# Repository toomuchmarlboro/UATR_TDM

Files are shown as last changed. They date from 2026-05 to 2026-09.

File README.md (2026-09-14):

# UATR_TDM

**16-channel 24-bit underwater acoustic acquisition — 4× ADAU1978 → Cyclone IV E → LAN8720A → fiber → 7 km subsea → host PC**

Four of these boards form the deployed array: **64 channels**, beamformed on a
single host.

---

## Status — final

The design is complete and the firmware is frozen. `rtl/top_system.vhd` as
committed is the shipping configuration, and the eight flashable images in
`output_files/` were built from it by `build_all.sh`.

| | |
|---|---|
| **Shipping build** | `C_DECIMATE = true` — **24 kHz** output, 4× on-FPGA decimation |
| **Array addressing** | `192.168.3.101–104`, host `192.168.3.10`, ports 5005–5008 |
| **Phantom power** | `C_ENABLE_48V = true`, host-gated, watchdog available but off |
| **Fit** | 3,429 / 6,272 LE (55%), 2,610 registers, 8,290 memory bits, 0 multipliers |
| **Timing** | **TNS 0.000 on every corner**; worst setup +3.528 ns (`rmii_clk`), worst hold +0.439 ns |
| **Build consistency** | `python/check_sync.py` — **58 checks passed, 0 failed** |
| **Toolchain** | Quartus Prime 25.1std Lite, EP4CE6E22C8 |

**What is proven on hardware:** all 16 channels stream clean at 96 kHz/24-bit;
the Ethernet stack in both directions (~11,950 pkt/s, zero FPGA-side sequence
gaps, FCS and IP checksum confirmed in Wireshark); ADAU1978 I²C bring-up with
every register read back byte-exact; gain and 48 V control over UDP.

**What is proven numerically:** the 24 kHz decimator — bit-exact against a
scipy reference (`sim/decim_ref_vectors.txt`), 0.00015 dB passband ripple to
11 kHz, −102.5 dB worst alias band, and structurally clean through the fitter.
Per `docs/DECIMATOR_FINDINGS.md` §5 the decimating image had not yet been
captured on the bench at the time that record was written. **On the first
capture, read the packet rate first: ~3,000/s is success, ~12,000/s means
`valid_out` is being ignored downstream.**

---

## Quick start

```powershell
# 1. Host adapter — BOTH subnets, both required while any older board is in use
netsh interface ipv4 set address name="Ethernet" static 192.168.3.10 255.255.255.0
netsh interface ipv4 add address name="Ethernet" 192.168.1.10 255.255.255.0

# 2. Let the audio in
New-NetFirewallRule -DisplayName "TDM_UATR audio" -Direction Inbound `
    -Protocol UDP -LocalPort 5005-5008 -Action Allow -Profile Private
```

```
# 3. Flash each board with its own image — the IP is baked into the bitstream
output_files/24K_NODE1_192-168-3-101.jic   ->  board 1
output_files/24K_NODE2_192-168-3-102.jic   ->  board 2
output_files/24K_NODE3_192-168-3-103.jic   ->  board 3
output_files/24K_NODE4_192-168-3-104.jic   ->  board 4

# 4. Verify
python python/discover.py     # which boards, which subnet, which rate, loss
python python/imu_test.py     # the buoy telemetry side
python python/mixer_gui.py    # live meters, faders, 48 V
```

Full procedure, including the failure modes and what each message means:
**[docs/HOST_SETUP.md](docs/HOST_SETUP.md)**.

---

## Full system pipeline

```
SUBSEA ARRAY                   TOPSIDE FPGA BOARD              TOPSIDE NETWORK
────────────────               ─────────────────────           ───────────────
                               Altera Cyclone IV E
4× ADAU1978 ADC                (minimum system, IO pins only)
  Chip 0  ch  1– 4             ┌─────────────────────────┐
  Chip 1  ch  5– 8    TDM8─A──►│ tdm8_rx A → ch_data_A   │
  Chip 2  ch  9–12    TDM8─B──►│ tdm8_rx B → ch_data_B   │
  Chip 3  ch 13–16             │ tdm16_merge             │
                               │ decimator  (96k → 24k)  │
  All chips:                   │ packet_formatter        │
  BCLK  ◄────────────────────  │ udp_tx_core             │
  LRCLK ◄────────────────────  │ crc32 / arp_responder   │
  MCLK  ◄────────────────────  │ rmii_tx ────────────────┼──► LAN8720A module
                               └─────────────────────────┘    (RMII, 100 Mbps)
                                                                    │ RJ45
                                                            Media Converter
                                                            (BiDi WDM, 1310/1550 nm)
                                                                    │
                                                         ───────────┴───────────
                                                              7 km Hybrid
                                                           Armored Subsea Cable
                                                         ───────────┬───────────
                                                                    │
                                                            Media Converter
                                                            (matched BiDi pair)
                                                                    │ RJ45
                                                                    ▼
                                                                 Host PC
                                                          (Python UDP receiver)
```

---

## System parameters

| Parameter | Value |
|---|---|
| ADC | Analog Devices ADAU1978, 40-lead LFCSP |
| Chips | 4 |
| Total channels | 16 per board (4 per chip), 64 across the array |
| Resolution | 24-bit |
| **ADC sample rate** | **96 kHz — always, both image sets** |
| **Output sample rate** | **24 kHz** (`24K_*`, shipping) or 96 kHz (`96K_*`, fallback) |
| TDM architecture | 2× TDM8 — chip pairs share one SDATAOUT wire |
| Slot width | **32 BCLK per slot**, 24-bit data left-justified, 8 pad bits |
| BCLK | **24.576 MHz** (96k × 8 slots × 32 BCLK) |
| MCLK to ADAU1978 | **24.576 MHz** (256 × 96 kHz, MCS=011) — *same net as BCLK* |
| LRCLK | 96 kHz, 1-BCLK-wide pulse (LR_MODE=1) |
| FPGA | Altera Cyclone IV E, EP4CE6E22C8, minimum system board, IO pins only |
| Board oscillator | 50 MHz |
| Ethernet PHY | LAN8720A breakout module (RMII, 100 Mbps) |
| Payload rate | 9.216 Mbps at 24 kHz, 36.864 Mbps at 96 kHz (16 ch × 24 b × fs) |
| On the wire | 11.4 Mbps at 24 kHz, 45.7 Mbps at 96 kHz — one board |
| Fiber link | Single-mode, BiDi WDM, 20 km rated |
| Subsea cable | Hybrid (power + 8× SM fiber), 7 km |
| Subsea power | 24 V topside → 2.5 mm² copper → 9 V buck subsea |
| Language | VHDL only |

---

## Shipping firmware configuration

Compile-time constants in `rtl/top_system.vhd`, as committed. Every one is
documented in place with its reasoning — this table is the index, not the
explanation.

| Constant | Value | Effect |
|---|---|---|
| `C_NODE` | `1` | Board identity. Drives MAC, IP and UDP port together. `build_all.sh` sweeps it 1–4 |
| `C_DECIMATE` | **`true`** | 96 → 24 kHz decimator in the signal path. Wire format unchanged; only the rate |
| `C_ENABLE_48V` | **`true`** | Permits 48 V phantom. Still gated on the staged power-up timer *and* the host's runtime flag |
| `C_PHANTOM_WATCHDOG` | `false` | Off on purpose — enabling it makes a host keepalive mandatory. See below |
| `C_PHANTOM_TIMEOUT_S` | `120` | Watchdog period, if ever enabled |
| `C_I2C_SWAP` | `true` | Compensates a **schematic error** — net `SCL` lands on ADAU pin 17, which is SDA. Do not "fix" without fixing the copper |
| `C_LRCLK_RETIME` | `false` | LRCLK phase-shift path built but out of the signal path — the fault it chased was hardware |
| `C_LRCLK_PHASE_PS` | `25431` | Mirror of the PLL's `clk3_phase_shift`. **Does not set the phase** — the MegaWizard does |
| `C_BUFFER_EN_ACTIVE_HIGH` | `true` | LMK1C1104 `1G` polarity, confirmed against the datasheet |
| `C_LRCLK_TEST_50PCT` | `false` | Diagnostic: drives LRCLK as a slow square so a DMM can see it |
| `C_BCLK_TEST_SLOW` | `false` | Diagnostic: drives BCLK at ~0.27 Hz so clock-tree levels read as pure DC |
| `C_TDM2_FROM_TDM1` | `false` | Diagnostic, answered 2026-08-10 — PIN_119 and `u_rx_B` are good |

`rtl/adau_sequencer.vhd`

| Constant | Value | Effect |
|---|---|---|
| `C_SOFT_RESET_FIRST` | `true` | S_RST before configuring, so the FSM initialises with clocks already stable |
| `C_VERIFY_IDX` | `0` | Which ADC the register verify reads back (0=U19, 1=U20, 2=U37, 3=U38). One part per boot |

`rtl/tdm8_rx.vhd` / `rtl/tdm16_rx.vhd`

| Constant | Value | Effect |
|---|---|---|
| `C_BIT_ADJ` | `-1` | Capture-window offset in BCLK. **Found by measurement** (`udp_monitor.py --align`), not derived. Keep both files equal |
| `C_RAW_CAPTURE` | `false` | Ships raw TDM bits instead of audio, for `rawview.py` |

### The phantom-power watchdog

`C_PHANTOM_WATCHDOG` is a fail-safe, not a convention. The host is supposed to
turn 48 V off when it shuts down, which covers an orderly restart and nothing
else — if the app crashes, the cable is pulled, or the PC loses power, the
enable flag stays set inside the FPGA and 48 V stays live on the XLRs.

It is **off by default** because turning it on makes a host keepalive
mandatory: any host that sets phantom and then goes quiet sees 48 V drop
mid-capture, which during a real deployment is worse than the hazard it
prevents. Enable it only once the host actually sends keepalives, and flash all
four boards together. Details: [docs/PHANTOM_POWER.md](docs/PHANTOM_POWER.md).

---

## Building

```bash
./build_all.sh      # 8 images: 4 nodes x {24K decimating, 96K plain}
```

The script rewrites `C_NODE` and `C_DECIMATE` in `top_system.vhd`, compiles,
converts to `.jic`, and reports LE count and TNS per build. It takes a lock:
two concurrent runs corrupt each other, because both edit the same source file
and both write `output_files/TDM_UATR.sof` — which would produce an image
labelled for one board carrying another board's IP, the exact failure the
filename convention exists to prevent.

Images are named `{rate}_NODE{n}_{ip}.jic` so a board can never be flashed with
the wrong identity by accident.

> **A `.sof` is volatile.** Power-cycling boots the `.jic` in flash instead —
> usually an older build. Power-sequencing changes cannot be tested with a
> `.sof` at all.

---

## Clock and framing

The single most important constraint on this board, and the thing that cost the
most time to find.

### MCLK and BCLK are the same net

Each LMK1C1104 output feeds one ADC's **MCLKIN (pin 7)** *and* its **BCLK
(pin 16)** through two separate 49.9 Ω resistors:

```
U2-Y2 --+-- R13 --> MCLK_1 --> U19 pin 7
        +-- R14 --> BCLK_1 --> U19 pin 16
```

So MCLK and BCLK are physically one signal. That fixes the whole configuration,
because the MCS ratio must equal the BCLK ratio:

```
BCLK = 8 slots x SLOT_WIDTH x fS        (Table 10, TDM8)
MCLK = MCS_ratio x fS                   (Table 9)
MCLK = BCLK   =>   MCS_ratio = 8 x SLOT_WIDTH
```

### Which combinations are legal

Table 10 gives TDM8 three slot widths; Table 9 gives the MCS ratios available
at each standard rate. Only where they meet is a valid configuration:

| fS | 16-bit slots (128×) | 24-bit slots (192×) | 32-bit slots (256×) |
|---|---|---|---|
| 32 kHz | 4.096 MHz | — | 8.192 MHz |
| 44.1 kHz | 5.6448 MHz | — | 11.2896 MHz |
| 48 kHz | 6.144 MHz | — | 12.288 MHz |
| **96 kHz** | 12.288 MHz | 18.432 MHz | **24.576 MHz ← used** |
| 192 kHz | 24.576 MHz | 36.864 MHz | — |

### 24-BCLK slots do not work on this part

`SLOT_WIDTH=01` (24 BCLK) is listed as legal in Table 21, and at 96 kHz it gives
exactly 18.432 MHz — which is what the board was originally designed around.
**The ADAU1978 refuses it.** Correctly configured, PLL locked, every register
reading back byte-exact, and SDATAOUT never driven.

This is not documented anywhere in the datasheet. It was found by putting one
part into **master mode** (`SAI_MS=1`, with its BCLK and LRCLK resistors lifted
so it wasn't fighting the FPGA): given free rein, the part generated **32-BCLK
slots** and drove data immediately. Switching the FPGA to match fixed it.

Contributing reasons it cannot work:

- 24-bit data in a 24-BCLK slot leaves **no room** for the I²S one-BCLK delay,
  so `SDATA_FMT` must be left-justified (`01`) rather than I²S (`00`).
- Even with left-justified framing it still refuses. The slot width itself is
  the problem.

192 × fS was retested on hardware on 2026-08-11 and rejected again. 256 × fS
stands.

### The final numbers

```
PLL c2       = 50 MHz x 1536/3125 = 24.576000 MHz   exact
frame        = 8 slots x 32 BCLK  = 256 BCLK
fS           = 24.576 MHz / 256   = 96000.0 Hz
MCS=011      = 256 x fS           = 24.576 MHz      matches MCLK
data         = 24 bit, left-justified, 8 pad bits per slot
LRCLK        = 1 BCLK wide pulse, 40.7 ns, once per 10.42 us
```

`tdm8_rx.vhd` shifts 256 bits per frame and takes the **top 24 of every 32**,
discarding the pad bits.

### PLL configuration

Single ALTPLL instance (`ip/pll_audio`), all outputs exact from 50 MHz
(3125 = 5⁵ divides cleanly, so there is no rounding anywhere):

| Output | Ratio | Frequency | Gives |
|---|---|---|---|
| c0 | 768/3125 | 12.288 MHz | 48 kHz — **do not use**, kills U37/U38 |
| c1 | 1152/3125 | 18.432 MHz | 72 kHz — working fallback |
| **c2** | **1536/3125** | **24.576 MHz** | **96 kHz — shipping** |
| c3 | — | phase-shifted LRCLK | unused (`C_LRCLK_RETIME = false`) |

Changing the rate also means changing MCS (`0x01`) and FS (`0x05`) to match.

The Ethernet side is independent: `rmii_ref_clk` comes from the PHY at 50 MHz
and the two domains meet only through `async_fifo`, which the SDC declares
asynchronous. Lowering the audio rate reduces FIFO load, never increases it.

---

## Decimation and throughput

Two builds exist from the same source, differing only in `C_DECIMATE`.

**The packet never changes size — only how often one is sent.** Every packet
carries exactly 8 audio frames at either rate:

```
                          24 kHz (24K_*)   96 kHz (96K_*)
packets per second            3,000           12,000
bytes on the wire               476              476
```

Per board:

```
payload  16 ch x 24 bit x fs         9.216 Mbit/s    36.864 Mbit/s
+ 10 B packet header                 9.840           39.360
+ eth/IP/UDP + preamble/FCS/IFG     11.424          45.696     <- on the wire
of 100BASE-TX                         11.4%           45.7%
disk  16 x fs x 3 B                  1.15 MB/s        4.6 MB/s
                                      4.1 GB/hour    16.6 GB/hour
```

Four boards:

```
aggregate                           45.696 Mbit/s  182.784 Mbit/s
                                  fits 100BASE-TX  needs GIGABIT
```

The wire figure exceeds the audio because 66 bytes of framing ride on every
packet — 410 B payload inside 476 B on the link, 86% efficiency:

```
410 B payload + 8 UDP + 20 IPv4 + 14 Ethernet = 452 B frame body
      + 4 B FCS                               = 456 B transmitted
      + 8 B preamble/SFD + 12 B inter-frame gap = 476 B of link time
```

Because that overhead is **per packet**, sending 4× fewer packets saves it 4×
over too, so the wire rate scales by exactly 4.00.

### The filter

Two cascaded halfband FIR stages, 96k → 48k → 24k. Halfband because every even
tap except the centre is exactly zero (halves the multiplies), and linear phase
because the coefficients are symmetric (halves them again).

| | Stage 1 | Stage 2 |
|---|---|---|
| Length | 27 taps | 171 taps |
| Non-zero taps | 15 | 87 |
| Rate | 96k → 48k | 48k → 24k |

20-bit coefficients, 24-bit data, 45-bit accumulator. Measured on the quantised
cascade by `python/design_decimator.py`:

```
passband ripple 0-11 kHz   0.00015 dB
worst alias band          -102.5   dB   (below the ADC's 103 dB range)
group delay                 1.91   ms
```

**Why not a CIC**, which was the original brief: the band of interest is
10 Hz – 11 kHz, which is 92% of the 12 kHz Nyquist after a ÷4 — a brick-wall
requirement. A CIC N=3 droops **−9.2 dB** at 11 kHz and puts a 13 kHz folding
tone only 4.1 dB below the signal. Raising the order makes it *worse*, because
the first null is pinned at 24 kHz. Full reasoning:
[docs/DECIMATOR_FINDINGS.md](docs/DECIMATOR_FINDINGS.md).

**Which image to use:** `24K_*` unless you need content above 11 kHz. Inside
that band it costs nothing measurable and it removes the gigabit requirement,
cuts host CPU 4× and quarters the disk rate. `96K_*` for the full 0–42 kHz the
ADC passes, or as the fallback with the longer hardware history.

> The payload is **byte-identical** at both rates and nothing in the packet
> announces which it is, so a mismatch is **silent**: WAVs play at the wrong
> pitch and every duration is out by 4×. `discover.py` measures the rate from
> the packet rate rather than assuming it; `check_sync.py` asserts the host
> constant against the RTL.

---

## Network and packet format

### Addressing (static — no DHCP)

Everything derives from `C_NODE` in `top_system.vhd`:

```vhdl
FPGA_MAC  : x"DEADBEEF00" & C_NODE      -- DE:AD:BE:EF:00:0n
FPGA_IP   : 192.168.3.(100 + C_NODE)    -- .101 .102 .103 .104
PC_IP     : 192.168.3.10                -- C_PC_IP
UDP_PORT  : 5004 + C_NODE               -- 5005 5006 5007 5008
```

`C_PC_IP` is load-bearing twice over: it is the audio destination *and* the
filter deciding whose ARP the board will learn from. Changing only the board
addresses gives four boards transmitting into nothing.

**One port per board, deliberately.** Every host tool calls `recv()`, which
discards the sender, so four boards on one port would merge four independent
sequence-number streams into one socket. And on Windows two sockets may both
bind the same UDP port with `SO_REUSEADDR` while only **one** receives.

`C_PC_MAC` is a reset default, not a fixed value — it is overwritten by
whatever ARPs the board from `C_PC_IP`. So the deployment PC works from the
first packet with no ARP round trip, and moving the array to a different host
needs no reflash, just one packet in the board's direction.

> ⚠ **The host must hold BOTH `192.168.3.10` and `192.168.1.10`** while boards
> of either generation are in use. `C_PC_IP` is one value per image, so the host
> is the side that carries both. A board on the wrong subnet does not error —
> it transmits perfectly and the host kernel discards every frame before any
> socket sees it. See [docs/HOST_SETUP.md](docs/HOST_SETUP.md) and
> [docs/CHANGING_IP.md](docs/CHANGING_IP.md).

### UDP payload — 410 bytes

Produced by `packet_formatter.vhd`. `udp_monitor.py` is the single host-side
definition of this geometry; the other tools import it.

```
Bytes  0– 3   Magic  AD A1 97 78
Bytes  4– 7   Sequence number (uint32, big-endian)
Byte      8   dbg_byte0 — SDATA_A edge count per window
Byte      9   dbg_byte1 — SDATA_B edge count per window

then 8 frames of 50 bytes each:
  Byte  0     diagnostic status byte  (frame 0 -> dbg_status,
                                       frame 1 -> dbg_status2, ... frame 7 -> dbg_status8)
  Byte  1     frame index, 0-7
  Bytes 2–49  16 channels x 24-bit signed big-endian, channel 1 first

Total payload   10 + (8 x 50)                    = 410 bytes
IPv4 total len  20 IP + 8 UDP + 410              = 438
Ethernet frame  14 + 438 + 4 FCS                 = 456 bytes transmitted
```

> **Bytes 8–9 are not a frame count.** They once carried a constant `0x0008`
> that nothing read, then ADC register readbacks that were static after boot
> and covered one part only. They now carry the raw SDATA edge counters, which
> are live and cover both TDM lines. Likewise each frame's byte 0 was the
> frame-index MSB, always zero because the index never exceeds 7; it now
> carries the I²C and power status bits.

**Byte 60** — frame 1's byte 0, `dbg_status2` — is the phantom-power readback,
at a fixed offset in every packet:

| bit | mask | meaning |
|-----|---|---|
| 7 | `0x80` | marker — byte is populated. Clear = older bitstream, ignore the rest |
| 6 | `0x40` | `en_48v` as actually driven on the pin |
| 5 | `0x20` | the host asked for it (`udp_flags` bit 0) |
| 4 | `0x10` | staged power-up passed 1000 ms |
| 3 | `0x08` | this build permits it (`C_ENABLE_48V`) |
| 2:0 | | I²C self-test, unrelated |

`EN_48V` is an FPGA **output**. There is no sense line back from the 48 V
supply — a dead DC-DC, a blown fuse or an open enable trace still reads as ON.
Do not treat it as a rail measurement.

### Control protocol (host → FPGA)

`udp_rx_core.vhd` accepts a plain UDP datagram addressed to the board's IP.
**There is no port filtering** — any port works.

| Payload byte | Meaning |
|---|---|
| `[0]` | bits [3:2] ADC select 0–3, bits [1:0] channel select 0–3 |
| `[1]` | gain byte → register `0x0A`–`0x0D` of the selected part |
| `[2]` | *optional* control flags. **bit 0 = 48 V phantom enable** |

Gain encoding (Table 25): `0x00` = +60 dB, −0.375 dB per step, `0xA0` = 0 dB,
`0xFE` = −35.625 dB, `0xFF` = mute.

> **There is no flags-only packet.** The FPGA parses one command format, so
> every gain write also says something about phantom power. Whatever your app
> attaches to routine gain commands *is* what phantom power becomes — attach
> the board's own readback, not a default. `mixer_gui.py` does this in
> `flags()`, so a fader move is phantom-neutral.

```
python python/ctrl.py --test --channel 3     prove the receive path
python python/ctrl.py --set 3 -6             one channel to -6 dB
python python/ctrl.py --all 0                every channel to 0 dB
python python/ctrl.py --phantom status       decode byte 60
python python/mixer_gui.py                   live meters + faders + phantom
```

✅ **Verified on hardware 2026-08-09.** `ctrl.py --test --channel 1`: baseline
RMS 373 → mute 0.0 → restore 466. The FPGA parsed a UDP datagram from the PC
and wrote the gain register over I²C. Ethernet is proven in both directions.

---

## ADAU1978 configuration

### Register settings

Written by `adau_sequencer.vhd`. Every field is checked against the datasheet
by `check_sync.py` on each build.

| Reg | Value | Description |
|-----|---|---|
| 0x01 | `0x03` | PLL_MUTE=0, CLK_S=0 (MCLKIN), **MCS=011 = 256 × fS** (Table 9, fS=96 row) |
| 0x04 | `0x3F` | LR_POL=0, BCLKEDGE=0 (data on falling BCLK), LDO+VREF+all 4 ADCs enabled |
| 0x05 | `0x5B` | SDATA_FMT=01 (**left justified**), SAI=011 (TDM8), FS=011 (64–96 kHz) |
| 0x06 | `0x08` | SLOT_WIDTH=00 (**32 BCLK/slot**), DATA_WIDTH=0 (24 b), LR_MODE=1 (pulse), SAI_MS=0 (slave) |
| 0x07 | `0x10` | Chips 0, 2: ch1→slot1, ch2→slot2 |
| 0x07 | `0x54` | Chips 1, 3: ch1→slot5, ch2→slot6 |
| 0x08 | `0x32` | Chips 0, 2: ch3→slot3, ch4→slot4 |
| 0x08 | `0x76` | Chips 1, 3: ch3→slot7, ch4→slot8 |
| 0x09 | `0xF8` | All 4 ch drive enabled, DRV_HIZ=1 (unused slots high-Z) |
| 0x00 | `0x01` | PWUP=1 — **write last, only after PLL_LOCK bit = 1** |

### I²C addresses

| Chip | ADDR1 | ADDR0 | Address |
|---|---|---|---|
| 0 (U19) | 0 | 0 | 0x11 |
| 1 (U20) | 0 | 1 | 0x31 |
| 2 (U37) | 1 | 0 | 0x51 |
| 3 (U38) | 1 | 1 | 0x71 |

### Power-up sequence

```
1. Apply 3.3V AVDD. Hold PD/RST LOW.
2. Assert PD/RST HIGH -> internal LDO charges DVDD.
3. Wait ~5 ms (DVDD > 1.2V, POR releases, safe margin).
4. Apply stable 24.576 MHz MCLK (FPGA must be running).
5. Wait 15 ms for PLL to lock.
6. Poll register 0x01 bit 7 (PLL_LOCK) until = 1.
7. Write registers: 0x04, 0x05, 0x06, 0x07, 0x08, 0x09.
8. Settle 30 ms, then write register 0x00 = 0x01 (PWUP). LAST.
```

Boot is two-pass: configure everything, settle, then PWUP. The datasheet
requires PWUP be asserted ≥10 ms after DVDD > 1.2 V with stable clocks.

### Per-chip hardware requirements

- **PLL_FILT (pin 3):** 1 kΩ + 5.6 nF + 390 pF — mandatory
- **VREF (pin 2):** 100 nF + 10 µF to GND
- **DVDD (pin 10):** 100 nF + 10 µF MLCC X7R to GND
- **AVDD1/2/3:** 100 nF + 10 µF bulk per pin
- **Exposed pad (EP):** must be soldered to the PCB ground plane
- **IOVDD:** match to FPGA IO bank voltage (3.3 V)
- **47 kΩ pull-down** on each SDATAOUT line to GND

---

## Hardware details

### ADAU1978 chip pairing and slot assignment

```
Stream A wire:  Chip 0  ch  1– 4  → TDM slots 1–4
                Chip 1  ch  5– 8  → TDM slots 5–8

Stream B wire:  Chip 2  ch  9–12  → TDM slots 1–4
                Chip 3  ch 13–16  → TDM slots 5–8
```

```
FPGA output         Signal                Destination
───────────         ──────                ───────────
mclk_out            24.576 MHz            all 4× MCLKIN
bclk_out            24.576 MHz            all 4× BCLK
lrclk_out           96 kHz pulse          all 4× LRCLK

FPGA input          Source
──────────          ──────
sdata_in_A          Chip 0 SDATAOUT1 + Chip 1 SDATAOUT1  (47 kΩ pull-down)
sdata_in_B          Chip 2 SDATAOUT1 + Chip 3 SDATAOUT1  (47 kΩ pull-down)
```

### TDM frame structure

```
LRCLK:   |‾|__________________________________|‾|__
          1 BCLK wide pulse — marks start of slot 1

BCLK:    256 cycles per frame  (8 slots × 32 BCLK, 24-bit data + 8 pad bits)

sdata_in_A:
[Chip0 ch1:24b][Chip0 ch2:24b][Chip0 ch3:24b][Chip0 ch4:24b]  slots 1–4
[Chip1 ch1:24b][Chip1 ch2:24b][Chip1 ch3:24b][Chip1 ch4:24b]  slots 5–8

sdata_in_B: identical structure for Chips 2 and 3
```

- ADAU1978 outputs data on the **falling BCLK edge** (max 18 ns delay)
- FPGA samples on the **rising BCLK edge**
- LRCLK is *sampled* on the BCLK **rising** edge regardless of BCLKEDGE, so
  `tdm8_master` must **launch** it on the falling edge — asserted by `check_sync.py`
- Left-justified: first audio bit valid on the BCLK cycle after the LRCLK pulse

### Receiver output layout (per instance)

```
ch_data[191:168]  ch 1    ch_data[95:72]   ch 5
ch_data[167:144]  ch 2    ch_data[71:48]   ch 6
ch_data[143:120]  ch 3    ch_data[47:24]   ch 7
ch_data[119:96]   ch 4    ch_data[23:0]    ch 8
```

### LAN8720A module wiring

| Module Pin | Signal | Direction | Notes |
|---|---|---|---|
| VCC / GND | 3.3 V | — | Module power |
| RST# | `rmii_rst_n` | FPGA → PHY | Assert LOW at startup, release HIGH |
| MDC | `rmii_mdc` | FPGA → PHY | ~2.5 MHz management clock |
| MDIO | `rmii_mdio` | Bidirectional | 10 kΩ pull-up to 3.3 V |
| REF_CLK | `rmii_ref_clk` | PHY → FPGA | 50 MHz — see note |
| TXD0/TXD1 | `rmii_txd[1:0]` | FPGA → PHY | |
| TX_EN | `rmii_tx_en` | FPGA → PHY | |
| RXD0/RXD1 | `rmii_rxd[1:0]` | PHY → FPGA | Required — the control path uses them |
| CRS_DV | `rmii_crs_dv` | PHY → FPGA | |

> **REF_CLK note:** these modules carry an onboard 50 MHz crystal, and that is
> the clock the RMII domain runs on here. Check your specific module before
> wiring.

### Subsea cable and fiber link

| Parameter | Value |
|---|---|
| Cable type | Hybrid power + fiber, HDPE marine grade + aramid yarn |
| Conductors | 2× 2.5 mm² XLPE copper |
| Fiber count | 8× singlemode in stainless steel loose tube |
| Fiber used for data | 1 (BiDi WDM — single fiber, full duplex) |
| Cable OD | 18 mm ±0.5 mm |
| MBL | 1500 kg, working load 500 kg |
| Link budget at 7 km | ~3.45 dB loss, ~15 dB margin |

> **BiDi pair requirement:** the two converters must be a matched pair — one TX
> at 1310 nm, the other TX at 1550 nm. Verify before deployment.

### Subsea power delivery

```
2.5 mm² copper, 7 km round trip resistance = ~96.3 Ω
At 100 mA load: voltage drop = 9.63 V

Supply 24 V topside -> ~14.4 V arrives at the subsea end
Subsea: 9 V buck regulator (e.g. LM2596) powers the media converter
```

---

## Architecture decisions

**2× TDM8 rather than TDM16 or 4× TDM4.** TDM8 needs only two data wires and
gives symmetric 8-channel receivers. 4× TDM4 works and has the lowest BCLK but
wastes four input pins. TDM16 on one wire was built and tested
(`output_files/96K_TDM16.jic`) and **reverted**: timing analysis showed the
capture path was never the fault, so merging all four parts onto one net would
only have traded 24-bit samples for 16-bit. The procedure is kept in
[docs/TDM16_BRINGUP.md](docs/TDM16_BRINGUP.md) in case it is revisited.

**LAN8720A rather than W5100/W5500.** W5100 is SPI-based at max ~0.44 MB/s —
10× below what is needed. W5500 at ~10 MB/s is adequate but adds SPI overhead
and latency. LAN8720A speaks RMII directly to fabric with no intermediate
bottleneck.

**100 Mbps rather than gigabit.** With the decimator, one board offers
11.4 Mbit/s and the whole four-board array 45.7 Mbit/s — comfortably inside
100BASE-TX. Gigabit would require RGMII: more pins, harder timing, no benefit.

**UDP rather than TCP.** Audio is loss-tolerant and latency-sensitive. TCP
retransmits cause variable delay; a dropped UDP packet is one frame of missing
audio that the host detects from the sequence number.

**Fiber rather than copper at 7 km.** 100BASE-TX reaches 100 m. The subsea
cable already carries singlemode fiber and the converters are rated to 20 km.

**BiDi WDM rather than dual fiber.** TX and RX share one fiber at different
wavelengths, consuming one core of eight and leaving seven spare.

**GZIP compression in the FPGA was evaluated and rejected** — see
[HOST_DSP_PIPELINE.md](HOST_DSP_PIPELINE.md).

---

## Multi-board deployment and host DSP

The deployed array is **4 boards = 64 channels**, beamformed on a single host.
With the decimating build that is 45.7 Mbit/s aggregate and 12,000 pkt/s, which
fits 100BASE-TX; the 96 kHz build's 182.9 Mbit/s does not.

Host-side handling of the aggregate is specified in
**[HOST_DSP_PIPELINE.md](HOST_DSP_PIPELINE.md)**, including the
FLAC storage path and the **inter-board sample-alignment problem, which remains
open** — the four boards free-run from their own oscillators and nothing
currently disciplines them to a common timebase. `discover.py` flags mixed
sample rates for the same reason: each board is fine on its own and they are
not aligned to each other.

---

## Repository layout

```
rtl/        Synthesizable VHDL — everything in TDM_UATR.qsf's VHDL_FILE list
ip/         ALTPLL / FIFO IP cores, one directory per .qip (self-contained)
sim/        Testbenches, modelsim.ini, wave.do, decimator reference vectors
python/     Host-side tools (Python 3)
hardware/   Schematic PDF and KiCad netlist export
docs/       Findings and procedures, referenced from this README
db/, incremental_db/, output_files/   Quartus build output — gitignored
```

`TDM_UATR.qpf` / `.qsf` / `.sdc` stay at the repository root so the project
opens in Quartus by double-clicking the `.qpf`. Every source reference is a path
relative to the project root — no fixed drive letters.

### RTL

| File | Description |
|---|---|
| `top_system.vhd` | Top level. Clock/reset, staged power-up, I²C open-drain buffers, TX arbiter, all build-option constants |
| `tdm8_master.vhd` | Generates LRCLK (1 BCLK pulse @ 96 kHz) from 24.576 MHz |
| `tdm8_rx.vhd` | TDM8 receiver — 264-bit shift register (256-BCLK frame + `C_BIT_ADJ` slack), latch on LRCLK. Instantiated twice |
| `tdm16_merge.vhd` | Merges the two TDM8 streams into 16 channels |
| `tdm16_rx.vhd` | Single-net 16-slot receiver, built for the TDM16 experiment — not in the active path |
| `decimator.vhd` | Two-stage halfband FIR, 96 → 24 kHz, 16 channels time-multiplexed |
| `decim_coef_pkg.vhd` | Generated coefficients and tap indices — regenerate with `design_decimator.py` |
| `i2c_master.vhd` | I²C master. Bus recovery, probe mode, repeated-START reads |
| `adau_sequencer.vhd` | 128-address scan, soft reset, register boot, two-pass PWUP, live PLL poll, runtime gain writes |
| `crc32.vhd` | Ethernet FCS (0x04C11DB7) |
| `rmii_tx.vhd` / `rmii_rx.vhd` | RMII MAC — preamble, data, FCS, IFG |
| `udp_tx_core.vhd` | Ethernet + IP + UDP headers, 452-byte frame body |
| `udp_rx_core.vhd` | UDP receive path — gain and flags control |
| `arp_responder.vhd` | ARP replies, and learns the host MAC |
| `packet_formatter.vhd` | 10-byte header + 8 × 50-byte frames = 410-byte payload |
| `net_pkg.vhd` | Shared network constants |
| `ip/pll_audio` | ALTPLL: 50 MHz → 24.576 MHz |
| `ip/async_fifo` | Clock-domain crossing, 24.576 MHz → 50 MHz |

### Host tools (`python/`)

**Audio**

| File | Description |
|---|---|
| `discover.py` | **Start here.** Passive — finds every board, reports its real subnet, measured rate, and loss. Transmits nothing |
| `udp_monitor.py` | One-shot capture: link rate, loss, per-channel statistics, `--wav`, `--align`. The single definition of the packet geometry |
| `mixer_gui.py` | **Live tkinter mixer** — 16 meters, gain faders, mute, 48 V, telemetry tab, follows each board's real address |
| `mixer_gui_standalone.py` | The whole GUI in one file. **Generated — do not edit** |
| `make_gui_standalone.py` | Generates the above with `ast`. `--check` fails if it is stale |
| `mixer.py` | The same meters in the terminal |
| `ctrl.py` | Control protocol, phantom decode, and `--test` |
| `timeline.py` | Reports channel dropout windows over a capture |
| `rawview.py` | Decodes `tdm8_rx`'s raw-capture debug mode, bit for bit |

**Verification**

| File | Description |
|---|---|
| `check_sync.py` | Cross-checks the host constants against the RTL **and** the datasheet tables. 58 assertions — run on every build |
| `design_decimator.py` | Designs the filter, generates `decim_coef_pkg.vhd` and `sim/decim_ref_vectors.txt`, and reports ripple and alias rejection |
| `sim_chain.py` | Cycle-accurate model of the TDM chain, used to settle `C_BIT_ADJ` without a licensed simulator |
| `i2c_scan.py` | Decodes the boot-time I²C diagnostics: bus health, 128-address sweep, per-part table, register verify |

**Buoy telemetry**

| File | Description |
|---|---|
| `gdat2.py` | `$GDAT2` serial telemetry — see [docs/GDAT2_TELEMETRY.md](docs/GDAT2_TELEMETRY.md) |
| `witmotion.py` | WitMotion IMU/AHRS client |
| `ping1d.py` | Ping1D altimeter client |
| `altimeter_probe.py` | Altimeter bring-up probe |
| `imu_test.py` | Proves the AHRS is *live*, not merely present — catches an unchanging-constant or all-zero field map |
| `imu_standalone.py` | The same check as one self-contained stdlib file |
| `test_RMI.py` | Buoy integration test |

### Testbenches (`sim/`, not in the synthesis hierarchy)

| File | Description |
|---|---|
| `tb_tdm8_rx.vhd` | Known pattern, frame assertions |
| `tb_tdm16.vhd` | 16-channel merge |
| `tb_chain.vhd` | Full chain |
| `decim_ref_vectors.txt` | Bit-exact decimator reference output |

```
vlib work
vcom -modelsimini sim/modelsim.ini -work work -2002 rtl/tdm8_master.vhd rtl/tdm8_rx.vhd rtl/tdm16_merge.vhd sim/tb_tdm16.vhd
vsim -modelsimini sim/modelsim.ini -do sim/wave.do work.tb_tdm16
```

`-modelsimini sim/modelsim.ini` points at the tracked library mapping —
ModelSim otherwise resolves `modelsim.ini` from the current directory and
silently falls back to the install default.

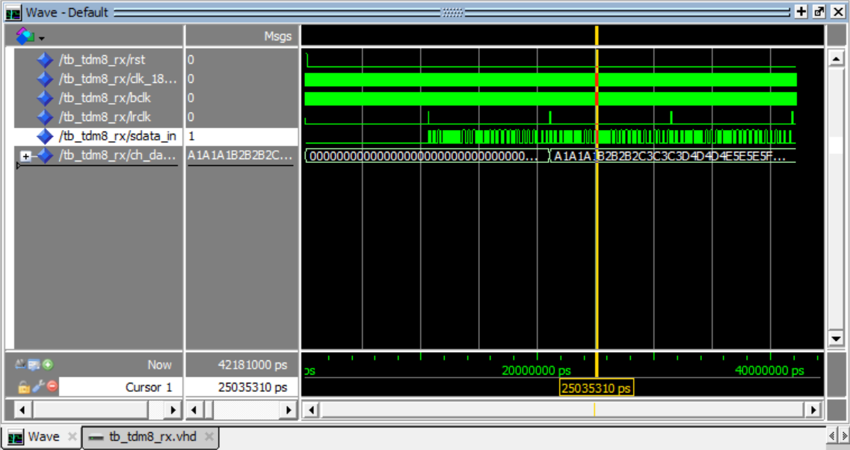
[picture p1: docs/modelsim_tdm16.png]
ModelSim TDM16 waveform


### Documentation (`docs/`)

**Procedures**

| File | Description |
|---|---|
| `HOST_SETUP.md` | **The complete host procedure** — adapter, firewall, which `.jic` to flash, verifying audio and telemetry |
| `DECIMATION.md` | The 96→24 kHz decimator, and the ADC gain budget that goes with it |
| `CHANGING_IP.md` | Changing the array's addressing — the four things that must agree |
| `NETWORK_SETUP.md` | Why the network is arranged this way: capacity, collisions, Python limits |

**Reference**

| File | Description |
|---|---|
| `ETHERNET_TRANSMISSION.md` | The UDP/IP/Ethernet transmit path end to end |
| `MULTI_BOARD.md` | Four-board deployment |
| `PHANTOM_POWER.md` | 48 V control, readback and the optional watchdog |
| `TELEMETRY_INTEGRATION.md` | The three buoy sensors and how to lift them into an app |
| `GDAT2_TELEMETRY.md` | `$GDAT2` field map, and the AHRS quantisation trap |

**Findings**

| File | Description |
|---|---|
| `DECIMATOR_FINDINGS.md` | Design decisions, and every bug found building the decimator |
| `TDM16_BRINGUP.md` | TDM16 procedure and why it was reverted |
| `LRCLK_HOLD_VIOLATION.md` | The ~4 ns LRCLK hold-spec violation |
| `LRCLK_PHASE_SHIFT.md` | The phase-shift investigation — intact but out of the signal path |
| `TDM2_NETLIST_FINDINGS.md` | Netlist trace of the LMK1C1104 buffer fan-out |

---

## Hardware bring-up log

Findings from bringing up the Souncard_Robomarine 1.0 PCB. Recorded because
none of it is derivable from the RTL. **All are resolved**; they are kept
because the next board revision needs them.

### Schematic errors

| Error | Impact | Resolution |
|---|---|---|
| **SDA/SCL crossed** — net `SCL` wires to ADAU pin 17 (really SDA), net `SDA` to pin 18 (really SCL). The KiCad symbol is correct; the wiring is not | I²C could never work as drawn | Compensated in firmware by `C_I2C_SWAP = true`. **Fix the copper in the next revision** |
| **OPA1671 on +15 V** — U44–U47 (VREF→VCOM buffers) have V+ on +15 V against a **6 V absolute maximum** | Destroyed all four. Their damaged inputs clamped VREF to 0–0.8 V on every ADC and loaded the ±15 V rail | **Removed, not replaced.** OPA1632 `VOCM` self-biases to mid-rail, which is correct on ±15 V, and the ADC inputs are AC-coupled — the buffers were never needed. **Delete them in the next revision** |
| **PLL loop filter returns to GND**, not AVDD2 as Table 8 requires | None observed | Disproven as a fault — U19/U37 lock with the GND return. Component values are correct |
| **Both LMK1C1104 clock buffers (U1, U2) damaged** | Their inputs loaded the FPGA's 3.3 V outputs to 2.0 V and their outputs produced 0.9 V and millivolts. The ADAU1978 needs VIH = 0.7 × IOVDD = 2.31 V, so the ADCs never saw a valid clock and left SDATAOUT high-Z | Replaced. Can also be bypassed by bridging pin 1 to pins 3/5/7/8 on each footprint — the FPGA drives these loads directly; the 49.9 Ω series resistors stay |
| **Misplaced DVDD decoupling cap, and a dead U37** | The intermittent ADC3/ADC4 channel dropouts | Fixed in hardware. All 16 channels now run clean |

### Firmware bugs

- **`i2c_master.vhd`** — `ena` was sampled only on quarter-bit boundaries while
  the sequencer pulsed it for one cycle, so the pulse was missed ~99% of the
  time. **No I²C transaction had ever run.**
- **`crc32.vhd`** — 7 of the 32 XOR equations (bits 10, 11, 12, 16, 17, 22, 23)
  carried spurious terms, so every frame left with a garbage FCS and the host
  NIC discarded all of it silently. **Root cause of the original "Ethernet
  dead" fault.** Verified after the fix: `"123456789"` → `0x649C2FD3`, RX
  residue `0xC704DD7B`.
- **False PLL-lock reporting** — `i2c_master` pre-loads `data_rd` with `0xFF`
  to invalidate aborted reads. The live poll took bit 7 of that blindly, so a
  *failed* read reported `PLL_LOCK = 1`. It reported four locked PLLs on a
  board whose MCLK never arrived.
- **TDM framing** — the merge fired 128×/frame, and LRCLK was launched on the
  ADC's own sampling edge.
- **Scan abort** — the address sweep stopped at 9 answers, collapsing "hard
  stuck-low SDA" (128 answers) and "a few glitched bits" (9) onto one number.
  It now always sweeps all 128.
- **Decimator pipeline misalignment** — survived one round of "bit-exact"
  verification because the model encoded the *intent* rather than the written
  VHDL. Caught only by a cycle-accurate model following VHDL signal semantics.

### Measurement traps

- **LRCLK is a 54 ns pulse at 96 kHz** — 0.5% duty, so a *working* LRCLK reads
  **~17 mV** on a multimeter. Use `C_LRCLK_TEST_50PCT`, or a scope.
- **24 MHz on a handheld DMM** reads as a meaningless fraction of a volt.
  MCLK/BCLK cannot be checked with a meter at all. Use `C_BCLK_TEST_SLOW`.
- **Scope frequency counters quantise.** An 18.432 MHz clock (54.25 ns) on a
  100 MSa/s timebase alternates between "20 MHz" and "16.6 MHz". Both readings
  are the same correct clock.
- **Resistance to GND across bulk capacitance is meaningless** — the meter
  charges the cap and the reading climbs. A rail also reads "shorted" on a
  continuity beeper because of the substrate diodes in every IC on it; reverse
  the probes and the asymmetry gives it away.

### Standing lessons

1. **Model what you wrote, not what you meant.**
2. **A passing check may be checking nothing** — two `check_sync.py` guards had
   been green for weeks while matching no text at all.
3. **Cheap in one resource is expensive in another** — padding a RAM depth cost
   zero LEs and broke the fit on memory blocks.
4. **Generated files must be executed, not just generated.**
5. **Never `git checkout` a file mid-session to reset unrelated state.**

---

## Minimal host receiver

```python
import socket, struct

MAGIC = b'\xAD\xA1\x97\x78'
sock  = socket.socket(socket.AF_INET, socket.SOCK_DGRAM)
sock.bind(("0.0.0.0", 5005))                 # 5004 + C_NODE
sock.setsockopt(socket.SOL_SOCKET, socket.SO_RCVBUF, 4 * 1024 * 1024)

prev_seq = None
while True:
    data, _ = sock.recvfrom(65535)
    if len(data) != 410 or data[0:4] != MAGIC:
        continue
    seq = struct.unpack(">I", data[4:8])[0]
    if prev_seq is not None and seq != prev_seq + 1:
        print("WARNING: %d packet(s) dropped" % (seq - prev_seq - 1))
    prev_seq = seq

    phantom_on = bool(data[60] & 0x40) if data[60] & 0x80 else None

    offset = 10
    for f in range(8):                        # 8 frames per packet, both rates
        samples = [int.from_bytes(data[offset+2+i*3 : offset+5+i*3],
                                  'big', signed=True) for i in range(16)]
        offset += 50
        # samples[0..15] = ch1..ch16
```

---

## Constraints

- VHDL only — no Verilog or SystemVerilog
- Cyclone IV E only — no Cyclone V or later features
- `rtl/top_system.vhd` is the only top level
- `rtl/tdm8_rx.vhd` is complete and instantiated twice — do not rewrite
- All FPGA IO pins are 3.3 V — the LAN8720A IOVCC must also be 3.3 V
- UDP checksum is 0x0000 (valid per RFC 768)
- The sample rate is **not** announced in the packet. Any tool that assumes it
  must be told, and `check_sync.py` must be run after flashing a different image

---

## License

MIT — see [LICENSE](LICENSE). Copyright (c) 2026 Faiz Akbar Parinduri, S.T.

This covers the VHDL in `rtl/`, the host tools in `python/`, the testbenches in
`sim/`, and the documentation. It does **not** cover third-party material
redistributed here for convenience:

- `ip/pll_audio` and `ip/async_fifo` are Altera/Intel megafunction output,
  governed by the Quartus Prime license under which they were generated
- `docs/adau1978.pdf` is the Analog Devices datasheet, © Analog Devices
- `hardware/` contains the Souncard_Robomarine 1.0 schematic and netlist

---

*Analog Devices ADAU1978 Rev B. Microchip LAN8720A. Altera Cyclone IV E
EP4CE6E22C8. Built with Quartus Prime 25.1std Lite.*

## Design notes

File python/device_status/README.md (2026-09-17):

# Device Status — vendored from HACAR_dash

HACAR_dash's Device Status window, copied whole into this repo so the valve
control can be added to it. PySide6, which is a third GUI toolkit here
alongside `mixer_gui.py` (tkinter) and `Host_RMI.py` (PyQt5).

```powershell
python run.py                    # all tabs, live services
python run.py --no-services      # the bare window, opens no sockets
python run.py --db bench.sqlite  # a settings database of your own
```

## What is here

| | |
|---|---|
| `supersilence/` | **Vendored. Do not edit.** 78 files, ~14,700 lines |
| `vendor.py` | Copies that tree out of HACAR_dash, and checks it is current |
| `run.py` | Composes the services and opens the window, mirroring `app/main.py` |

## The tabs

- **Buoys** — the AFE pages. One sub-tab per unit (T1–T4), each carrying
  sixteen channel meters, gain faders, channel enable and polarity, and the
  48 V phantom control.
- **Telemetry** — decoded `$GDAT2` fields per unit, link statistics, compass
  and horizon.
- **Pipeline** — needs a `target_provider`, which is the console's
  direction-finding stack. Not vendored, so this tab never appears here.

A tab is built only when the service behind it exists. That is the window's own
design, and deliberate — its comment reads *"a tab of ten dashes says a field
map is broken when the truth is that telemetry is switched off"*. `--no-services`
therefore shows "No acquisition or telemetry service is running.", which is the
window working, not a fault.

## Keeping the copy honest

`supersilence/` is generated, for the same reason `mixer_gui_standalone.py` is:
a hand-maintained copy of another project's source drifts silently — the window
still opens, still paints, and still shows numbers, just not the ones the other
repo now produces.

```powershell
python vendor.py            # refresh from HACAR_dash
python vendor.py --check    # exit 1 if stale, and name the files
python vendor.py --list     # what is in the closure, and how big
```

The source defaults to `../../../HACAR_dash/src` — a sibling checkout — and is
overridden with `--src` or `$SUPERSILENCE_SRC`. `--check` passes quietly when the
source is absent, so this repo stays buildable on a machine that has never had
HACAR_dash on it.

### What gets copied

The transitive import closure of four seeds, computed with `ast` rather than
swept up by a wildcard: the `device_status` feature, the acquisition factory,
the telemetry service, the settings repository, the SQLite schema and the
phantom-power command path. Nothing else from that repo comes along.

Package paths are preserved, so every `from supersilence.… import …` inside the
copied files is left exactly as written. That is why `run.py` puts its own
directory on `sys.path` and why the tree is not flattened the way the mixer GUI
is flattened.

## Addresses

These are **HACAR_dash's** defaults, not this array's. Its acquisition sources
and the `192.168.3.101–104` boards in `ctrl.py` are configured independently,
and nothing here rewrites one to match the other — a window that silently
retargeted the addresses in its own database would be the least debuggable
thing in either repo. Set them in the settings database, or point `--db` at one
that already holds them.

Telemetry also ships disabled: `default_telemetry_configuration()` has
`enabled=False`, so a fresh database connects to nothing until you turn it on.

## Next

The valve control goes on the Buoys page beside the 48 V control — the one
other place this window reaches past a service and into hardware. The command
itself already exists in this repo as `gdat2.rmcmd`, with `RMCMD_OPEN = 5` and
`RMCMD_CLOSE = 1`.

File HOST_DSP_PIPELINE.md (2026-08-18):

# Host DSP Pipeline — Decimate /4 + FLAC

**Status (2026-08-16): design agreed, not yet implemented.**

Reduces the 4-AFE aggregate stream from 70.8 GB/hr to ~9 GB/hr and cuts beamforming
cost 4×, entirely on the host. **No RTL, no PLL, no ADAU1978 register changes.**

---

## The Problem

Four AFEs, each 16 ch × 96 kHz × 24-bit, feeding one Python beamformer.

| | Per AFE | ×4 aggregate |
|---|---|---|
| Wire rate | 45.7 Mbps | 182.9 Mbps = **22.9 MB/s** |
| UDP payload | 4.9 MB/s | 19.7 MB/s |
| Audio samples | 4.6 MB/s | **18.4 MB/s** |
| Packet rate | 12,000 pkt/s | **48,000 pkt/s** |
| Storage | 17.7 GB/hr | **70.8 GB/hr** (566 GB / 8 hr) |

Note the units: **46 Mbps per AFE, not MB/s**. At 22.9 MB/s aggregate, a 1 GbE server
port sits at 18% and any SSD is bored. Neither network nor disk *bandwidth* is the
bottleneck. The two real constraints are **host CPU** and **storage capacity**.

---

## Architecture Decisions Log

### Why not the FPGA-Gzip-compressor core

Evaluated [WangXuan95/FPGA-Gzip-compressor](https://github.com/WangXuan95/FPGA-Gzip-compressor)
and rejected on three independent grounds.

**1. It does not fit EP4CE6E22C8.** Published cost is 8,218 LUT6 + 25×BRAM36K on
Artix-7. Our device has 6,272 LE and 276,480 memory bits, with `TDM_UATR.fit.summary`
already showing 3,890 LE (62%) used — about 2,380 LE free. Ignoring Xilinx block
quantization and counting only irreducible storage:

| Item | Bits | % of device M9K pool |
|---|---|---|
| LZ77 window (16,383 B) | 131,064 | 47% |
| Hash table (4,096 entries) | ~57,000 | 21% |
| Deflate block buffer | 131,064 | 47% |
| **Total** | | **~115%** |

Over 100% of all device RAM before the existing 8,688 bits. Logic is worse: 8,218 LUT6
maps to roughly 12k–18k Cyclone IV 4-LUTs against 2,380 free. Off by 3–7×, not a tuning
margin. (Throughput was never the issue — 128 MB/s vs the 4.6 MB/s needed.)

**2. It would break the TX path.** `udp_tx_core.vhd:59` — `IP_CHECKSUM` is a
compile-time constant *precisely because* the length is fixed at 438. Variable-length
output makes IP total-length, UDP length and the checksum runtime logic, and invalidates
`PAYLOAD_BYTES := 410` and the `byte_cnt = TOTAL_BYTES` terminator.

**3. It is the wrong operation for the problem.** See below.

### Why decimation and not compression alone

Compressed data cannot be beamformed. It must be inflated back to 96 kHz × 64 ch first,
at which point the beamformer sees the identical array it sees today — same FFTs, same
delay-and-sum, same cost, plus the decode.

| | Compression (FLAC) | Decimation /4 |
|---|---|---|
| What is removed | statistical redundancy | the 12–48 kHz band |
| Reversible | yes, exactly | **no, never** |
| Output directly usable | no — must decode | yes — plain PCM |
| Reduces storage | yes | yes |
| **Reduces beamform CPU** | **no — adds decode cost** | **yes, exactly 4×** |
| Ratio | data-dependent | exactly 4×, guaranteed |

Beamforming cost scales as `N_samples × N_channels × N_beams`. Compression changes none
of those three. Decimation cuts the first by 4.

**They are orthogonal and compose.** Decimate first, then compress the result — low-pass
filtering raises sample-to-sample correlation, so FLAC's linear predictor typically does
*better* on decimated data than on the original.

| Approach | Storage | Beamform CPU |
|---|---|---|
| Now | 70.8 GB/hr | 1× |
| FLAC only | ~35 GB/hr | 1× + decode |
| Decimate /4 only | 17.7 GB/hr | 0.25× |
| **Decimate /4, then FLAC** | **~9 GB/hr** | **0.25×** |

### Why /4 and not some other factor

Advisor guidance was 22 kHz *frekuensi sampling* (sampling frequency, i.e. ~11 kHz of
usable band) for speech-band work. 96/22 is not an integer and fractional resampling is
far more expensive than integer, so:

| Decimate | Fs | Usable band | Reduction |
|---|---|---|---|
| /2 | 48 kHz | 24 kHz | 2× |
| /3 | 32 kHz | 16 kHz | 3× |
| **/4** | **24 kHz** | **12 kHz** | **4×** |
| /6 | 16 kHz | 8 kHz | 6× |

/4 gives 12 kHz of band — slightly more headroom than the 11 kHz asked for — on a clean
integer divisor.

Spatial-aliasing cross-check: for a 12 kHz band, `d ≤ c/(2·f_max) = 1500/24000 = 6.25 cm`
element spacing. **If hydrophone spacing ≤ 6.25 cm, /4 costs nothing usable.** If spacing
is wider, the array was already the limiting factor and the stream can be decimated
harder. *This has not been confirmed — see Open Items.*

### Why on the host and not in the FPGA

A time-multiplexed FIR decimator would fit (a few hundred LE, and there are 256 BCLKs per
audio frame at 24.576 MHz = 16 cycles per channel per sample). It would also cut network
and packet rate, which the host version does not.

It is still the wrong place to start. The clock tree on this board is demonstrably fussy:
commit `a4ba519` records 192×fS (18.432 MHz) *rejected on hardware*, and `tdm8_rx.vhd:27`
records the part reading `PLL_LOCK=0` at 18.4332 MHz while all four locked at 24.576 MHz.
Host-side decimation delivers 4× on both stated problems while `clk_18m` stays bolted to
PLL tap c2 and `adau_sequencer` never sees a changed MCS value.

Revisit the FPGA decimator only if packet rate or link load becomes the binding
constraint. It is not today.

### Naming hazard

`clk_18m` in `top_system.vhd` **carries 24.576 MHz**, not 18.432 MHz. It is wired to PLL
output c2 (`top_system.vhd:923-925`); the 18.432 MHz tap c1 is `open`. The name is legacy
from before 192×fS was rejected. Renaming it to `clk_bclk` or `clk_24m576` is a mechanical
change and would stop this recurring.

---

## Pipeline

```
  4× AFE (UDP :5005)                HOST
  ──────────────────                ────
  16 ch @ 96 kHz 24-bit
  12,000 pkt/s each      ┌──────────────────────────────────┐
        │                │ 1. INGEST (one process per AFE)  │
        ├───────────────►│    vectorized parse, seq-gap     │
        │                │    detect + zero-fill            │
        │                └───────────────┬──────────────────┘
        │                                │ (n,16) int32 @ 96 kHz
        │                ┌───────────────▼──────────────────┐
        │                │ 2. INTER-AFE ALIGNMENT           │
        │                │    MUST be at 96 kHz — see below │
        │                └───────────────┬──────────────────┘
        │                                │ aligned, 64 ch @ 96 kHz
        │                ┌───────────────▼──────────────────┐
        │                │ 3. ANTI-ALIAS FIR + /4 SUBSAMPLE │
        │                │    stateful, block-continuous    │
        │                │    one Decimator per AFE         │
        │                └───────────────┬──────────────────┘
        │                                │ (n/4,16) int32 @ 24 kHz
        │                     ┌──────────┴──────────┐
        │                     ▼                     ▼
        │          ┌────────────────────┐  ┌──────────────────┐
        │          │ 4a. BEAMFORMER     │  │ 4b. FLAC WRITER  │
        └─────────►│     64 ch working  │  │  8 files × 8 ch  │
                   │     set, 0.25× CPU │  │  ~9 GB/hr total  │
                   └────────────────────┘  └──────────────────┘
```

---

## Stage 1 — Ingest

**This is the current bottleneck and must be fixed first, independently of decimation.**

`udp_monitor.py:97-105` decodes with a nested Python loop calling `int.from_bytes` once
per sample: 48,000 pkt/s × 128 samples = **6.1M calls/s**, plus 48,000 `recv()` syscalls/s.
That cannot keep up at any data rate.

The correct vectorized pattern **already exists in this repo** at `mixer.py:78-83`:

```python
def decode(payload):
    """Payload bytes -> (frames, 16) int32."""
    body = payload[um.HDR_LEN:]
    n = len(body) // um.FRAME_LEN
    if n == 0:
        return None
    raw = np.frombuffer(body[:n * um.FRAME_LEN], dtype=np.uint8)
    raw = raw.reshape(n, um.FRAME_LEN)[:, 2:]          # drop debug + frame index
    raw = raw.reshape(n, um.CHANNELS, um.SAMPLE_BYTES).astype(np.int32)
    v = (raw[:, :, 0] << 16) | (raw[:, :, 1] << 8) | raw[:, :, 2]
    return np.where(v & 0x800000, v - 0x1000000, v)
```

Port this into the record/beamform path. Expect 50–100× on the parse.

**Syscall side:** `recvmmsg` is not in Python's stdlib `socket`, so the practical levers
are (a) one receiver process per AFE, and (b) larger packets in the FPGA. Raising
`packet_formatter` from 8 to 29 frames/packet (1460 B payload, still inside MTU) cuts
48,000 → 13,240 pkt/s. That is a small, well-understood RTL change and is worth more here
than its ~8% wire saving. Optional; not required for this pipeline.

**Sequence gaps are mandatory to handle.** Header bytes 4–7 carry `seq_num`
(`packet_formatter.vhd:90-93`). A dropped packet must be **zero-filled, not skipped** — a
skipped packet shifts every subsequent sample by 8 frames, which silently destroys both
the decimation phase and inter-channel beamforming alignment. Log gap count and location.

---

## Stage 2 — Inter-AFE alignment (must precede decimation)

The four AFEs run independent `pll_audio` instances from independent crystals, so their
sample grids drift relative to each other. Beamforming across AFEs requires them aligned
to a common grid.

**This stage must run at 96 kHz, before decimation.** The alignment granularity available
from integer sample shifts collapses when you decimate:

| Rate | 1 sample | Apparent element position error @ 1500 m/s |
|---|---|---|
| 96 kHz | 10.4 µs | **1.6 cm** |
| 24 kHz | 41.7 µs | **6.25 cm** — the entire assumed element spacing |

At 24 kHz a single-sample shift is as large as the array spacing the /4 decision was
justified against, so after decimation the AFEs **cannot be aligned by integer shifts at
all** — recovering what one sample buys at 96 kHz would require fractional-delay
interpolation. Align first, then decimate.

Consequence for stage 3: each AFE gets **its own `Decimator` instance**, fed from an
already-aligned stream. The class below is sized per channel count, not per AFE.

The alignment mechanism itself is unresolved — see Open Item 4. It is the one item on
this page that can invalidate the beamformer regardless of how well the DSP works.

---

## Stage 3 — Anti-alias filter and /4 subsample

### The filter is not optional

Naïve `x[::4]` folds everything between 12 kHz and 48 kHz back into the retained band as
false signal that is indistinguishable from real targets. The stream **must** be low-passed
below the new 12 kHz Nyquist first.

### Specification

| Parameter | Value | Rationale |
|---|---|---|
| Input Fs | 96,000 Hz | unchanged from ADC |
| Output Fs | 24,000 Hz | |
| Passband | 0 – 10,000 Hz | |
| Stopband | 12,000 Hz | new Nyquist |
| Stopband atten. | ≥ 100 dB | below the ~102 dB ADAU1978 DR floor |
| Phase | linear (FIR) | preserves inter-channel timing — **required for beamforming** |

**Use FIR, not IIR.** An IIR low-pass has non-linear phase, which applies a
frequency-dependent delay. Across a beamforming array that is indistinguishable from a
position error and will smear the beam pattern.

### Streaming structure

Block-based `resample_poly` / `decimate` calls do **not** maintain filter state, so each
block boundary injects a discontinuity. For a continuous recording that is unacceptable.
Carry state explicitly:

```python
from scipy.signal import firwin, lfilter
import numpy as np

DECIM   = 4
FS_IN   = 96000
FS_OUT  = FS_IN // DECIM          # 24000
NTAPS   = 321                     # odd -> integer group delay

# Kaiser-windowed FIR, ~100 dB stopband, 10 kHz -> 12 kHz transition.
# beta = 0.1102*(A - 8.7) = 10.06 for A = 100 dB; cutoff is the -6 dB point,
# i.e. the centre of the transition band. NTAPS from (A-8)/(2.285*dw) = 308 -> 321.
FIR = firwin(NTAPS, cutoff=11000, fs=FS_IN, window=('kaiser', 10.06))

class Decimator:
    """Stateful /4 with anti-alias FIR. Block-continuous, no edge artifacts."""
    def __init__(self, n_ch, taps=FIR, decim=DECIM):
        self.b = taps
        self.decim = decim
        self.zi = np.zeros((len(taps) - 1, n_ch))
        self.phase = 0                       # subsample phase across blocks

    def __call__(self, x):                   # x: (n, n_ch) float64
        y, self.zi = lfilter(self.b, 1.0, x, axis=0, zi=self.zi)
        out = y[self.phase::self.decim]
        # keep phase continuous into the next block
        self.phase = (self.phase - len(x)) % self.decim
        return out
```

`self.phase` is what makes this correct across blocks — without it, a block whose length
is not a multiple of 4 shifts the decimation grid and the channels drift apart.

### Cost, and the optimization if it does not keep up

Single-stage `lfilter` computes every input sample then discards 3 of 4:
`321 taps × 64 ch × 96,000 = 1.97 GMAC/s`. That is likely too slow for single-threaded
scipy. **Benchmark before assuming it works.**

If it does not, use a **two-stage halfband cascade** (/2 at 96 kHz, then /2 at 48 kHz).
Halfband filters have every other tap zero, and the second stage runs at half rate:

| Stage | Rate | Taps | Effective MAC/s (64 ch) |
|---|---|---|---|
| 1 (/2) | 96 kHz | 63 (32 non-zero) | ~98 M |
| 2 (/2) | 48 kHz | 63 (32 non-zero) | ~49 M |
| **Total** | | | **~150 M** — 13× cheaper |

Combined with polyphase evaluation (compute only retained outputs, via `upfirdn` with
manual state), this comfortably fits one core per AFE.

### Back to integer — do not skip the clip

`lfilter` returns float64; FLAC needs integers. A 321-tap FIR has passband ripple and can
overshoot a full-scale input past ±(2²³−1). An unchecked `.astype(np.int32)` truncates
toward zero and, worse, wraps silently on overflow — a full-scale positive peak becomes a
large negative sample. Clip explicitly:

```python
out = np.clip(np.rint(y_float), -(1 << 23), (1 << 23) - 1).astype(np.int32)
```

`np.rint` (round-half-even) rather than a bare cast, so the decimated stream is not biased
toward zero by up to 1 LSB on every sample.

---

## Stage 4b — FLAC writer

### Channel count constraint

**FLAC's format caps at 8 channels.** libFLAC, libsndfile and `soundfile` all enforce it.
64 channels cannot go in one file.

Natural split — **8 files of 8 channels**, two per AFE, matching the existing `tdm8_rx`
A/B halves and the ADAU1978 chip pairing in the README:

| File | AFE | Channels | Source |
|---|---|---|---|
| `afe0_A.flac` | 0 | 1–8 | `ch_data_A` (chips 0,1) |
| `afe0_B.flac` | 0 | 9–16 | `ch_data_B` (chips 2,3) |
| … | | | |
| `afe3_B.flac` | 3 | 9–16 | `ch_data_B` (chips 2,3) |

This keeps a file boundary on a boundary that already exists in the hardware.

### Settings

| Parameter | Value |
|---|---|
| Sample rate | 24,000 Hz |
| Bit depth | 24-bit (`PCM_24`) |
| Channels | 8 per file |
| Compression level | 5 (default) — level 8 costs much more CPU for ~1% |

```python
import soundfile as sf

w = sf.SoundFile(path, mode='w', samplerate=FS_OUT,
                 channels=8, subtype='PCM_24', format='FLAC')
w.write(block_int32)     # (n, 8) — SEE SCALING NOTE BELOW
```

### ⚠ Verify the int24 → int32 scaling before the soak test

**Unresolved: `soundfile` is not installed on this machine, so this was not tested.**

libsndfile's `sf_writef_int` may treat an int32 input array as **full-scale int32**, in
which case a 24-bit sample must be shifted `<< 8` before writing. If that is the case and
the shift is omitted, the recording lands **~48 dB below** where you think it is — quiet
but otherwise plausible-looking, which is exactly the kind of bug that survives a casual
listen and corrupts every level measurement downstream.

Settle it with a two-line discriminator before writing any real data:

```python
import numpy as np, soundfile as sf
v = 1 << 22
sf.write('t.flac', np.full((100, 8), v, dtype='int32'), 24000,
         subtype='PCM_24', format='FLAC')
print(hex(int(sf.read('t.flac', dtype='int32')[0][0, 0])))
# 0x400000  -> int24 convention, write as-is
# 0x40000000 -> full-scale int32 convention, shift << 8 on write
```

Validation item 4 (round-trip) will catch this, but it surfaces as a bit-exactness
failure rather than a level error, which is a confusing way to find it. Check it first.

Run the writer **off the ingest path** — separate process or thread with a bounded queue.
A blocked disk write must never stall the socket reader. Bound the queue and count drops
rather than growing memory without limit.

### Expected sizes

| Stage | Rate | Per hour |
|---|---|---|
| Raw 96 kHz 24-bit, 64 ch | 18.4 MB/s | 66.3 GB |
| After /4 | 4.6 MB/s | 16.6 GB |
| After /4 + FLAC (~50%) | ~2.3 MB/s | **~9 GB** |

FLAC ratio is signal-dependent and **has not been measured** — see Open Items.

---

## Validation

Before trusting the pipeline:

1. **Decimation correctness** — feed a synthetic 1 kHz tone at 96 kHz, confirm it appears
   at 1 kHz in the 24 kHz output at the same amplitude.
2. **Alias rejection** — feed an 18 kHz tone (inside the discarded band). It must be
   attenuated ≥ 100 dB, **not** appear as a 6 kHz artifact. This is the test that catches
   a missing or misconfigured anti-alias filter.
3. **Block continuity** — decimate a long ramp in blocks of deliberately non-multiple-of-4
   length (e.g. 1000, 999, 1001). Output must be identical to the same input decimated in
   one call. Catches `phase` and `zi` handling errors.
4. **FLAC round-trip** — write and read back, assert bit-exact against the input array.
   FLAC is lossless; anything else means a subtype or scaling bug.
5. **Inter-channel phase** — same tone into two channels with a known delay; confirm the
   delay survives decimation unchanged. This is what protects the beam pattern.
6. **No overflow wrap** — full-scale square wave in. FIR passband ripple overshoots
   ±(2²³−1); confirm the output clips rather than wrapping to large negative values.
7. **FLAC scaling** — the `1 << 22` discriminator above, run before anything else in
   this list.
8. **Sustained-rate soak** — 1 hour with all four AFEs live. Zero sequence gaps attributable
   to the host, bounded queue depth, storage rate matching the table above.

---

## Open Items

**1. Irreversibility of recording decimated-only.** Once the 12–48 kHz band is discarded
before recording, it is gone permanently. This is the requested design and the numbers
above assume it. Flagging it because it is a one-way door: if anything of interest to UATR
lives above 12 kHz (propeller cavitation and some DEMON analyses can), it cannot be
recovered later. **Suggested mitigation:** during the validation phase, record a full-rate
FLAC archive in parallel (~35 GB/hr) and confirm from real data that the 12–48 kHz band is
empty before committing to decimated-only recording.

**2. Hydrophone element spacing is unconfirmed.** The /4 choice assumes ≤ 6.25 cm. Confirm
against the actual array geometry.

**3. FLAC ratio is unmeasured.** `_raw.bin` is a decompressed PDF stream of the ADAU1978
datasheet, and both `Wireshark/*.pcapng` are dead-silent on every channel (constant
`0xFFFFFF` on ch 0–7, `0x000000` on ch 8–15; they predate the 4-ADC bringup). The ~50%
figure is a general expectation for hydrophone data, not a measurement of this system.
**A 10-second live capture with all four AFEs running would settle both this and Open
Item 2.**

**4. Inter-AFE sample alignment — the highest-risk item on this page.** Each AFE runs its
own `pll_audio` from its own crystal: four independent, drifting time bases. One sample of
skew at 96 kHz is 10.4 µs ≈ **1.6 cm of apparent element position error** at 1500 m/s, and
it accumulates over a run.

This is not merely orthogonal to the decimator — it **constrains the pipeline order**, which
is why it now has its own stage (Stage 2). Alignment must happen at 96 kHz, because at
24 kHz one sample is 6.25 cm, equal to the entire element spacing the /4 factor was
justified against.

Two things must be determined:

- **Is there shared MCLK/LRCLK distribution between AFEs, or any sync mechanism?**
  `top_system.vhd:304` notes MCLK and BCLK share a net *within* one board (pin 113 → U2
  fanout). Whether anything ties the four boards together is unknown from this repo.
- **If not, what is the measured drift rate?** Two AFEs recording the same acoustic event
  will show a slowly growing offset; that rate sets how often re-alignment is needed and
  whether a free-running arrangement is viable at all.

No amount of data-rate work matters if the four streams cannot be aligned. Resolve this
before or alongside the decimator.

**5. Stale constant.** `udp_monitor.py:38` — `EXPECTED_PPS = SAMPLE_RATE / FRAMES_PKT`
carries the comment `# 6000 at 48 kHz`. `SAMPLE_RATE` is 96000, so the value is 12000.
The arithmetic is right; the comment is stale.

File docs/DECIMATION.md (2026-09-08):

# 96 kHz → 24 kHz decimation, and the gain budget that goes with it

Written 2026-09-07. Covers two independent changes that came out of the same
conversation:

1. **Set the ADC PGA.** A runtime change, no rebuild, worth ~24 dB of SNR that
   is currently being thrown away. Do this first — it is free.
2. **Move the 4× decimation onto the FPGA.** Cuts the uplink 4×, which takes the
   four-board array from *needs gigabit* to *fits in 100BASE-TX*.

They are unrelated in the hardware and can be done in either order. The gain
setting is reversible in seconds; the decimator is a build.

---

## Part 1 — The gain budget

### The chain as built

```
hydrophone  -173 dBV re 1 uPa
    |
THAT1512 preamp, +12 dB          on the PCB
    |
OPA1632 differential driver
    |
ADAU1978, PGA 0 to +60 dB        register 0x0A-0x0D, gain = 60 - 0.375 x N
    |                            103 dB dynamic range typ (109 max)
24-bit sample
```

### The numbers

Ambient ocean noise at sea state 2, integrated over 10 Hz – 11 kHz, is about
100 dB re 1 µPa. Through a −173 dBV element that is:

```
signal at element          -73.1 dBV  =  221 uV
+12 dB THAT1512            -61.1 dBV
ADC full scale (2 V rms)     6.0 dBV
                           ---------
level at converter         -67.1 dBFS
```

Now compare the two noise sources that matter:

```
THAT1512 input noise  ~1.3 nV/rtHz x sqrt(11 kHz) = 136 nV = -137 dBV
  x12 dB, referred to ADC full scale                       = -131 dBFS
ADAU1978 noise floor (103 dB dynamic range)                = -103 dBFS
                                                             --------
the converter is noisier than the analog chain by            ~28 dB
```

**The THAT1512 is doing its job — it is quiet enough that the converter cannot
see how quiet it is.** With the PGA at its default the system is limited by the
ADC, not by the preamp or the sea, and roughly 28 dB of achievable SNR is going
unused.

### What to set

The PGA sits *after* the preamp and *before* the converter's noise, so raising
it lifts the signal above the ADC floor without amplifying that floor.

| PGA | byte | level at ADC | headroom above ambient | penalty |
|---|---|---|---|---|
| 0 dB (default) | `0xA0` | −67 dBFS | 67 dB | wasting ~28 dB |
| **+24 dB** | **`0x60`** | **−43 dBFS** | **43 dB** | **~1 dB — start here** |
| +30 dB | `0x50` | −37 dBFS | 37 dB | ~0.5 dB |

```
python python/ctrl.py --node 1 --all 0x60
```

Runtime, over the existing UDP control path, no rebuild. Encoding is
`gain = 60 − 0.375 × N` (`rtl/adau_sequencer.vhd:159`).

**+24 dB is the recommended starting point** — it captures nearly all the
available SNR while keeping 43 dB of headroom for vessel transients, which run
well above ambient.

Then check `clip seen:` in `udp_monitor.py`. `ASDC_CLIP` (0x19) is polled
continuously (`adau_sequencer.vhd:230`) and surfaced in `dbg_status6`, so it
reports immediately if a setting is too hot. Back off one step if it trips on
transients rather than continuously.

### Two things to verify

- **Source impedance.** The THAT1512 is a bipolar-input mic preamp designed for
  ~150 Ω sources: low voltage noise, but meaningful *current* noise, which
  becomes voltage across a high source impedance. If the hydrophone is a bare
  piezo element (capacitive, high-Z at low frequencies) rather than one with an
  integral buffer, current noise may dominate below a few hundred Hz and the
  figures above are optimistic at the bottom of the band. Worth knowing the
  element's output impedance before trusting the 10 Hz end.
- **The 10 Hz end itself.** Nothing in the decimation path affects it. It is set
  by the input AC-coupling (C304 etc.) and the ADAU1978's HPF setting. Confirm
  10 Hz actually survives to the ADC output before designing around it.

### No analog anti-alias filter

The THAT1512 is wideband (MHz) and passes everything to the converter. All
anti-alias protection above 48 kHz is therefore the ADAU1978's own decimator:
**79 dB stop-band attenuation, stopband from 0.5625 × fS = 54 kHz**
(`docs/adau1978.pdf` p.4). That is adequate for what is known to be up there,
but it means there is no analog filter in the chain — worth confirming whether
any RC network exists ahead of the OPA1632.

### The altimeter question, settled

Each buoy carries a Blue Robotics Ping1D altimeter pinging at **115 kHz, every
50 ms** (`docs/TELEMETRY_INTEGRATION.md:146`). It is not connected to the FPGA,
but that is not why it is harmless — it is an acoustic source in the same water
as the hydrophones, and coupling would be acoustic, not electrical.

Nor is "we don't listen that high" protective: sampling at 96 kHz folds 115 kHz
to |115 − 96| = 19 kHz, and the ÷4 would fold 19 kHz to **5 kHz**, mid-band.
Being far above the band of interest is exactly the condition that produces
aliasing.

**It is nonetheless a non-issue**, because 115 kHz sits well inside the
ADAU1978's stopband and is crushed by that 79 dB *inside the converter*, before
the FPGA sees anything. Combined with a downward-beaming transducer and
hydrophones that roll off above their design band, there is nothing to fix.

Recorded because the mechanism matters: a future sensor operating *below*
42 kHz would sit in the ADC's passband and get no such protection.

Cheap confirmation, if wanted: coupling would appear as transients at exactly
20 Hz (the 50 ms ping interval) in `udp_monitor.py`'s glitch detection.

---

## Part 2 — The decimator

### Why not a CIC

A CIC (cascaded integrator-comb) is the obvious multiplier-free choice and it
**does not work for this band**. At N=3, R=4, fS=96 kHz:

| frequency | role | response |
|---|---|---|
| 11 kHz | top of the band of interest | **−9.2 dB** droop |
| 13 kHz | folds onto 11 kHz | **−13.3 dB** |

A 13 kHz tone would land on top of the 11 kHz signal only **4.1 dB below it**.
Raising the order makes it worse, not better — N=5 gives −15.3 dB of droop at
11 kHz. The CIC's first null is pinned at 24 kHz and no choice of N moves the
transition down to 11 kHz.

CIC is the right answer for a narrow band (it would be fine for 100–1500 Hz).
**11 kHz out of a 12 kHz Nyquist is 92% of the band — a brick-wall requirement,
and a CIC is the bluntest filter there is.**

And plain sample-dropping is worse still: discarding 3 of every 4 samples with
no filter folds everything from 13 kHz to 42 kHz into the band at **full
amplitude, 0 dB rejection**. The ADAU1978 passes content to 42 kHz
(0.4375 × fS), so that energy genuinely is present.

### What is built instead

Two cascaded **halfband FIR** stages, 96k → 48k → 24k. Halfband because every
even tap except the centre is exactly zero (halving the multiplies), and linear
phase because the coefficients are symmetric (halving them again).

| stage | rate | length | non-zero | folded taps (multiplies/output) |
|---|---|---|---|---|
| 1 | 96 → 48 kHz | 27 | 15 | 8 @ 48 kHz |
| 2 | 48 → 24 kHz | 171 | 87 | 44 @ 24 kHz |

Lengths were chosen by exhaustive search over (n, beta) for the cheapest pair
still meeting the ripple and alias limits. Do not hand-tune them: shortening
either stage breaks the alias limit, and lengthening costs cycles the schedule
has budgeted.

Coefficients are 20-bit signed, generated by `python/design_decimator.py` into
`rtl/decim_coef_pkg.vhd`.

### Measured response

Verified on the quantised cascade, not the float design:

```
passband ripple 0-11 kHz      0.00015 dB      (limit 0.01)
droop at 11 kHz              -0.0001  dB
worst alias band             -102.5   dB      (limit -100)
at 12 kHz (output Nyquist)     -6.0   dB
at 13 kHz                    -120.3   dB
group delay                     1.91  ms
```

**−102 dB of alias rejection sits below the ADAU1978's own 103 dB dynamic
range**, so aliased content lands under the converter's noise floor and cannot
degrade anything, whatever is actually up there. This is why no spectrum
measurement was needed to size the filter — designing to the noise floor is
assumption-free, and the headroom made the optimisation not worth a bench
session.

Passband droop of 0.0001 dB means **no compensation FIR is needed**. That was
flagged as an open question; it is answered.

### Built and fitted — measured, not estimated

Quartus 25.1std, `EP4CE6E22C8`, all four node images:

```
Total logic elements   5,308-5,343 / 6,272  (85%)   24K images
                       3,429-3,455 / 6,272  (55%)   96K images
Dedicated registers          3,603 / 6,272  (57%)
Embedded multipliers            14 / 30     (47%)
Total memory bits          164,194 / 276,480 (59%)
Design-wide TNS       0.0 on setup, hold, recovery, removal, min pulse width
```

Worst-case setup slack is +3.643 ns on `rmii_clk`, the pre-existing Ethernet
path, unchanged by this work. The decimator costs ~1,880 LEs, which is the
measured difference between the two image sets.

> ⚠ **SignalTap had to be removed from the QSF to make this fit.**
> `ENABLE_SIGNALTAP` was `ON` with `signaltap_rmii.stp`, and its capture buffer
> was consuming M9K blocks the decimator needs. It is a debug instrument, not
> part of the design, and it should not have been in deployment images anyway —
> but be aware the four 96 kHz NODE images were built *with* it. Re-enabling it
> will break the fit while `C_DECIMATE` is true.

#### Three things the fit taught that the paper design did not

1. **`mod` on a non-power-of-two synthesises a hardware divider.** `D2` was
   briefly 192, and `mod D2` produced two `lpm_divide` instances — **282 LEs**
   of real divider. The wrap is now a conditional subtract. Never write `mod`
   on these address paths.
2. **Memory BLOCKS bind before memory BITS.** At 24-bit width an M9K holds only
   256 words, so the design can exhaust all 30 blocks while showing 60% bit
   utilisation. Padding `D2` from 171 to 256 costs nothing in LEs and costs 11
   extra M9K — it broke the fit.
3. **Quartus duplicates a RAM that needs two reads plus a write**, whether or
   not you ask it to. Two reads + one write does not map to one M9K's two
   ports, so `ram2` became `ram2_rtl_0` and `ram2_rtl_1` automatically. The
   duplication is unavoidable; what matters is keeping its depth exact.

### Resources, against a device that is already 64% full

The shipping build (`output_files/TDM_UATR.fit.summary`) uses:

```
logic elements   4,025 / 6,272  (64%)
registers        3,047
multipliers          0 / 30     (0%)     <- completely unused
memory bits      8,674 / 276,480 (3%)
```

The decimator is therefore built as **one time-multiplexed core, not 16 parallel
instances.** `tdm16_valid` fires once per audio frame in the 24.576 MHz
`clk_18m` domain — **256 clock cycles between samples** — so there is ample time
to sequence all 16 channels through shared arithmetic.

```
two independent engines, one multiplier and one deadline each:
  engine 1  fires every 2 frames ( 512 cyc)  uses 144  ->  28%
  engine 2  fires every 4 frames (1024 cyc)  uses 720  ->  70%

multipliers   2 of 30   (14 of 30 nine-bit elements)
delay RAM     ram1 duplicated (2R+1W), ram2 single true-dual-port
coeff ROM     52 x 20 bit
accumulator   sum(|coef|) x max|data|, exact   =  45 bits

Both engines are PIPELINED, one tap per cycle. An ADDR/MAC two-state loop costs
two cycles per tap and puts engine 2 at 1,440 cycles - over its deadline, where
e2_go pulses are missed and output frames vanish silently. See
docs/DECIMATOR_FINDINGS.md section 3.2.
```

**Sixteen parallel instances would not fit.** At 30-bit accumulators a parallel
CIC alone needs ~274 flip-flops per channel — 4,384 registers against 6,272
total, of which 3,047 are already used. Cyclone IV E has one flip-flop per LE
and no LUT-based distributed RAM, so every array lands in M9K regardless. The
time-multiplexed form spends the multipliers and M9K blocks that are sitting
idle instead of the LEs that are nearly gone.

### Where it goes

`tdm16_merge` emits a **flat 384-bit parallel register** with a one-cycle strobe
(`rtl/tdm16_merge.vhd:65`), and `packet_formatter` consumes exactly that. So the
decimator is a **drop-in with identical ports on both sides**, spliced between
`u_merge` and `u_fmt` at `rtl/top_system.vhd:1396-1410`.

No slot decoder or encoder is needed — the merged bus is already a parallel
snapshot of all 16 channels, not a serial TDM stream.

Channel alignment is preserved for free: `tdm16_merge.vhd:28-40` documents that
A and B are captured on the same clock edge from the same LRCLK chain, so all 16
channels are mutually aligned by construction. One shared decimator schedule
keeps them that way — which is what GCC-PHAT cross-correlation needs.

> ⚠ **Naming collision.** "TDM16" means two different things in this repo.
> `tdm16_merge` is active and shipping. `tdm16_rx` is a *board-level* config
> putting all four ADCs on one SDATA net at 16-bit — **not active**, and it
> requires fitting the R21/R122 jumper (`docs/TDM16_BRINGUP.md`). The decimator
> concerns the former only. Do not fit the jumper.

### What it buys

```
                      per board      four boards
now (96 kHz)          45.7 Mbit/s    182.8 Mbit/s   <- needs gigabit
after 4x decimation   11.4 Mbit/s     45.7 Mbit/s   <- fits 100BASE-TX
+ max-MTU packing     10.1 Mbit/s     40.5 Mbit/s
```

This removes the gigabit requirement documented in `docs/MULTI_BOARD.md`
("That does not fit in 100BASE-TX. The switch uplink and the PC NIC must be
gigabit"), which matters given the 7 km fiber and media converters.

Packet rate drops from ~12,000/s to ~3,000/s, which matters more than the
bandwidth — host-side packet rate is the usual real bottleneck.

---

## Part 3 — Verification without ModelSim

`docs/MULTI_BOARD.md` records that **there is no simulator licence on this
machine**, which is why `top_system.vhd` carries static concurrent assertions
that Quartus evaluates at elaboration and fails the build on.

`python/design_decimator.py` is built around that constraint. The same script
that designs the coefficients also emits a **bit-exact fixed-point reference
model** of the output, into `sim/decim_ref_vectors.txt`. Because coefficients
and reference come from one file, they cannot drift apart.

```
python python/design_decimator.py           design, verify, write outputs
python python/design_decimator.py --check   verify only, exit 1 on regression
python python/design_decimator.py --plot    also write the response PNG
```

`--check` is the regression gate: it re-measures ripple and alias rejection
against the stated limits and fails if a coefficient edit breaks them. It is a
natural addition to whatever runs `check_sync.py`.

Test cases in the vector file: impulse (exercises the full impulse response),
full-scale DC (overflow), tones at 1 kHz / 11 kHz (passband edge) / 13 kHz and
19 kHz (stopband and the fold-down case), and full-scale noise.

### The integration bug to watch for

`valid_out` pulses at 24 kHz, not 96 kHz. Everything downstream must **wait for
the strobe** rather than assume a sample is present every frame. This is the
single most common CIC/FIR decimator integration bug, and here it would present
as a packet rate 4× too high with repeated samples — a symptom this project has
seen before, from the `tdm16_merge` level-versus-edge bug fixed in `927aac7`.

---

## Part 4 — Transport: UDP is already the right choice

Asked and answered, recorded so it is not re-litigated:

| option | verdict |
|---|---|
| **UDP (current)** | **Correct. Keep it.** |
| TCP | Not feasible on this FPGA (connection state, retransmit buffers, congestion control) and *wrong* for continuous acquisition — head-of-line blocking turns one lost packet into a multi-ms stall of the whole stream |
| Raw Ethernet L2 | Saves 28 bytes (~6%), costs raw sockets, admin rights, npcap on Windows, and all existing tooling. Not worth it |
| AES67 / Dante / AVB-TSN | Buys interoperability and PTP clock sync that a closed point-to-point link where you own both ends does not need. PTP hardware timestamping alone would dwarf the decimator |
| RTP over UDP | 12 bytes for standard-tooling compatibility. The `AD A1 97 78` magic + 32-bit sequence number already do the essential job. Only worth it for off-the-shelf receivers like GStreamer |

### The remaining win is packet size, not protocol

```
now (8 frames/pkt):    410 B payload in 476 B on wire  ->  86% efficient, 3000 pkt/s
max MTU (28 frames):  1410 B payload in 1476 B on wire ->  95% efficient,  857 pkt/s
```

Another ~11% off the wire and a 3.5× drop in packet rate, for 1.17 ms of
buffering instead of 0.33 ms.

> ⚠ The README warns about exactly this: *"Changing the payload size requires the
> IPv4 total length, UDP length, FIFO terminator, packet parser, and
> checksum-related checks to be updated together."* Do it as its own commit, not
> bundled with the decimator.

---

## Part 5 — Data quality under packet loss

### The invariant that matters most

**A lost packet must be replaced, not skipped.** If the host concatenates only
what arrives, every subsequent sample shifts earlier. At 24 kHz one lost 8-frame
packet shifts everything by 333 µs — **50 cm of acoustic path** at 1500 m/s,
permanently and cumulatively. For bearing work that is fatal.

The README already specifies gap-filling rather than shifting, and
`loss_report()` (`python/udp_monitor.py:112`) detects gaps from the sequence
number. Keep that invariant rigid in any new host code.

### Mark gaps, do not merely fill them

Zero-fill (with a short fade to avoid a broadband click) preserves timing;
hold-last-value does not — a held DC step is a wideband transient that smears a
correlation. Better still, carry a per-window "contains fabricated samples" flag
so GCC-PHAT can **exclude** those windows rather than correlate on invented
data. A bearing computed from zero-fill is worse than no bearing.

### Where loss actually comes from here

On a dedicated point-to-point path (FPGA → media converter → 7 km fiber →
converter → NIC) with no competing traffic, wire loss is essentially zero —
7 km of SM fiber at BER 1e-12 is roughly one FCS-dropped frame per day. The
README reports **zero FPGA-side sequence gaps**.

So in practice "packet loss" here means **host socket buffer overflow**, and
`udp_monitor.py:445` already says so in its own diagnostics.

**Which makes decimation the single best loss-resilience change available** — it
cuts bandwidth, packet rate and host CPU load 4× at once. `SO_RCVBUF` is already
at 64 MB (`udp_monitor.py:46`), so the host side is otherwise well built.

### If measured loss turns out non-zero

XOR FEC is the FPGA-friendly answer: one parity packet per N data packets
(parity = XOR of all N payloads) makes any single loss in a group exactly
recoverable, for a 410-byte accumulator and an XOR. Cost is 1/N bandwidth
(N=8 → 12.5%), affordable at 45.7 Mbit/s aggregate.

**Do not build it speculatively — measure first.**

Retransmission via the existing `udp_rx_core` back-channel is technically
possible but would need ~60% of M9K for the replay buffer, competing directly
with the decimator's delay lines. Not worth it.

---

## Order of work

1. **Set the PGA to `0x60`** — runtime, no rebuild, ~24 dB of SNR. Check
   `clip seen:` after.
2. **Confirm the source-impedance and 10 Hz questions** in Part 1.
3. **Build the decimator** — coefficients already generated; splice between
   `u_merge` and `u_fmt`.
4. **Resize packets toward max MTU** — separate commit.
5. **XOR FEC only if measured loss is non-zero.**

## The four images

Built with `C_DECIMATE = true`. `C_NODE` is the only per-board edit.

| node | IP | UDP port | image |
|---|---|---|---|
| 1 | 192.168.3.101 | 5005 | `output_files/24K_NODE1_192-168-3-101.jic` |
| 2 | 192.168.3.102 | 5006 | `output_files/24K_NODE2_192-168-3-102.jic` |
| 3 | 192.168.3.103 | 5007 | `output_files/24K_NODE3_192-168-3-103.jic` |
| 4 | 192.168.3.104 | 5008 | `output_files/24K_NODE4_192-168-3-104.jic` |

The matching non-decimating set is `96K_NODE*_192-168-3-10*.jic`, same
addresses, 96 kHz. Host setup for either: `docs/HOST_SETUP.md`.

The older `*_192-168-1-*` images are the pre-migration set and send to
`192.168.1.10`; see `docs/CHANGING_IP.md` before mixing them in.

**Flash and verify one board at a time**, per `docs/MULTI_BOARD.md` — check the
number in the filename against the board actually connected, then `ping`,
`arp -a` to confirm the MAC, then capture. Four near-identical images is exactly
the situation where the wrong one lands on the wrong board, and the symptom
looks like a network fault rather than a flashing mistake.

### What to expect on the first capture

| check | 96 kHz (before) | 24 kHz (after) |
|---|---|---|
| packet rate | ~12,000/s | **~3,000/s** |
| per-board wire rate | 45.7 Mbit/s | **11.4 Mbit/s** |
| packet layout | 410 B, unchanged | 410 B, unchanged |
| byte-60 phantom readback | works | works |

**A packet rate of ~12,000/s with the decimating image means `valid_out` is
being ignored somewhere downstream** — that is the integration bug described
above, not a filter problem.

Host scripts need their sample-rate constant changed from 96000 to 24000 for
WAV writing and any seconds-from-packet-count arithmetic. The wire format is
otherwise identical, so nothing else moves.

### Not yet done

- **Nothing has been on hardware.** The design is verified in simulation-free
  form only: numerically against scipy, and structurally by Quartus. The
  reference vectors exist precisely so the first capture can be diffed rather
  than eyeballed.
- `python/check_sync.py` does not yet know about the decimator. It cross-checks
  host constants against the RTL and would be the natural place to assert that
  the host sample rate matches `C_DECIMATE`.

## Files

- `python/design_decimator.py` — designs, verifies, and emits everything below
- `rtl/decimator.vhd` — the two-engine time-multiplexed implementation
- `rtl/decim_coef_pkg.vhd` — generated coefficient package, do not hand-edit
- `sim/decim_ref_vectors.txt` — generated bit-exact reference vectors
- `docs/decimator_response.png` — generated response plot

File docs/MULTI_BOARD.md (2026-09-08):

# Running four boards

> **PARTLY SUPERSEDED, 2026-09-08.** The addresses below are the pre-migration
> `192.168.1.x` set. The array is now on `192.168.3.x` and there are two image
> variants (96 kHz and 24 kHz decimating). For current addressing and host
> configuration read **`docs/HOST_SETUP.md`**; for the decimator read
> `docs/DECIMATION.md`.
>
> Everything else here still applies: why one UDP port per board, the ARP and
> checksum reasoning, the bandwidth arithmetic, and the cross-board timing
> section at the end.

Four soundcards, 16 channels each, all streaming to one host.

Everything per-board derives from **one integer**, `C_NODE` in `rtl/top_system.vhd`.
Building the image for board 3 means changing that and nothing else.

| node | MAC | IP | UDP port | image |
|---|---|---|---|---|
| 1 | `DE:AD:BE:EF:00:01` | 192.168.1.101 | 5005 | `output_files/96K_NODE1_192-168-1-101.jic` |
| 2 | `DE:AD:BE:EF:00:02` | 192.168.1.102 | 5006 | `output_files/96K_NODE2_192-168-1-102.jic` |
| 3 | `DE:AD:BE:EF:00:03` | 192.168.1.103 | 5007 | `output_files/96K_NODE3_192-168-1-103.jic` |
| 4 | `DE:AD:BE:EF:00:04` | 192.168.1.104 | 5008 | `output_files/96K_NODE4_192-168-1-104.jic` |

Node 1 reproduces the values that were hardcoded before this change, exactly.

All four images carry LRCLK phase **225°** (`clk3_phase_shift = 25431`) and
`C_BIT_ADJ = -1`. One phase across the whole array — see "Phase" below.

---

## 1. Set up the host

The PC's **wired** adapter must be static `192.168.1.10 / 255.255.255.0`, no
gateway. That address is `C_PC_IP`, and it is load bearing twice over: it is
where the audio is sent, and it is the filter deciding whose ARP the boards are
willing to learn from. Get it wrong and nothing arrives.

Deployment PC, Realtek PCIe GbE, `A0-AD-9F-22-4B-6E` — this is compiled in as
`C_PC_MAC`. See "Moving to a different host" if that changes.

## 2. Flash

```
quartus_pgm -m jtag -o "pi;output_files/96K_NODE2_192-168-1-102.jic"
```

One board at a time, and **check the number in the filename against the board
you have connected**. Four near-identical images is exactly the situation where
the wrong one lands on the wrong board, and the symptom (two boards fighting
over one IP) looks like a network fault rather than a flashing mistake.

## 3. Verify each board before moving on

```
ping 192.168.1.102
arp -a | findstr 192.168.1.102        # expect de-ad-be-ef-00-02
python python/udp_monitor.py -p 5006 -s 5
```

`ping` proves ARP and the IP; the MAC in the ARP table proves you flashed the
image you meant to. Do all three per board, before connecting the next one.

### On the very first board, do this instead — ORDER MATTERS

The ARP learning in `pc_mac_r` is new logic that has never run on hardware, and
it decides where every audio frame goes. On the deployment PC it is invisible in
one direction: `C_PC_MAC` is *already* the correct MAC, so "learning never
fires" and "learning fires correctly" both look like success. The only failure
that shows is learning latching a **wrong** value — and that only happens after
the first ARP. So capture before you ping, once:

```
python python/udp_monitor.py -p 5005 -s 5     # 1. BEFORE any ping
ping 192.168.1.101                            # 2. provokes the ARP
python python/udp_monitor.py -p 5005 -s 5     # 3. after
```

- **alive in 1, dead in 3** → `learn_valid` latched garbage. Revert `pc_mac_r`
  to the constant in `top_system.vhd` and rebuild; everything else stands.
- **alive in both** → learning is correct or inert. `arp -a` plus one frame's
  destination MAC in Wireshark separates those, and either is fine to ship.
- **dead in 1** → not a learning problem. Normal bring-up fault, chase it first.

Once this passes on one board the logic is proven and the short procedure above
is enough for the other three.

## 4. Capture

One instance per board, each on its own port:

```
python python/udp_monitor.py -p 5005 -s 10
python python/udp_monitor.py -p 5006 -s 10
python python/udp_monitor.py -p 5007 -s 10
python python/udp_monitor.py -p 5008 -s 10
```

If you add `--wav`, **give each one its own prefix** — `--wav node1`, `--wav
node2` and so on, giving `node1_ch01.wav` … `node4_ch16.wav`. The filenames are
`"%s_ch%02d.wav" % (prefix, channel)` and carry no port or address, so four
monitors sharing a prefix silently overwrite each other's recordings.

Control likewise takes `--node`:

```
python python/ctrl.py --node 3 --all 0
python python/ctrl.py --node 3 --test --channel 5
```

---

## Why separate ports

`udp_monitor.capture()` uses `recv()`, not `recvfrom()`. Four boards sharing
port 5005 would interleave four independent sequence-number streams into one
socket, and `loss_report` would show enormous packet loss that isn't real. One
port per board means one socket per board and the existing tools work unchanged.

The UDP checksum is `0x0000` (legal for IPv4), so moving the port costs nothing —
no checksum depends on it.

## Network requirements

Each board sends 12000 packets/s (96 kHz ÷ 8 frames per packet). On the wire
that is 476 bytes each, including preamble, FCS and interframe gap:

```
476 x 8 x 12000  =  45.7 Mbit/s per board
             x4  = 182.8 Mbit/s aggregate
```

**That does not fit in 100BASE-TX.** The switch uplink and the PC NIC must be
gigabit. The four board links stay at 100 Mbit, which is fine — each carries
only its own stream.

That last sentence is only true because of the ARP fix below.

## The destination MAC, and why it mattered

`C_PC_MAC` used to be `FF:FF:FF:FF:FF:FF`, commented *"Broadcast until ARP
resolves"* — but nothing ever resolved it. `arp_responder` captured the sender
MAC for its own reply path and never passed it anywhere else, so every audio
frame shipped with a broadcast destination, permanently.

On one board that is untidy and harmless. On four it is fatal: broadcast is
flooded to every switch port unconditionally and is **never** suppressed by MAC
learning. Each board's 100 Mbit port would have received its own 45.7 Mbit/s
plus the other three boards' 137 Mbit/s, and the I²C control path would have
starved inside a failure mode that reads as anything but a MAC problem.

Now: `C_PC_MAC` is the **reset default**, and `pc_mac_r` in `top_system` tracks
whoever ARPs from `C_PC_IP`. The learning strobe reuses every check
`arp_responder` already made — EtherType, hardware and protocol type, opcode,
target IP is ours, clean CRC — plus sender IP equals `C_PC_IP`, so a stray host
on the segment cannot redirect the audio stream at itself.

### Moving to a different host

No reflash. Set the new machine's wired adapter to 192.168.1.10 and send each
board one packet — a `ping` is enough. The ARP that provokes teaches the board
the new MAC. Until that happens the board uses the compiled-in deployment PC
address, so the deployment PC needs no round trip at all.

## The IP header checksum

This used to be the literal `x"B577"` in `udp_tx_core.vhd`, correct for
192.168.1.101 → 192.168.1.10 and for nothing else. It is now computed from the
addresses by `work.net_pkg.ipv4_checksum`.

This was the single most dangerous thing about a four-board rollout. A stale
checksum does not produce an error anywhere: the board transmits flawlessly, the
frames show up in Wireshark, and the **host kernel discards every one of them at
the IP layer before any socket sees them.** A board that looks alive on the wire
and delivers nothing.

Since `fpga_ip` and `pc_ip` are constants at the top level, synthesis folds the
whole computation back to two literal bytes. It costs nothing.

### How it is verified

There is no simulator licence on this machine, so `top_system.vhd` carries five
static concurrent assertions calling the same function on known values. Quartus
evaluates these during Analysis & Elaboration and **fails the build** if any is
wrong — confirmed by deliberately corrupting one and watching
`Error (10652): VHDL Assertion Statement ... assertion is false`.

Expected values were derived independently by one's-complement sum in Python;
node 1 additionally reproduces the hand-computed `B577` that was already proven
on hardware. The fifth assertion is an all-ones case whose inner sum overflows
16 bits more than once, exercising the carry fold that the four node addresses
do not reach.

## Phase

All four images are 225°. Do not tune phase per board.

The phase result is "slightly better than 105°" on a single board and the A–B–A
reproducibility test is still outstanding. Bringing up four-node networking and
per-board phase tuning simultaneously makes both unreadable. 225° also has more
setup margin than the 240° that was in the PLL before this build (+4.489 ns
against +2.787 ns), so it is the safer default as well as the measured one.

See `LRCLK_PHASE_SHIFT.md`.

---

## Cross-board timing — read before doing anything coherent

**Each board free-runs off its own 50 MHz crystal.** The four LRCLKs are
independent time bases. At a typical ±50 ppm the relative drift reaches
100 ppm — **9.6 samples per second at 96 kHz**, and one sample is 15.6 mm of
acoustic path at 1500 m/s. The sequence numbers cannot fix this because each
board counts only its own frames.

What that does and doesn't rule out:

| processing | free-running OK? |
|---|---|
| 16-channel standalone | yes — one PLL, one LRCLK |
| four bearings → cross-fix | **yes** — each bearing is computed inside one board |
| TDOA / multilateration between boards | **no** |
| one coherent 64-element aperture | **no** |

For bearing intersection, cross-board phase never enters the calculation. The
four bearings only need to refer to the same moment, and "the same moment" for a
cross-fix means tens of milliseconds — host packet arrival timestamps are
already better than that. Nothing to do.

For the bottom two rows, the cheap option is **not** to distribute a frequency
reference. A board deployed standalone has no reference cable, so moving the PLL
input to an external clock leaves it with a dead audio domain; fixing that needs
a runtime clock mux and two build variants, which is eight images.

Instead distribute one **slow** signal (1 Hz), latch `seq_num` on its edge, and
report the latched value in the packet header. The host then knows exactly how
many samples each board took between edges, so drift becomes a measured number
to resample against rather than an unknown. A board with no SYNC wire reports
nothing and runs standalone. There is room already — the frame-count field in
`packet_formatter.vhd` is noted as "a constant 0x0008 that nothing reads", and
bytes past 9 fall through to `x"00"`. A slow single-ended pulse also survives
long separated cable runs in a way 24.576 MHz will not.

Not implemented. Decide the processing first.

---

## Hardware note

`U43` pin P34 → FPGA pin 25 is unconnected on the soundcard and is the obvious
landing spot for a SYNC input. It is **not confirmed as a dedicated clock
input** — `GND+` in the Quartus pin report only means Quartus tied an unused pin
to ground. For a slow SYNC pulse that does not matter; any free GPIO works. If a
PLL input there ever matters, assign one and run the Fitter — Quartus errors if
it is illegal.

Related: the QSF has `set_location_assignment PIN_31 -to phy_rst_n`, but the
netlist shows FPGA pin 31 unconnected on the soundcard. That output drives
nothing. Harmless, but it means **QSF assignments in this project do not imply
board connectivity** — check the netlist before wiring anything new.

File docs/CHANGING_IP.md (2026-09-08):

# Changing the array's IP addresses

The addressing is a **two-sided** edit: one constant in the RTL, one in the host
tools. Both sides are guarded, so getting it half-right fails loudly rather than
silently — which matters, because a wrong IP produces a board that transmits
flawlessly and delivers nothing.

Current state (moved 2026-09-07):

```
boards   192.168.3.101 - .104     C_FPGA_IP, derived from C_NODE
host     192.168.3.10             C_PC_IP
ports    5005 - 5008              one per board, deliberately
```

---

## The four things that must agree

```
1.  rtl/top_system.vhd     C_FPGA_IP  x"C0A803" & (100 + C_NODE)
2.  rtl/top_system.vhd     C_PC_IP    x"C0A8030A"
3.  rtl/top_system.vhd     the four ipv4_checksum assertions
4.  python/ctrl.py         SUBNET = "192.168.3"

    and the PC's adapter actually set to C_PC_IP.
```

Items 1–3 are in one file; item 4 is one line. `check_sync.py` compares 1, 2 and
4, and Quartus fails the build on 3. Nothing checks the adapter — that is on you.

---

## Procedure

### 1. Edit the RTL

`rtl/top_system.vhd`, two constants:

```vhdl
constant C_FPGA_IP : std_logic_vector(31 downto 0) :=
    x"C0A803" & std_logic_vector(to_unsigned(100 + C_NODE, 8));
--     ^^^^^^ third octet: C0A803 = 192.168.3

constant C_PC_IP : std_logic_vector(31 downto 0) := x"C0A8030A"; -- 192.168.3.10
```

**`C_PC_IP` must move with the boards.** A board cannot deliver to a host on a
different subnet, and `C_PC_IP` is also the filter deciding whose ARP the board
will learn from (`pc_mac_r`). Changing only the board addresses gives four
boards transmitting perfectly into nothing.

### 2. Recompute the checksum assertions

The IPv4 header checksum itself is computed at elaboration by
`work.net_pkg.ipv4_checksum`, so it follows automatically. But the **static
assertions that verify it** carry expected values, and they are pinned to the
old subnet:

```python
python - <<'EOF'
def ck(src, dst, ln=438):
    s = 0x4500 + ln + 0x0000 + 0x4000 + 0x4011
    s += (src >> 16) + (src & 0xFFFF) + (dst >> 16) + (dst & 0xFFFF)
    s = (s & 0xFFFF) + (s >> 16)
    s = (s & 0xFFFF) + (s >> 16)
    return (~s) & 0xFFFF

pc = 0xC0A8030A                      # <-- new C_PC_IP
for n in (1, 2, 3, 4):
    src = 0xC0A80300 | (100 + n)     # <-- new board subnet
    print("node %d  %08X  ->  %04X" % (n, src, ck(src, pc)))
EOF
```

Paste the four results into the assertion block near the bottom of
`top_system.vhd`. **If you skip this the build fails** — which is the intended
behaviour, not an obstacle.

Sanity check: moving the third octet by 2 (`.1` → `.3`) changes each checksum by
exactly `0x0400`. The old set was `B577/B576/B575/B574`; the new set is
`B177/B176/B175/B174`.

### 3. Edit the host side

`python/ctrl.py`, one line:

```python
SUBNET        = "192.168.3"
KNOWN_SUBNETS = ["192.168.3", "192.168.1"]
```

`SUBNET` is the default for outbound control. `KNOWN_SUBNETS` is what
`discover.py` sweeps — keep the old subnet listed while any board might still
carry an old image, and remove it once the migration is finished.

Everything else derives from these: `node_ip()`, `HOST_IP`, `FPGA_IP`, the GUI
tabs, and `make_gui_standalone.py`'s generated copy.

### 4. Verify before building

```
python python/check_sync.py
```

Must report **0 failed**. It checks:

- `board IP vs ctrl.py` — `C_NODE` and `SUBNET` produce the same address
- `host IP vs ctrl.py` — `C_PC_IP` equals `ctrl.HOST_IP`
- `host on board subnet` — the host and boards are on the same subnet
- `board subnet is known` — `KNOWN_SUBNETS` lists it, so discovery can find it

### 5. Rebuild all images

Both variants for all four boards, eight images. `C_NODE` and `C_DECIMATE` are
the only per-image edits:

```bash
export PATH="/c/altera_lite/25.1std/quartus/bin64:$PATH"
for MODE in true false; do
  TAG=$([ "$MODE" = "true" ] && echo 24K || echo 96K)
  for N in 1 2 3 4; do
    python - <<PY
import re
p = 'rtl/top_system.vhd'
s = open(p, encoding='utf-8').read()
s = re.sub(r'constant C_NODE : integer range 1 to 4 := \d+;',
           'constant C_NODE : integer range 1 to 4 := $N;', s)
s = re.sub(r'constant C_DECIMATE : boolean := (true|false);',
           'constant C_DECIMATE : boolean := $MODE;', s)
open(p, 'w', encoding='utf-8').write(s)
PY
    quartus_sh --flow compile TDM_UATR
    quartus_cpf -c -d EPCS16 -s EP4CE6E22C8 output_files/TDM_UATR.sof \
        "output_files/${TAG}_NODE${N}_192-168-3-10${N}.jic"
  done
done
```

Budget ~90 s per image, ~12 minutes for all eight.

### 6. Set the PC

```powershell
netsh interface ipv4 set address name="Ethernet" static 192.168.3.10 255.255.255.0
```

No gateway, no DNS. See `docs/NETWORK_SETUP.md` for the firewall rule and the
Wi-Fi route conflict.

### 7. Flash and confirm

**One board at a time**, checking the number in the filename against the board
actually connected. Four near-identical images per variant is exactly where the
wrong one lands on the wrong board, and the symptom looks like a network fault
rather than a flashing mistake.

```
quartus_pgm -m jtag -o "pi;output_files/24K_NODE2_192-168-3-102.jic"
ping 192.168.3.102
arp -a | findstr 192.168.3.102        # expect de-ad-be-ef-00-02
```

The MAC in the ARP table proves you flashed the image you meant to.

Then, once all four are done:

```
python python/discover.py
```

which reports each board's real address and measured rate, and names a mixed
subnet or a duplicate sender explicitly.

---

## Migration without downtime

`KNOWN_SUBNETS` exists so the array can be moved a board at a time. During the
move some boards answer on `192.168.3.x` and some on `192.168.1.x`, and
`discover.py` finds both and reports **MIXED SUBNETS**.

To capture from both at once the host needs an address on each subnet. Windows
allows a second address on one adapter:

```powershell
netsh interface ipv4 add address name="Ethernet" 192.168.1.10 255.255.255.0
```

⚠ **But the boards on the old subnet were built with the old `C_PC_IP`**, so
they will only send to `192.168.1.10` and only learn ARP from it. Both addresses
must be present, and both must be the ones compiled into the respective images.
This works, but it is a transitional state — finish the migration.

---

## Why the checksum matters so much

From `docs/MULTI_BOARD.md`, and worth repeating because it is the failure mode
that wastes the most time:

> A stale checksum does not produce an error anywhere: the board transmits
> flawlessly, the frames show up in Wireshark, and the **host kernel discards
> every one of them at the IP layer before any socket sees them.**

A board that looks alive on the wire and delivers nothing. That is why the
checksum is computed rather than hand-entered, why there are static assertions
that fail the build, and why step 2 is not optional.

Confirmed working: deliberately corrupting one expected value produces
`Error (10652): VHDL Assertion Statement ... assertion is false` and stops the
build.

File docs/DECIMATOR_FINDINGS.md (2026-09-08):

# Decimator and network migration — findings, decisions, and bugs

Written 2026-09-08, covering the work that added on-FPGA 4× decimation and moved
the array from `192.168.1.x` to `192.168.3.x`.

This is the record of **what was wrong and why**, not a how-to. For procedures
see `docs/DECIMATION.md`, `docs/NETWORK_SETUP.md` and `docs/CHANGING_IP.md`.

---

## 1. The design brief, and how it changed

The original request was a **CIC decimator**, N=3, R=4, 16 parallel instances,
inserted after the TDM16 merge. Three of that spec's premises turned out to be
wrong, and each changed the design.

### 1.1 A CIC cannot do this band

The band of interest is **10 Hz – 11 kHz**, which is 92% of the 12 kHz Nyquist
after a ÷4. That is a brick-wall requirement, and a CIC is the bluntest filter
there is:

| frequency | role | CIC N=3 response |
|---|---|---|
| 11 kHz | top of the band | **−9.2 dB** droop |
| 13 kHz | folds onto 11 kHz | **−13.3 dB** |

A 13 kHz tone would land on top of the 11 kHz signal only 4.1 dB below it.
Raising the order makes it *worse* — N=5 gives −15.3 dB of droop at 11 kHz —
because the CIC's first null is pinned at 24 kHz and no choice of N moves the
transition down.

A CIC would have been correct for the 100–1500 Hz band the spec's context
section described. It is wrong for 11 kHz.

**Decision: two cascaded halfband FIR stages**, 96k → 48k → 24k. Halfband
because every even tap except the centre is exactly zero (halves the
multiplies), and linear phase because the coefficients are symmetric (halves
them again).

### 1.2 Sixteen parallel instances do not fit

The spec assumed "EP4CE6 has LE budget to spare". The shipping build was
already at **4,025 of 6,272 LEs with 3,047 registers**. Sixteen parallel CIC
instances at 30-bit accumulators need ~274 flip-flops each — 4,384 registers,
against 6,272 total on a device where Cyclone IV E has **one flip-flop per LE**
and no LUT-based distributed RAM.

**Decision: one time-multiplexed datapath.** `tdm16_valid` fires once per audio
frame, which is **256 clock cycles** at 24.576 MHz — ample time to sequence 16
channels through shared arithmetic. This spends the multipliers (0 of 30 used)
and M9K (3% used) that were idle, instead of the LEs that were nearly gone.

### 1.3 No slot decoder or encoder is needed

The spec called for a slot-decoder and slot-encoder around the filter array.
Neither exists, because `tdm16_merge` (`rtl/tdm16_merge.vhd:65`) emits a **flat
384-bit parallel register** with a one-cycle strobe, and `packet_formatter`
consumes exactly that. The decimator is a drop-in with identical ports on both
sides.

Channel alignment — the spec's GCC-PHAT concern — is preserved structurally:
all 16 channels are written on the same strobe and read by the same schedule.

### 1.4 Also corrected

- **"TDM16 merge is mid-verification in ModelSim"** — it is in the shipping
  build and running on hardware. Its one real bug (level test instead of edge
  detect, firing 128×/frame) was fixed in `927aac7`.
- ⚠ **Naming collision:** `tdm16_merge` is active; `tdm16_rx` is a *board-level*
  config requiring the R21/R122 jumper and is **not** active. Do not confuse
  them.

---

## 2. Filter design

Coefficients are generated by `python/design_decimator.py`, which also emits the
VHDL package and bit-exact reference vectors. Lengths were chosen by exhaustive
search over (n, beta) for the cheapest pair meeting spec.

```
stage 1   n=27,  beta 11.0   15 non-zero taps    8 folded
stage 2   n=171, beta 11.0   87 non-zero taps   44 folded
```

Measured on the **quantised** cascade, not the float ideal:

```
passband ripple 0-11 kHz      0.00015 dB      (limit 0.01)
droop at 11 kHz              -0.0001  dB
worst alias band             -102.5   dB      (limit -100)
at 13 kHz                    -120.3   dB
group delay                    1.91   ms
```

### Why 100 dB, without measuring the water

The stopband was sized against the **ADAU1978's own noise floor** (103 dB
dynamic range, `docs/adau1978.pdf` p.3) rather than against a measured spectrum.
At −102.5 dB, aliased content lands under the converter's noise and cannot
degrade anything, whatever is actually up there.

This was deliberate: no WAV capture was available, and designing to the noise
floor is assumption-free. The cost is ~26 more taps than an optimistic design,
against 2.5× MAC headroom — not worth a bench session to reclaim.

**The compensation FIR is unnecessary.** 0.0001 dB droop at 11 kHz. That was
listed as an open question in the original spec; it is answered.

### Scope boundary

At 12 kHz the response is only −6 dB. This filter protects the **band of
interest**, not the full 0–12 kHz output band. If the application ever widens
toward the new Nyquist, the design must be revisited.

---

## 3. Bugs found

Ordered by severity. Every one of these would have shipped.

### 3.1 Pipeline misalignment — silently wrong output ★ worst

Stage A registered the RAM data **and** the coefficient together, but stage B
read the coefficient through a *second* register (`cf1` → `cf1_d`) while
reading the data through only one. **Every coefficient multiplied the wrong
sample.**

```
as-written : maxdiff vs direct convolution = 1,243,545,140
corrected  : maxdiff                       = 0
```

**Why it nearly shipped:** my first verification modelled the pipeline I
*intended*, not the one I *wrote*. It was only caught by building a model that
follows VHDL signal semantics exactly — every signal read returns its pre-edge
value — and comparing against a direct convolution.

Synthesis passes. Timing passes. TNS is 0.0. It would have appeared as noise on
all 16 channels after flashing, with nothing in the toolchain flagging it.

### 3.2 Schedule overrun — dropped output frames

The cycle budget assumed 1 cycle per tap. The `ADDR → MAC` state machine as
written took **2**:

```
engine 2 needed  16 ch x 44 taps x 2 cycles + overhead = 1,440 cycles
budget                                                  1,024 cycles   (141%)
```

`e2_go` is a one-cycle pulse; if engine 2 is still busy it is **missed
silently**. Output frames vanish, `valid_out` stutters, and there is no error
anywhere — it would have looked like intermittent network packet loss.

Fixed by pipelining both engines to one tap per cycle:

```
engine 1:  144 cycles of  512  (28%)
engine 2:  720 cycles of 1024  (70%)
```

### 3.3 `mod` on a non-power-of-two inferred a hardware divider

`D2` was briefly 192, and `mod D2` synthesised into two `lpm_divide` instances
— **282 LEs** of real divider on a device with none to spare. Replaced with a
conditional subtract (one comparator).

The RTL now carries a `NEVER WRITE "mod D2" HERE` comment.

### 3.4 Memory blocks, not memory bits, are the binding resource

Padding `D2` from 171 to 256 costs nothing in LEs and **11 extra M9K blocks**.
At 24-bit width an M9K holds only 256 words, so the design can exhaust all 30
blocks while showing 60% *bit* utilisation. The fit failed at 60% memory bits.

Fixed by using exact depth (171) with an explicit wrap.

### 3.5 SignalTap was in the deployment images

`ENABLE_SIGNALTAP` was `ON` with `signaltap_rmii.stp`, and its capture buffer
consumed the M9K blocks the decimator needed. **The fit only succeeded after
removing it.**

It is a debug instrument and should never have been in shipping images. Note
the pre-existing 96 kHz NODE images were built *with* it.

### 3.6 Multiple constant drivers

`saturated` was written from both engines. Quartus rejects this outright
(`Error 10028`), which is correct behaviour — split into `sat1_r`/`sat2_r`
OR-ed combinationally.

### 3.7 Host: rate detection false-positive under heavy loss

Loss only ever *lowers* the measured packet rate, and the two rates are exactly
4× apart. A 96 kHz board losing 75% of its packets measures 24,000 and was
reported as a **healthy 24 kHz board, "confident"**.

Fixed using the sequence numbers, which are loss-independent — the FPGA
increments them per packet *sent*:

```
96 kHz board, 75% loss:
  without seqs -> (24000, True)   wrong
  with seqs    -> (96000, True)   right
```

### 3.8 Host: two `check_sync.py` guards had silently died

The IPv4 checksum check and the header-length check were both regexing for
literals (`IP_CHECKSUM`, `when 16 => x"..."`) that had become computed
expressions in earlier work. **They had been passing by not matching anything.**

Rewritten to read the current RTL. The new `C_DECIMATE` check immediately
caught a real mismatch, proving it works.

### 3.9 Host: standalone GUI generator ordering

`SUBNET` was added to `ctrl.py` but not to the generator's `ct_names` list, so
`FPGA_IP = SUBNET + ".101"` ran before `SUBNET` existed — `NameError` on
import. Later the same pattern recurred with `detect_rate`, which imported fine
and would have raised `AttributeError` the first time a meter updated.

The file already carried a comment warning about exactly this ordering trap for
`buoy_ip`/`BUOYS`.

### 3.10 Build races produce mislabelled images

Two concurrent build scripts both edit `rtl/top_system.vhd` and both write
`output_files/TDM_UATR.sof`, so the `.jic` copied out can carry another run's
`C_NODE` — an image labelled for one board containing another board's IP.

`build_all.sh` now takes a lock and refuses to start if one is held.

---

## 4. Network migration findings

### 4.1 `INADDR_ANY` does not mean "any destination"

Measured on this machine:

```
destination        host owns it?     received on INADDR_ANY socket?
127.0.0.1          yes               YES
192.168.1.10       yes               YES
192.168.3.240      yes               YES
192.168.3.10       NO                NO      <-- silently dropped
```

Unicast UDP is filtered by **destination address**. The kernel drops packets
addressed to an IP the host does not own, before any socket sees them. The
sender's subnet is irrelevant.

**Consequence:** the host must hold an address matching each image's
compiled-in `C_PC_IP`. A board on `192.168.3.101` sending to `192.168.3.10`
delivers nothing until the host owns `192.168.3.10`.

### 4.2 `C_PC_IP` must move with the boards

It is load bearing twice: it is where audio is sent, **and** it is the filter
deciding whose ARP the board will learn from (`pc_mac_r`). Changing only the
board addresses gives four boards transmitting perfectly into nothing.

### 4.3 The checksum assertions are pinned to the subnet

The IPv4 header checksum is computed at elaboration by `net_pkg.ipv4_checksum`
and follows automatically. But the **static assertions that verify it** carry
expected values that must be recomputed by hand.

Confirmed they bite: corrupting node 1's expected value produces
`Error (10652): VHDL Assertion Statement ... assertion is false` and stops the
build.

Old set `B577/B576/B575/B574` → new set `B177/B176/B175/B174`. They differ by
exactly `0x0400`, the third octet's contribution — a cheap sanity check.

### 4.4 Capacity is not close to a limit

```
4 boards @ 24 kHz + 4 buoys telemetry = 46.6 Mbit/s   (4.7% of gigabit)
4 boards @ 96 kHz + telemetry         = 183.6 Mbit/s  (needs gigabit)
```

Telemetry is 0.9 Mbit/s — under 2% of the audio. It was never a constraint.

Decimation is what takes the array from *needs gigabit end to end* to *fits in
100BASE-TX*.

### 4.5 Python is fast enough — but only if batched

Measured:

```
socket receive, 64 MB rcvbuf              59,650 pkt/s   0.00% loss
four sockets, four senders, 12,000 pkt/s   0.0000% loss

full 24-bit unpack, ONE packet at a time   30,800 pkt/s   <-- below 48,000
batched numpy (1000 packets at once)      161,000 pkt/s
```

**A naive loop that unpacks each datagram as it arrives drops packets at
96 kHz.** The rule for the deployment app: *receive into a list, never unpack
inside the receive loop, unpack in vectorised batches.*

`udp_monitor.capture()` already does this. Preserve the structure.

---

## 5. Verification, and its limits

**There is no simulator.** GHDL is not installed, and the bundled Questa fails
with `Unable to checkout a license`. So the verification path is:

1. **Quartus static assertions** — evaluated at elaboration, fail the build.
   Proven to work by deliberate corruption.
2. **`python/design_decimator.py --check`** — re-measures ripple and alias
   rejection against the stated limits.
3. **Cycle-accurate Python model** — follows VHDL signal semantics exactly
   (every signal read returns its pre-edge value). This is what caught the
   pipeline misalignment.
4. **`sim/decim_ref_vectors.txt`** — bit-exact reference output from the same
   script that generates the coefficients, so they cannot drift apart.
5. **`python/check_sync.py`** — 58 assertions cross-checking host constants
   against the RTL.

### What is NOT verified

**Nothing has been on hardware.** The decimator is verified numerically and
structurally only. The first capture is the real test, and the reference
vectors exist so it can be diffed rather than eyeballed.

Read the **packet rate first**: ~3,000/s is success; ~12,000/s means
`valid_out` is being ignored downstream — the classic decimator integration
bug, not a filter fault.

---

## 6. Standing lessons

1. **Model what you wrote, not what you meant.** The pipeline bug survived one
   round of "bit-exact" verification because the model encoded the intent.
2. **A passing check may be checking nothing.** Two `check_sync.py` guards had
   been green for weeks while matching no text at all.
3. **Cheap in one resource is expensive in another.** Padding a RAM depth costs
   zero LEs and broke the fit on memory blocks.
4. **Generated files must be executed, not just generated.** "wrote 3,290
   lines" is not evidence; two separate namespace bugs only appeared on import
   and on first use.
5. **Never `git checkout` a file mid-session to reset unrelated state.** It
   reverted the entire subnet migration and had to be reapplied by hand.

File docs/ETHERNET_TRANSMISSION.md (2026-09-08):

# Ethernet Transmission

## Purpose

The FPGA streams 16 channels of 24-bit audio from the ADAU1978 ADCs to a host PC using Ethernet over UDP. The Cyclone IV FPGA creates the Ethernet frame and sends it to a LAN8720A PHY through RMII. The PHY then converts the digital RMII stream to 100BASE-TX Ethernet for the media converter and subsea fiber link.

```text
ADAU1978 ADCs
    |
    v
TDM8 receivers
    |
    v
packet_formatter
    |
    v
Async FIFO
    |
    v
udp_tx_core: Ethernet + IPv4 + UDP headers
    |
    v
rmii_tx: preamble + frame data + FCS + IFG
    |
    v
LAN8720A PHY
    |
    v
RJ45 -> media converter -> single-mode fiber -> host PC
```

## Data Rate

The active design carries:

| Item | Value |
|---|---:|
| Audio channels | 16 |
| Sample size | 24 bits |
| Sample rate | 96 kHz |
| Audio payload rate | 36.864 Mbps |
| Ethernet link | 100 Mbps RMII/100BASE-TX |
| UDP destination port | 5005, configured per board |
| Payload per UDP packet | 410 bytes |
| Audio frames per packet | 8 |
| Packets per second | approximately 11,950 to 12,000 |

The 100 Mbps link provides approximately 2.7 times the raw audio payload bandwidth required by the 16-channel stream.

## 1. Audio Packet Formation

`packet_formatter.vhd` runs in the audio-side clock domain. Each valid TDM sample is latched and written into an asynchronous FIFO one byte at a time.

A complete UDP payload contains eight audio frames:

```text
8 frames x 50 bytes per frame = 400 bytes
10-byte packet header          =  10 bytes
                                  -------
                                  410 bytes
```

Each 50-byte audio frame contains:

```text
bytes 0-1    diagnostic/status bytes or frame information
bytes 2-49   16 channels x 3 bytes per 24-bit sample
```

The first ten bytes of each packet include a project magic value and a 32-bit sequence number:

| Byte range | Contents |
|---|---|
| 0-3 | Magic value `AD A1 97 78` |
| 4-7 | 32-bit packet sequence number, most significant byte first |
| 8-9 | Diagnostic bytes |
| 10-409 | Eight 50-byte audio frames |

When all 410 bytes have been written, `packet_formatter` toggles `packet_ready`. The toggle safely crosses from the packet-formatting clock domain to the 50 MHz Ethernet transmit clock domain.

## 2. UDP, IPv4, and Ethernet Headers

`udp_tx_core.vhd` presents a fixed 452-byte frame body to `rmii_tx`:

```text
14-byte Ethernet header
20-byte IPv4 header
 8-byte UDP header
410-byte UDP payload
--------------------------------
452 bytes before Ethernet FCS
```

The Ethernet header contains:

| Field | Size | Description |
|---|---:|---|
| Destination MAC | 6 bytes | PC MAC address |
| Source MAC | 6 bytes | FPGA MAC address |
| EtherType | 2 bytes | `0x0800`, IPv4 |

The IPv4 header is configured as:

| Field | Value |
|---|---|
| Version / header length | IPv4, 20-byte header (`0x45`) |
| Total length | 438 bytes: IPv4 header + UDP header + payload |
| Flags | Do not Fragment |
| TTL | 64 |
| Protocol | UDP (`17`) |
| Source address | FPGA IP address |
| Destination address | Host PC IP address |
| Header checksum | Computed from the configured addresses and length |

The UDP header uses the configured board port as both source and destination port. The UDP length is 418 bytes:

```text
8-byte UDP header + 410-byte payload = 418 bytes
```

The UDP checksum is set to zero. For IPv4, zero indicates that the UDP checksum is unused. Ethernet still protects the complete frame with its FCS.

## 3. RMII Transmission

The LAN8720A receives RMII data from `rmii_tx.vhd` on a 50 MHz reference clock. RMII transfers two bits per clock, giving:

```text
50 MHz x 2 bits = 100 Mbps
```

The transmit state machine sends each byte as four 2-bit slices, least-significant slice first:

```text
byte[1:0] -> byte[3:2] -> byte[5:4] -> byte[7:6]
```

`rmii_tx` generates the standard Ethernet framing sequence:

1. Seven bytes of preamble, all `0x55`
2. One-byte Start Frame Delimiter, `0xD5`
3. The 452-byte Ethernet/IP/UDP frame body
4. Four-byte Ethernet FCS generated by the CRC32 block
5. Inter-frame gap of at least 96 bit times

`rmii_tx_en` remains asserted during the preamble, SFD, frame body, and FCS. It is deasserted during the inter-frame gap.

The transmit handshake is intentionally level-based:

- `tx_start` is held high for the complete frame body.
- `tx_ready` acknowledges that the current `tx_data` byte has been consumed.
- The producer must place the next byte on `tx_data` before the next acknowledgement.
- The transmitter remains busy through the FCS and inter-frame gap.

This prevents another transmitter, such as the ARP responder, from taking control of the RMII pins before the current Ethernet frame is completely finished.

## 4. PHY and Fiber Path

The FPGA does not directly drive the twisted-pair or fiber signaling. The physical path is:

```text
FPGA RMII pins
    -> LAN8720A 100 Mbps PHY
    -> 100BASE-TX RJ45 connection
    -> media converter
    -> BiDi WDM single-mode fiber
    -> second media converter
    -> host PC Ethernet interface
```

The media converters use different wavelengths for transmit and receive, so one fiber core carries the full-duplex link. The subsea cable is approximately 7 km long, while the media converters are rated for up to 20 km under the specified optical conditions.

## 5. ARP and Host Reception

Before the host can receive unicast UDP audio, the FPGA must know the host MAC address. The ARP responder listens for ARP requests and learns the sender MAC address. It can also transmit an ARP reply using the same RMII transmitter.

After address resolution, the host receives UDP datagrams on the configured port. The sequence number in bytes 4-7 allows the receiver to detect missing packets. A missing packet represents eight missing audio frames, so the host can report the gap and insert the appropriate replacement samples instead of silently shifting the rest of the stream in time.

## Verified Results

The Ethernet transmission was tested on hardware with Wireshark and the Python UDP receiver.

| Check | Result |
|---|---|
| Ethernet stack | Complete and operating on hardware |
| Packet rate | Approximately 11,950 packets/s |
| FPGA-side sequence gaps | 0 observed |
| Ethernet FCS | Confirmed valid in Wireshark |
| IPv4 checksum | Confirmed valid in Wireshark |
| UDP delivery | Audio packets received by the host |
| Physical transport | LAN8720A -> media converter -> fiber path |

The measured packet rate is consistent with the fixed packet size and the 96 kHz audio source. The zero FPGA-side sequence gaps confirm that the packet formatter, FIFO, clock-domain crossing, and transmit scheduler kept up with the audio stream during the hardware test.

## Important Limitations

UDP does not retransmit lost packets. Ethernet and IPv4 checksums identify corrupted frames, while the application sequence number identifies missing packets. The host receiver must therefore monitor sequence numbers and handle gaps explicitly.

The current transmit logic uses fixed packet and payload sizes. Changing the payload size requires the IPv4 total length, UDP length, FIFO terminator, packet parser, and checksum-related checks to be updated together.

## Related RTL

- `rtl/packet_formatter.vhd` - creates the 410-byte audio payload
- `rtl/udp_tx_core.vhd` - creates Ethernet, IPv4, and UDP headers
- `rtl/rmii_tx.vhd` - creates RMII symbols, preamble, FCS, and inter-frame gap
- `rtl/crc32.vhd` - calculates the Ethernet frame check sequence
- `rtl/arp_responder.vhd` - handles ARP requests and MAC address learning
- `python/udp_monitor.py` - receives packets and reports sequence gaps

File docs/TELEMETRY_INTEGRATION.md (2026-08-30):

# Buoy telemetry: how it is arranged, and how to lift it into the main app

Three sensors per buoy, three protocols, three modules. The decoders are
deliberately **GUI-agnostic** — standard library only, no tkinter, no Qt — so
moving them into the PyQt application means importing them and deleting code,
not porting it.

```
python/gdat2.py      $GDAT2 ASCII telemetry     aux_vcu
python/witmotion.py  WitMotion binary IMU       attitude
python/ping1d.py     Ping protocol              Blue Robotics Ping1D altimeter
python/mixer_gui.py  tkinter GUI                ← the only tk-specific file
```

Only `mixer_gui.py` knows what a widget is. Everything else is transport and
decode.

---

## 1. Addressing

`192.168.3.1<buoy><role>`, all on **port 8080**.

| role | | buoy 1 | buoy 2 | buoy 3 | buoy 4 |
|---|---|---|---|---|---|
| 0 | `$GDAT2` telemetry | `.110` | `.120` | `.130` | `.140` |
| 1 | WitMotion IMU | `.111` | `.121` | `.131` | `.141` |
| 2 | Ping1D altimeter | `.112` | `.122` | `.132` | `.142` |

```python
gdat2.buoy_ip(3, gdat2.ROLE_GDAT2)      # '192.168.3.130'
gdat2.buoy_ip(3, gdat2.ROLE_IMU)        # '192.168.3.131'
gdat2.buoy_ip(3, gdat2.ROLE_ALTIMETER)  # '192.168.3.132'
```

Verified against hardware on 2026-08-29. Use `buoy_ip()` rather than literals:
three roles one digit apart is the easiest kind of address to mistype, and a
wrong digit reaches a **real device that is simply not the one you meant** — so
the symptom is a decoder finding nothing, not a connection error.

> **The host needs an address on this subnet.** If your Ethernet adapter is
> configured for the FPGA soundcards (`192.168.1.x`) it cannot reach these at
> all, and traffic leaves via Wi-Fi instead. Windows allows a second address on
> one NIC:
> ```
> netsh interface ipv4 add address name="Ethernet" 192.168.3.240 255.255.255.0
> ```

---

## 2. The one interface all three share

Every module exposes a thread with the same four members. Learn it once.

```python
link = gdat2.Link("client", host, 8080)     # or witmotion.WitLink(host)
link.start()                                #    or ping1d.PingLink(host)
snap = link.snapshot()                      # thread-safe dict, never raises
link.close()
```

The threads **reconnect on their own and never raise into the caller**. A dead
sensor is a `state` string, not an exception — you do not need try/except
around any of this.

Common keys in every `snapshot()`:

| key | meaning |
|---|---|
| `state` | `"connected"`, `"connecting to …"`, `"reconnecting"`, `"peer closed"`, `"error: …"` |
| `peer` | `"host:port"` once connected |
| `rate` | packets or sentences per second, recomputed each 0.5 s |
| `good` | count decoded since the link started |

Then the per-protocol part:

| | extra keys |
|---|---|
| `gdat2.Link` | `last`, `lines`, `csum_err`, `parse_err`, `lost`, `tail` |
| `witmotion.WitLink` | `angle`, `accel`, `gyro`, `quat`, `t`, `bad` |
| `ping1d.PingLink` | `dist`, `conf`, `t`, `bad`, `timeouts`, `asked`, `answered_id`, `nacks`, `last_nack`, `applied` |

**One inconsistency to know about.** `gdat2.Link` has no top-level `t`; its
timestamp is on the decoded sentence, `snap["last"]["t"]`. The other two
timestamp the link itself. Normalise it if you want uniform staleness logic:

```python
t = snap["last"]["t"] if snap.get("last") else None
```

### Staleness is the check that matters

A socket can stay open while the far end stops talking. `state` still reads
`"connected"`, and the last decoded values sit there looking perfectly healthy.
Every display in this repo therefore treats **stale as worse than
disconnected**:

```python
live = t is not None and (time.time() - t) <= 1.0     # 3.0 for the altimeter
```

The altimeter gets a longer window because it answers on request and
legitimately goes quiet between polls; the other two stream continuously.

---

## 3. Calibration constants

Per buoy, because they describe **an installation, not a sensor** — how that
IMU is bolted into that hull, and what ferrous metal sits near it. Two units on
the same bench will not share values.

```python
witmotion.HEADING_OFFSET_DEG = {1: 0.0, 2: 0.0, 3: -12.4, 4: 0.0}
witmotion.LEVEL_OFFSET_DEG   = {1: (0.0, 0.0), ..., 3: (2.15, -4.66), ...}

hdg       = witmotion.heading(yaw, buoy=3)          # -> [0, 360)
roll, pit = witmotion.level(roll, pitch, buoy=3)    # -> zeroed when level
```

Always apply these before displaying attitude. Raw yaw uses ±180 and the
offset pushes readings across that seam, so a buoy near north flips between
−12 and +347 unless you go through `heading()`.

**To calibrate a buoy**

1. Point the bow at north, read raw yaw → `HEADING_OFFSET_DEG[n]`.
2. Sit it level, average a few seconds of raw roll and pitch →
   `LEVEL_OFFSET_DEG[n]`.

`python witmotion.py --buoy N` prints both raw. Note whether you sighted true
or magnetic north — the arithmetic is the same, but it decides what the
corrected heading means.

> Level correction is a **small-angle** approximation: strictly a mounting
> misalignment is a rotation, and undoing it means rotating the gravity vector
> rather than subtracting two numbers. Below ~10° the error is negligible. It
> breaks if a unit is ever mounted at a serious angle.

---

## 4. The altimeter needs its settings written

This is the one that will waste your afternoon otherwise.

**The Ping1D boots with `ping_interval = 250 ms`** — four measurements a second.
A host polling faster just re-reads the same stale result, and it reads
confidence 0 with the range wandering 54–92 m. Writing the vendor settings
(50 ms) took confidence to 22–51 % and settled the range.

`ping1d.PingLink` writes them on every connect by default:

```python
ping1d.VENDOR_DEFAULTS      # {'interval': 50, 'gain': 3, 'sos': 1500000, 'enable': 1}
link = ping1d.PingLink(host)                    # writes them
link = ping1d.PingLink(host, settings=None)     # connects without touching the sensor
```

`snapshot()["applied"]` reports what was actually written. Sound velocity is
`1500000` mm/s for water, ~`343000` for an air bench test.

Two more things about this sensor:

- **Confidence, not range, says whether it found anything.** ~90 m at 0 % is
  the sonar's ceiling — "no echo" — not a measurement. In air that is normal.
- **Its `distance` message is 5 bytes, not the documented 24**, and the
  confidence field is `u8` there rather than `u16`. `parse_distance()`
  dispatches on payload length for that reason. Checked against `brping`'s
  `get_distance()` on the real device: identical distances and confidences.

---

## 5. Dropping this into the PyQt app

The existing app has one thread per sensor emitting Qt signals. The simplest
integration keeps your widgets and replaces the transport.

**Replace these**

| existing class | use instead |
|---|---|
| `DataFetcherThread` (TCP mode) | `gdat2.Link` |
| `PingSensorThread` + `TCPSocketIO` + `brping` | `ping1d.PingLink` |
| — (no equivalent today) | `witmotion.WitLink` |

Because `snapshot()` is a cheap, thread-safe read, you do not need a QThread or
signals at all — a `QTimer` polling at display rate is enough, and it removes a
whole class of cross-thread bugs:

```python
class BuoyPanel(QWidget):
    def __init__(self, buoy):
        super().__init__()
        self.tel = gdat2.Link("client", gdat2.buoy_ip(buoy, gdat2.ROLE_GDAT2), 8080)
        self.imu = witmotion.WitLink(gdat2.buoy_ip(buoy, gdat2.ROLE_IMU))
        self.alt = ping1d.PingLink(gdat2.buoy_ip(buoy, gdat2.ROLE_ALTIMETER))
        for lk in (self.tel, self.imu, self.alt):
            lk.start()
        self.buoy = buoy
        t = QTimer(self); t.setInterval(100)
        t.timeout.connect(self.refresh); t.start()

    def refresh(self):
        now = time.time()

        s = self.imu.snapshot()
        live = s["t"] is not None and (now - s["t"]) <= 1.0
        if live and s["angle"]:
            a = s["angle"]
            r, p = witmotion.level(a["roll"], a["pitch"], buoy=self.buoy)
            self.compass.setYaw(witmotion.heading(a["yaw"], buoy=self.buoy))
            self.attitude.setAttitude(r, p)

        a = self.alt.snapshot()
        if a["dist"] is not None:
            self.lbl_distance.setText("%.2f m" % (a["dist"] / 1000.0))
            self.lbl_confidence.setText("%d %%" % (a["conf"] or 0))

        g = self.tel.snapshot()["last"]
        if g and g["ok"]:
            leak = g["vals"][0]          # see gdat2.FIELDS for the order
            ...

    def closeEvent(self, ev):
        for lk in (self.tel, self.imu, self.alt):
            lk.close()
        ev.accept()
```

**Index `gdat2.FIELDS` by name, never by number.** The field map and its
plausibility bounds are two arrays kept in step; hardcoding `vals[7]` is how a
shifted map ends up printing believable numbers under the wrong headings:

```python
I_DEPTH = [i for i, (nm, _u, _k) in enumerate(gdat2.FIELDS) if nm == "Depth"][0]
```

`gdat2.implausible(vals)` returns `[(index, value, lo, hi)]` for anything out
of range — worth colouring rather than hiding, since it is the signal that a
field map has shifted.

### Attitude has two sources, and they are not independent

The aux_vcu **relays the IMU's attitude** into `$GDAT2` fields 4–6. Measured
simultaneously: GDAT2 roll `2.1000`, IMU roll `+2.10`. Prefer the IMU (~1000
packets/s against the sentence's 50) and fall back to `$GDAT2` when its link is
down — but do not treat agreement between them as corroboration.

### Fields that are not populated on this firmware

- `Altimeter dist` / `Altimeter conf` — hard zero. The sensor is a separate
  device at role 2. The manufacturer's own parser skips these two fields.
- `Voltage monitor` — flat zero.
- `Depth` — has been seen at `−222`, `−403` and `+236695` m as well as
  plausible values. Treat with suspicion and check `implausible()`.

---

## 6. Verifying without hardware

Every module runs its decoder against known-good bytes, including frames
captured from the real devices:

```
python gdat2.py --selftest
python witmotion.py --selftest       # real captured frame + both calibrations
python ping1d.py --selftest          # includes the 5-byte distance case
```

And each has a simulator, so the display path can be exercised with nothing
plugged in:

```
python gdat2.py --sim                # then --connect 127.0.0.1:8080
python ping1d.py --sim
python ping1d.py --sim --no-sim-simple   # firmware that refuses msg 1212
```

**When a link connects and decodes nothing, dump the bytes before suspecting
the sensor.** That is how the IMU at role 1 was found: it was being read as
`$GDAT2`, reported ~300 unparsable sentences a second, and looked identical to
a dead device.

```
python altimeter_probe.py 192.168.3.131      # works on any of these hosts
```

---

## 7. Regenerating the standalone GUI

`mixer_gui_standalone.py` is **generated** — one file, no local imports, for
copying onto a machine that has only numpy.

```
python make_gui_standalone.py           # rebuild
python make_gui_standalone.py --check   # fail if stale
```

Never edit it directly; edit the modules and regenerate. It inlines the
decoders by name, and the generator fails the build rather than emitting a file
that dies on the target: it catches a name read but never defined, a definition
renamed upstream, and a name inlined from two modules at once (which is why
`ping1d` and `witmotion` prefix everything — both would otherwise want `Link`,
`Sim`, `build` and `checksum`).

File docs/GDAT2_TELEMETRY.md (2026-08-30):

# $GDAT2 sensor telemetry — aux_vcu → Control Station

New protocol, separate hardware. This is **not** the FPGA soundcard: different
device, different transport (TCP, not UDP), different framing. Implemented in
`gdat2.py`, displayed in the **Telemetry** tab of `mixer_gui.py`.

Addressing is **`192.168.3.1<buoy><role>`**, role `1` = telemetry, `2` =
altimeter. One aux_vcu per buoy on **port 8080**:

| | telemetry | altimeter | |
|---|---|---|---|
| buoy 1 | `192.168.3.111` | `192.168.3.112` | |
| buoy 2 | `192.168.3.121` | `192.168.3.122` | |
| buoy 3 | `192.168.3.131` | `192.168.3.132` | **active unit** |
| buoy 4 | `192.168.3.141` | `192.168.3.142` | |

> **Re-addressed 2026-08-29.** Telemetry moved `.1x0` → `.1x1` when the
> manufacturer gave the altimeter its own address at `.1x2`. Captures and notes
> written before that date refer to `.110/.120/.130/.140`.

`gdat2.buoy_ip(n, role)` is the one definition of the scheme — written as a
rule, not eight literals, because the two roles differ by a single digit in the
last octet. That is the easiest kind of address to mistype and the hardest to
notice: a wrong one connects to a real device that simply is not the one you
meant, and the symptom is a silent link rather than an error.

`gdat2.ACTIVE_BUOY` names the unit in service and `DEFAULT_HOST` follows it, so
a bare `python imu_test.py` dials the buoy that exists rather than whichever is
first in the table. Change it in that one place when the active unit changes.
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

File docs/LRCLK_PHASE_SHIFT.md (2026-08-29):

# Moving the LRCLK launch phase — step by step

Written 2026-08-21, for the ADC3/ADC4 intermittent dropouts that survived the LRCLK
falling-edge fix, three cable rebuilds, and a 49.9 → 100 Ω termination change.

**Read section 0 before compiling anything.** The RTL is in place and the phase is one
value in the MegaWizard, but *which direction to move it is not yet known*, and half the
reason this document exists is to stop that being guessed.

---
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

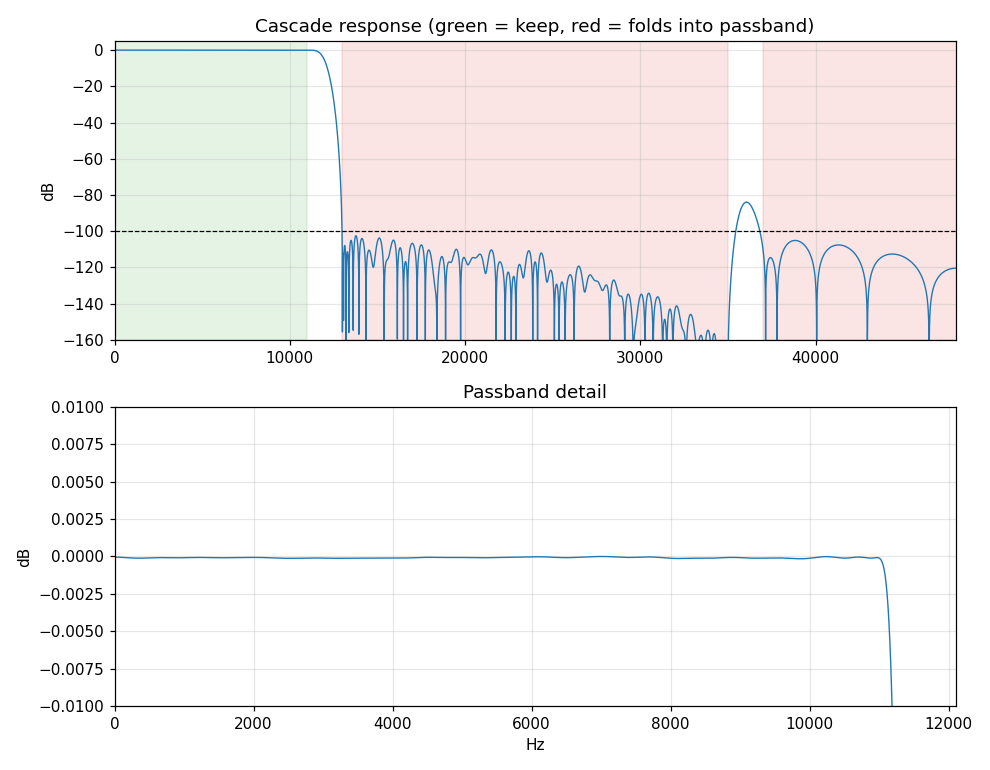
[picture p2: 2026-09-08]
docs/decimator_response.png

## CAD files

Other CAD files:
db/stp2_auto_stripped.stp
output_files/stp2.stp
db/stp1_auto_stripped.stp
output_files/stp1.stp

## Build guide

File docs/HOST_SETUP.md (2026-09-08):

# Host configuration — the complete procedure

Everything the control-station PC needs to talk to all four soundcards and all
four buoys at once. Written 2026-09-08.

Start here if you are setting up a machine. For *why* it is arranged this way
see `docs/NETWORK_SETUP.md`; for changing the addressing see
`docs/CHANGING_IP.md`.

> ## THE HOST MUST SUPPORT BOTH SUBNETS
>
> Boards exist in two generations and **a board only ever talks to the address
> its own image was built with**:
>
> | board flashed with | sends audio to | learns ARP from |
> |---|---|---|
> | `*_192-168-3-*.jic` (current) | `192.168.3.10` | `192.168.3.10` only |
> | anything older | `192.168.1.10` | `192.168.1.10` only |
>
> `C_PC_IP` is a single constant compiled into each image — one value per
> image, never two. So the **host** is the side that must hold both addresses,
> and it must hold both **whenever any board on either subnet is in use**.
>
> This is not a migration-only workaround. Until every board in the array has
> been reflashed *and verified*, both addresses stay. A board on the wrong
> subnet does not error — it transmits perfectly and the host kernel discards
> every frame before any socket sees it.
>
> Both addresses live happily on one NIC. See §2.

---

## 0. The one-minute version

```powershell
# audio (UDP, boards -> host) - BOTH addresses, both subnets. Not optional.
netsh interface ipv4 set address name="Ethernet" static 192.168.3.10 255.255.255.0
netsh interface ipv4 add address name="Ethernet" 192.168.1.10 255.255.255.0
# let inbound audio through
New-NetFirewallRule -DisplayName "TDM_UATR audio" -Direction Inbound `
    -Protocol UDP -LocalPort 5005-5008 -Action Allow -Profile Private
```

```
python python/discover.py          # does it see the boards?
python python/imu_test.py          # does it see the buoys?
```

If both report what you expect, you are done. The rest of this file is the
detail behind those four commands.

---

## 1. What is on the network

Two systems, two protocols. Audio and telemetry share `192.168.3.0/24` since
the 2026-09-07 migration — **plus `192.168.1.0/24` for any board still carrying
a pre-migration image**.

### Audio — UDP, boards push to the host

| device | address | UDP port | direction | rate |
|---|---|---|---|---|
| soundcard 1 | `192.168.3.101` | 5005 | board → host | 11.4 Mbit/s @ 24 kHz |
| soundcard 2 | `192.168.3.102` | 5006 | board → host | 11.4 Mbit/s |
| soundcard 3 | `192.168.3.103` | 5007 | board → host | 11.4 Mbit/s |
| soundcard 4 | `192.168.3.104` | 5008 | board → host | 11.4 Mbit/s |

Control (gain, 48 V phantom) goes the other way over the **same** UDP path —
`udp_rx_core` does not filter on port, so any port reaches it.

### Telemetry — TCP, host dials the buoys

All on **port 8080**, addressing is `192.168.3.1<buoy><role>`:

| role | | buoy 1 | buoy 2 | buoy 3 | buoy 4 | module |
|---|---|---|---|---|---|---|
| 0 | `$GDAT2` telemetry | `.110` | `.120` | `.130` | `.140` | `gdat2.py` |
| 1 | WitMotion IMU | `.111` | `.121` | `.131` | `.141` | `witmotion.py` |
| 2 | Ping1D altimeter | `.112` | `.122` | `.132` | `.142` | `ping1d.py` |

**The host is the TCP client** — the aux_vcu listens and we dial it (confirmed
on hardware 2026-08-19). `gdat2.Link` also has a `server` mode kept for a
future unit that dials in; you will not normally need it.

### Host

| | |
|---|---|
| audio + control, current boards | `192.168.3.10` — `C_PC_IP` in the `*_192-168-3-*` images |
| audio + control, older boards | `192.168.1.10` — `C_PC_IP` in anything older |
| telemetry | any address on `192.168.3.0/24`; `.10` serves both |

**Both audio addresses are required** while boards of both generations are in
use — see the box at the top of this file. They coexist on one NIC.

**No address collides.** Soundcards `.101`–`.104`, buoys `.110`–`.142`, host
`.10` on each subnet.

---

## 2. Configure the adapter

### Both required addresses

```powershell
netsh interface ipv4 set address name="Ethernet" static 192.168.3.10 255.255.255.0
netsh interface ipv4 add address name="Ethernet" 192.168.1.10 255.255.255.0
```

No gateway, no DNS. Check the adapter name first with `Get-NetAdapter` if it is
not called "Ethernet".

One NIC, two addresses, two subnets — Windows handles this natively and there
is no performance cost. Drop the second one only when **every** board has been
reflashed and verified on `192.168.3.x`.

`192.168.3.10` is load bearing **twice**: it is where the boards send audio,
*and* it is the filter deciding whose ARP the boards will learn from
(`pc_mac_r` in `top_system.vhd`). Get it wrong and nothing arrives.

> ⚠ **Unicast UDP is filtered by DESTINATION address.** A socket bound to
> `INADDR_ANY` still only receives packets addressed to an IP this host
> actually owns — the kernel drops the rest before any socket sees them.
> Measured on this machine:
>
> ```
> destination      host owns it?   received?
> 192.168.3.10     yes             YES
> 192.168.3.10     NO              NO      <- silently dropped
> ```
>
> This is why the address is not optional and why "the board is transmitting,
> Wireshark sees it, Python sees nothing" is a host configuration fault.

### Why the second address is not optional

Boards flashed before the migration were built with `C_PC_IP = 192.168.1.10`.
They send audio **only** to that address and learn ARP **only** from it. There
is no fallback and no negotiation — `C_PC_IP` is a compile-time constant.

So a `192.168.1.x` board on a host that holds only `192.168.3.10` is invisible:
it transmits flawlessly, the frames appear in Wireshark, and the host kernel
discards every one of them at the IP layer before any socket sees it. That is
indistinguishable from a dead board unless you know to look.

`discover.py` reports **MIXED SUBNETS** when it sees boards on both, so the
state is visible rather than silent — but only for boards it can actually
receive from, which is exactly why both addresses must be present first.

The host tools handle the mixed case throughout: `capture()` binds
`INADDR_ANY`, `discover.py` reads each board's real source address, and
`ctrl.resolve_node()` sends control to wherever the board actually is.

### Retiring the old subnet

Once every board is reflashed **and verified with `discover.py`**, drop the old
address and simplify the tooling:

```powershell
netsh interface ipv4 delete address name="Ethernet" 192.168.1.10
```

then edit `ctrl.KNOWN_SUBNETS` down to `["192.168.3"]`.

### Verify

```powershell
Get-NetIPAddress -AddressFamily IPv4 | Where-Object { $_.IPAddress -notlike '169.254.*' } |
    Select-Object InterfaceAlias, IPAddress | Format-Table -AutoSize
```

Expect **both** `192.168.3.10` and `192.168.1.10` on the wired adapter. If
`192.168.1.10` is missing, any board still carrying an older image will appear
completely dead.

---

## 3. Firewall

Windows Firewall silently drops inbound UDP. Without this rule the boards look
dead while transmitting perfectly.

```powershell
New-NetFirewallRule -DisplayName "TDM_UATR audio" -Direction Inbound `
    -Protocol UDP -LocalPort 5005-5008 -Action Allow -Profile Private
```

Telemetry needs **no rule** — the host opens those TCP connections outbound,
and the replies are part of an established connection.

If you prefer to allow the interpreter rather than the ports, allow `python.exe`
on the private profile. Either works.

---

## 4. Watch out for a second interface on the same subnet

Windows picks a route by interface metric, and two interfaces claiming
`192.168.3.0/24` is ambiguous. This has bitten this project before: the Wi-Fi
used to join a *different* `192.168.3.0/24` (the building network, ~29
unrelated hosts), so a reply from `192.168.3.x` proved nothing about which
segment answered.

Check:

```powershell
Get-NetIPAddress -AddressFamily IPv4 | Select-Object InterfaceAlias, IPAddress
route print -4 | Select-String "192.168.3"
```

If Wi-Fi also holds a `192.168.3.x` address, make the wired adapter win:

```powershell
Set-NetIPInterface -InterfaceAlias "Ethernet" -InterfaceMetric 5
```

Also remove any stray extra address on the same subnet (e.g. a leftover
`192.168.3.240`) — two addresses on one subnet can confuse *outbound* source
selection for control commands:

```powershell
netsh interface ipv4 delete address name="Ethernet" 192.168.3.240
```

---

## 5. Which image, and what it costs on the wire

Two image sets exist. They are the **same design** — same 16 channels, same
24-bit samples, same packet layout, same addressing. The only difference is
whether the on-FPGA decimator is in the signal path.

| | `96K_*` | `24K_*` |
|---|---|---|
| `C_DECIMATE` | false | true |
| sample rate | 96 kHz | 24 kHz |
| usable band | 0–42 kHz (ADC limit) | **0–11 kHz** |
| logic used | 3,429–3,455 LE (55%) | 5,308–5,343 LE (85%) |

### Where the 4× comes from

Every packet carries exactly 8 audio frames at either rate, so **the packet
size never changes — only how often one is sent**:

```
                          96 kHz        24 kHz
audio frames per packet        8             8
packets per second        12,000         3,000     <- the only thing that changes
bytes per packet             476           476
```

Which gives, per board:

```
                          96 kHz          24 kHz
audio payload         36.864 Mbit/s    9.216 Mbit/s   16ch x 24bit x fs
+ 10-byte header      39.360           9.840          UDP payload
+ eth/IP/UDP hdrs     45.696          11.424          ON THE WIRE
                      -------------   -------------
of 100BASE-TX           45.7%           11.4%
```

Four boards:

```
                          96 kHz          24 kHz
aggregate            182.784 Mbit/s   45.696 Mbit/s
of 100BASE-TX            183%  <- does not fit      46%
of gigabit                18%                        4.6%
disk, all 4 boards      18.4 MB/s       4.6 MB/s
                        66 GB/hour      16 GB/hour
```

### Why the wire figure is bigger than the audio

The 476 bytes on the wire per 410 bytes of payload is **86% efficiency**, and
the overhead is fixed per packet:

```
410 B  UDP payload      (10-byte header + 8 frames x 50 B)
 +8 B  UDP header
+20 B  IPv4 header
+14 B  Ethernet header
       -----
452 B  frame body
 +8 B  preamble + start-frame delimiter
 +4 B  Ethernet FCS
+12 B  inter-frame gap
       -----
476 B  actually occupied on the link
```

Because that 66 bytes is **per packet**, sending 4× fewer packets saves the
overhead 4× over as well — which is why the wire rate scales cleanly by 4.00
and not slightly less.

### What this decides

| | |
|---|---|
| **96 kHz, four boards** | 183 Mbit/s — **needs a gigabit NIC and uplink.** Does not fit 100BASE-TX |
| **24 kHz, four boards** | 46 Mbit/s — fits 100BASE-TX end to end, including the 7 km fibre link |

The four **board** links stay at 100 Mbit either way, since each carries only
its own stream. It is the **switch uplink and the host NIC** that must be
gigabit for the 96 kHz set.

Packet rate matters more than bit rate in practice: 48,000 pkt/s across four
Python processes is where drops actually appear, and 12,000 pkt/s is
comfortable. See §9.

Telemetry is 0.9 Mbit/s total, under 2% of the audio either way. It has never
been a constraint.

### Choosing

Use **`24K_*`** unless you need content above 11 kHz. It costs nothing in
quality inside that band — 0.00015 dB passband ripple, −102.5 dB alias
rejection, below the converter's own noise floor — and it removes the gigabit
requirement, cuts host CPU 4×, and quarters the disk rate.

Use **`96K_*`** if you need the full 0–42 kHz the ADC passes, or as the
fallback: it is the configuration that has actually run on hardware.

---

## 5a. Which .jic to flash — there are 97 of them

`output_files/` has accumulated every image ever built. Only eight are current.

### Use these

Built 2026-09-08 15:18–15:25 in one locked run. They carry both decimator
fixes and the 192.168.3.x addressing.

```
24K_NODE1_192-168-3-101.jic      96K_NODE1_192-168-3-101.jic
24K_NODE2_192-168-3-102.jic      96K_NODE2_192-168-3-102.jic
24K_NODE3_192-168-3-103.jic      96K_NODE3_192-168-3-103.jic
24K_NODE4_192-168-3-104.jic      96K_NODE4_192-168-3-104.jic
```

All eight verified distinct by MD5, TNS 0.0 on all five timing checks.

### ⚠ Do NOT flash these

`24K_NODE*_192-168-1-*.jic` (2026-09-07 23:29–23:33) — the **first** decimator
build, carrying both bugs that were found afterwards:

- misaligned pipeline: every coefficient multiplied the wrong sample, so all
  16 channels would be noise
- schedule overrun: engine 2 needed 1,440 cycles against 1,024, so output
  frames were dropped silently

They look like ordinary images and the filename gives no hint. Delete them:

```bash
rm output_files/24K_NODE*_192-168-1-*.jic
```

### Keep as fallback

`96K_NODE*_192-168-1-*.jic` (2026-08-29) — the last images **known good on
hardware**. Pre-decimation, pre-migration, so they need the host to hold
`192.168.1.10`. Keep them until the new set has been proven wet.

`96K_ACT.jic` is the older single-board reference for the same reason.

### The naming rule

```
<RATE>_NODE<n>_<board-ip>.jic
  |       |        |
  |       |        +-- must match the board you are about to flash
  |       +----------- 1-4, sets MAC, IP and UDP port
  +------------------- 24K = decimating, 96K = plain
```

**Check the number in the filename against the board actually connected.**
Four near-identical images per set is exactly where the wrong one lands on the
wrong board, and the symptom — two boards claiming one IP — reads as a network
fault rather than a flashing mistake.

```
quartus_pgm -m jtag -o "pi;output_files/24K_NODE2_192-168-3-102.jic"
ping 192.168.3.102
arp -a | findstr 192.168.3.102        # expect de-ad-be-ef-00-02
```

The MAC in the ARP table proves you flashed the image you meant to.

---

## 6. Verify — audio

```
python python/discover.py
```

Passive: it binds the four stream ports and listens, transmits nothing, and
cannot disturb a capture in progress. It reports each board's **actual** source
address and **measured** sample rate, so it works without knowing anything in
advance.

Healthy four-board array on the decimating build:

```
  node 1  port 5005   192.168.3.101    24000 Hz     3000 pkt/s  loss 0.000%
  node 2  port 5006   192.168.3.102    24000 Hz     3000 pkt/s  loss 0.000%
  node 3  port 5007   192.168.3.103    24000 Hz     3000 pkt/s  loss 0.000%
  node 4  port 5008   192.168.3.104    24000 Hz     3000 pkt/s  loss 0.000%

  4 board(s) answering.
  subnet   192.168.3.x
  rate     24000 Hz  (decimating 24K_* image)
  offered  45.7 Mbit/s aggregate to this host
```

It names three failure modes explicitly:

| message | meaning |
|---|---|
| **MIXED SUBNETS** | a board is still on `192.168.1.x` — wrong image, or migration incomplete |
| **MIXED SAMPLE RATES** | 24K and 96K images mixed. Each board is fine but they are **not** sample-aligned |
| **MORE THAN ONE SENDER ON THIS PORT** | two boards share an address or port; every capture on that port is meaningless |

Then capture — one process per board, each on its own port:

```
python python/udp_monitor.py -p 5005 -s 10
python python/udp_monitor.py -p 5006 -s 10
python python/udp_monitor.py -p 5007 -s 10
python python/udp_monitor.py -p 5008 -s 10
```

The sample rate is **detected from the packet rate**, so a 24K and a 96K board
are both read correctly with no flag. `--rate 96000` overrides if you need it.

⚠ With `--wav`, give each one its own prefix (`--wav node1`, `--wav node2`, …).
Filenames are `"%s_ch%02d.wav" % (prefix, channel)` and carry no port or
address, so four monitors sharing a prefix silently overwrite each other.

### Control

Use `resolve_node` so a command follows the board rather than assuming a
subnet:

```python
import ctrl
ip = ctrl.resolve_node(3)              # 192.168.3.103 or 192.168.1.103
ctrl.send_gain(ch, val, ip=ip)
```

From the shell:

```
python python/ctrl.py --node 3 --all 0x60      # +24 dB, see docs/DECIMATION.md
python python/ctrl.py --node 3 --phantom status
```

---

## 7. Verify — telemetry

```
python python/imu_test.py                 # dials the active buoy
python python/gdat2.py   --buoy 3         # $GDAT2 telemetry
python python/witmotion.py --buoy 3       # IMU / attitude
python python/ping1d.py  --buoy 3         # altimeter
```

`--buoy N` resolves the address through `buoy_ip()`, so it cannot be mistyped.
To dial something else explicitly, all three take `--connect HOST[:PORT]`:

```
python python/gdat2.py  --connect 192.168.3.130
python python/ping1d.py --connect 192.168.3.132:8080
```

Offline checks that need no hardware — worth running once on a new machine to
prove the decoders work before blaming the link:

```
python python/gdat2.py     --selftest
python python/witmotion.py --selftest
python python/ping1d.py    --selftest
python python/gdat2.py     --sim      # run a fake source to point a client at
python python/ping1d.py    --sim
```

`gdat2.ACTIVE_BUOY` names the unit in service (currently **buoy 3**) and
`DEFAULT_HOST` follows it, so a bare `python imu_test.py` dials a buoy that
exists rather than whichever is first in the table. Change it in that one place
when the active unit changes.

Always use `gdat2.buoy_ip(n, role)` rather than literals. Three roles one digit
apart is the easiest kind of address to mistype, and a wrong digit reaches a
**real device that is simply not the one you meant** — so the symptom is a
decoder finding nothing, not a connection error.

### The discriminator when a link connects but stays quiet

**A GDAT2 source streams on connect without being asked.** If `.1x0:8080`
accepts the connection and then sends nothing, you are probably talking to a
web config page on the wrong port, not a silent aux_vcu. Sweep for the real
port:

```
python python/altimeter_probe.py --buoy 3 --role 1
```

An `Embedthis-http` server was once found doing exactly this on what is now
buoy 3's IMU address.

### Two things that look like faults and are not

- **Attitude repeating exact values** — the firmware quantises attitude to
  0.1°, so a still buoy legitimately repeats one value. `imu_test.py` reports
  **UNPROVEN**, never a fault, and asks for motion instead of guessing.
- **Fields reading zero** — Altimeter dist/conf (use the Altimeter tab, it is
  its own device), Voltage monitor, and Depth are known dead or unreliable on
  this firmware.

---

## 8. The GUI

```
python python/mixer_gui.py                 # everything, four AFE tabs + buoys
python python/mixer_gui.py --nodes 1,3     # only the boards you have
python python/mixer_gui_standalone.py      # single file, no local imports
```

Each AFE tab owns its own socket on that board's own stream port and its own
control IP, both derived from `ctrl.py`. Hidden tabs keep draining their
sockets so the loss counters stay honest. Each tab shows **that board's**
measured rate, so a mixed array displays correctly.

⚠ `mixer_gui_standalone.py` is **generated**. Never edit it — edit the real
modules and re-run:

```
python python/make_gui_standalone.py           # rebuild
python python/make_gui_standalone.py --check   # fail if stale
```

---

## 9. If you are writing the deployment app

Measured on this machine, and it decides the architecture:

```
socket receive, 64 MB SO_RCVBUF           59,650 pkt/s   0.00% loss
full 24-bit unpack, ONE packet at a time  30,800 pkt/s   <-- below 48,000
batched numpy (1000 packets at once)     161,000 pkt/s
```

**A naive loop that unpacks each datagram as it arrives drops packets at
96 kHz**, and it looks exactly like a network fault.

> Receive into a list. Never unpack inside the receive loop. Unpack in
> vectorised batches on another thread or after capture.

That is what `udp_monitor.capture()` already does. Preserve the structure.

Also:

- **`SO_RCVBUF` to 64 MB** on every socket. The default is ~64 kB and overflows
  in milliseconds at these rates.
- **One socket per board**, one thread each. Do not multiplex four boards onto
  one socket — `recv()` discards the sender, so four sequence-number streams
  would interleave and the loss report would be meaningless.
- **Never block the receive thread** on disk, GUI or DSP. Queue it.
- The GIL is not a problem: `recv()` releases it, and numpy releases it during
  vectorised work. Threads suffice; multiprocessing is not needed.
- **Replace lost packets, never skip them.** At 24 kHz one lost 8-frame packet
  shifts everything after it by 333 µs = **50 cm of acoustic path**,
  permanently and cumulatively. Zero-fill with a short fade preserves timing;
  hold-last-value does not. Better still, flag the window so GCC-PHAT can
  exclude it rather than correlate on invented data.

---

## 10. Troubleshooting

| symptom | first thing to check |
|---|---|
| `discover.py` finds nothing | are **both** `192.168.3.10` and `192.168.1.10` on the wired adapter? Firewall rule present? |
| some boards found, others silent | the silent ones are on the subnet whose host address is missing — §2 |
| board pings but no packets arrive | host does not own the address the image sends to — §2 |
| packets arrive, host sees none | firewall, or another process already holds the port |
| `--phantom status` reports nothing | a mixer GUI or `udp_monitor` holds that port. On Windows two sockets can both bind with `SO_REUSEADDR` while only one receives |
| packet rate 4× too high | `valid_out` ignored downstream — the decimator integration bug, not a network fault |
| enormous packet loss | check `discover.py` for **MORE THAN ONE SENDER**; otherwise host-side, see §9 |
| telemetry connects, sends nothing | wrong port or a web config page — §7 |
| works on Wi-Fi, not Ethernet | two interfaces on `192.168.3.0/24`; fix the metric — §4 |

---

## 11. Cross-board timing — read before anything coherent

**Each board free-runs off its own 50 MHz crystal.** The four sample clocks are
independent. At ±50 ppm the relative drift reaches 100 ppm — at 24 kHz that is
**2.4 samples per second**, and one sample is 6.25 cm of acoustic path at
1500 m/s.

| processing | free-running OK? |
|---|---|
| 16-channel standalone | yes — one PLL per board |
| four bearings → cross-fix | **yes** — each bearing is computed inside one board |
| TDOA / multilateration between boards | **no** |
| one coherent 64-element aperture | **no** |

No host configuration changes this. Networking makes four streams arrive at one
machine; it does not make them share a clock. See `docs/MULTI_BOARD.md` for the
1 Hz SYNC-pulse proposal that would.

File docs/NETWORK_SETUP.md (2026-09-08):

# Running four boards and four buoys on one PC

Written 2026-09-07, when the soundcards moved to `192.168.3.x` — the subnet the
buoy telemetry already occupies.

Short answer: **yes, one PC handles everything, and there is no collision.**
The capacity numbers are not close. But the *addressing* now needs care that it
did not before, because two systems that used to be on separate subnets are on
one.

---

## 1. What is on the network

| device | address | port | protocol | traffic |
|---|---|---|---|---|
| soundcard 1 | `192.168.3.101` | 5005 | UDP → host | 11.4 Mbit/s |
| soundcard 2 | `192.168.3.102` | 5006 | UDP → host | 11.4 Mbit/s |
| soundcard 3 | `192.168.3.103` | 5007 | UDP → host | 11.4 Mbit/s |
| soundcard 4 | `192.168.3.104` | 5008 | UDP → host | 11.4 Mbit/s |
| host PC | `192.168.3.10` | — | — | — |
| buoy 1 telemetry / IMU / altimeter | `.110` `.111` `.112` | 8080 | TCP ← host | ~0.2 Mbit/s |
| buoy 2 | `.120` `.121` `.122` | 8080 | TCP ← host | ~0.2 Mbit/s |
| buoy 3 | `.130` `.131` `.132` | 8080 | TCP ← host | ~0.2 Mbit/s |
| buoy 4 | `.140` `.141` `.142` | 8080 | TCP ← host | ~0.2 Mbit/s |

**No address collides.** Soundcards use `.101`–`.104`, buoys use `.110`–`.142`,
host is `.10`.

---

## 2. Capacity — the numbers, not an opinion

```
soundcards, 24 kHz    4 x 11.4 Mbit/s   =  45.7 Mbit/s
telemetry             4 x  0.2 Mbit/s   =   0.9 Mbit/s
                                           -----------
total offered                              46.6 Mbit/s
```

Against a **1 Gbit** host NIC that is **4.7% utilised**. Against 100 Mbit it is
47%, which also fits but with far less margin.

The telemetry is negligible — it is under 2% of the audio. It was never the
constraint and is not one now.

### At 96 kHz it does not fit 100 Mbit

```
soundcards, 96 kHz    4 x 45.7 Mbit/s   = 182.8 Mbit/s
telemetry                                   0.9 Mbit/s
                                           -----------
total                                     183.6 Mbit/s
```

**Gigabit is mandatory** for the 96K images on four boards. This is the single
biggest practical reason to run the decimating build: 4× decimation is what
takes the array from "needs gigabit end to end" to "fits in 100BASE-TX".

### Where the real bottleneck is

Not the wire. On a dedicated path with no competing traffic, 7 km of
single-mode fibre at BER 1e-12 drops roughly one frame per day, and the FPGA
side reports **zero sequence gaps**.

The bottleneck is **the host**: packets per second, not bits per second.

```
96 kHz:  4 boards x 12,000 pkt/s  =  48,000 pkt/s
24 kHz:  4 boards x  3,000 pkt/s  =  12,000 pkt/s
```

Every packet is a syscall, a kernel buffer copy and a Python loop iteration.
48,000/s across four Python processes is where drops actually appear, and they
appear as "packet loss" that looks like a network fault. Decimation cuts this
4×, which is the most effective loss-resilience change available.

---

## 2a. Measured, not assumed — Python's real capacity

Everything below was measured on this machine, because "Python is too slow" is
usually asserted and rarely tested. The answer is that Python is fine, **but
only if the app is written one particular way.**

### Receive capacity: not the problem

```
one socket, 64 MB SO_RCVBUF, blast test   59,650 pkt/s   0.00% loss
four sockets, four senders, 12,000 pkt/s   0.0000% loss
```

59,650 pkt/s on a single socket is above the **48,000 pkt/s** that four 96 kHz
boards produce, and 5× the 12,000 pkt/s of four decimating boards. Socket
receive is not the bottleneck.

### Per-packet processing: this IS the bottleneck

```
header parse only                     539,000 pkt/s
numpy reshape                         502,000 pkt/s
full 24-bit unpack, ONE packet at a time  30,800 pkt/s   <-- the trap
```

**30,800 pkt/s is below the 48,000 needed for four 96 kHz boards.** A naive
loop that unpacks each datagram as it arrives will drop packets at 96 kHz, and
it will look exactly like a network fault.

### The fix: batch the unpack

Accumulate raw datagrams, unpack many at once with one vectorised numpy call:

```
batch  100 packets    168,000 pkt/s
batch 1000 packets    161,000 pkt/s
batch 3000 packets    190,000 pkt/s
```

**~6× headroom even at 96 kHz.** The rule for the deployment app:

> Receive into a list. Never unpack inside the receive loop. Unpack in
> vectorised batches on a separate thread or after capture.

That is what `udp_monitor.capture()` already does — it appends raw bytes and
parses afterwards — and it is why it keeps up. Preserve that structure when
lifting the code into the PyQt application.

### What this means per configuration

| configuration | pkt/s | naive per-packet | batched |
|---|---|---|---|
| 4 boards @ 24 kHz | 12,000 | ✅ 2.5× margin | ✅ 16× margin |
| 4 boards @ 96 kHz | 48,000 | ❌ **0.64× — drops** | ✅ 4× margin |

Decimation makes even the naive approach viable. Batching makes both viable.
Do both.

### Also required in the app

- **`SO_RCVBUF` to 64 MB** on every socket (`udp_monitor.py:46` does this). The
  default is ~64 kB and overflows in milliseconds at these rates.
- **One socket per board**, one thread each. Do not multiplex four boards onto
  one socket — see the port discussion below.
- **Never block the receive thread** on disk, GUI, or DSP work. Queue it.
- The GIL is not a problem here: socket `recv()` releases it, and numpy releases
  it during vectorised work. Threads are sufficient; multiprocessing is not
  needed at these rates.

---

## 3. Why there is no collision

Four mechanisms, each doing a different job:

**Separate IP addresses** — every device is individually addressed. Unicast
UDP, so a switch forwards each board's stream only to the host port.

**Separate UDP ports per board** (5005–5008). This is deliberate and load
bearing: `udp_monitor.capture()` uses `recv()`, not `recvfrom()`, so it
discards the sender address. Four boards on one port would interleave four
independent sequence-number streams into one socket and `loss_report` would
report enormous loss that is not real. `discover.py` detects this case
explicitly and says **"MORE THAN ONE SENDER ON THIS PORT"**.

**Unicast, not broadcast.** `C_PC_MAC` was once `FF:FF:FF:FF:FF:FF` with the
comment *"Broadcast until ARP resolves"* — and nothing ever resolved it. On one
board that is untidy; on four it is fatal, because broadcast is flooded to
every switch port and is never suppressed by MAC learning. Each board's 100
Mbit port would have received all four streams. `pc_mac_r` now learns the real
MAC from any ARP originating at `C_PC_IP`.

**Different transports.** Audio is UDP push from the boards; telemetry is TCP
that the host opens outbound. They do not contend for the same sockets or the
same code path.

### The one real contention risk

**Two capture processes binding the same port.** On Windows two sockets can
both `bind()` the same UDP port with `SO_REUSEADDR` while **only one receives** —
measured on this machine; the second binds without error and then sits silent.

So if `ctrl.py --phantom status` reports nothing arrived, check whether a mixer
GUI or `udp_monitor` already holds that port. This is a host-side problem that
looks exactly like a dead board.

---

## 3a. Both subnets work, at the same time

The host tools support `192.168.1.x` and `192.168.3.x` simultaneously. This is
not a mode to select — it is how they are built:

| path | mechanism | subnet-dependent? |
|---|---|---|
| **receiving audio** | `capture()` binds `INADDR_ANY` | **no** — any subnet, always |
| **identifying a board** | `discover.py` reads the source address via `recvfrom` | **no** — the board reports itself |
| **sending control** | `ctrl.resolve_node(n)` | **no** — follows the board's live address |
| **default when silent** | `ctrl.SUBNET` | falls back to `192.168.3` |

`ctrl.resolve_node(n)` is the one to use in the app. It listens on the node's
stream port, takes the source address of the first packet, and sends the command
there — so a board still running an old `192.168.1.x` image is controlled
correctly with no flag and no configuration. If the board is silent it falls
back to `SUBNET`, which is right for a board being configured before it streams.

```python
ip = ctrl.resolve_node(2)          # wherever node 2 actually is
ctrl.send_gain(ch, val, ip=ip)
```

Verified: with a live sender on the port, `resolve_node` returns the sender's
real address rather than the configured one.

⚠ **The host still needs an address on each subnet it wants to reach.** Being
able to *identify* a board on `192.168.1.x` does not mean packets can *reach*
it. During a migration add the second address:

```powershell
netsh interface ipv4 add address name="Ethernet" 192.168.1.10 255.255.255.0
```

And note that boards built with the old image have the old `C_PC_IP` compiled
in — they will only send to, and learn ARP from, `192.168.1.10`. Both addresses
must be present and both must match what those images expect.

---

## 4. Configuring the PC

### The one required setting

Set the **wired** adapter to a static address on the array's subnet:

```
IP address    192.168.3.10
Subnet mask   255.255.255.0
Gateway       (leave empty)
DNS           (leave empty)
```

```powershell
netsh interface ipv4 set address name="Ethernet" static 192.168.3.10 255.255.255.0
```

`192.168.3.10` is `C_PC_IP`, compiled into every image. It is load bearing
twice: it is where audio is sent, **and** it is the filter deciding whose ARP
the boards will learn from. Get it wrong and nothing arrives.

`check_sync.py` asserts the RTL and `ctrl.py` agree on this — but it cannot
check what the adapter is actually set to. That part is on you.

### Firewall

Windows Firewall silently drops inbound UDP. Allow Python on the private
profile, or the boards look dead while transmitting perfectly:

```powershell
New-NetFirewallRule -DisplayName "TDM_UATR audio" -Direction Inbound `
    -Protocol UDP -LocalPort 5005-5008 -Action Allow -Profile Private
```

### Gigabit if running 96 kHz

The four board links stay at 100 Mbit — each carries only its own stream. The
**switch uplink and the host NIC** must be gigabit for the 96K images. For the
24K images 100 Mbit is sufficient throughout.

### Wi-Fi: the trap worth knowing

This laptop's Wi-Fi also joins a `192.168.3.0/24` network — the building
network, with ~29 unrelated hosts on it. **A matching subnet is not the same
network.** Getting a reply from `192.168.3.x` proves nothing about which segment
answered.

With the soundcards now also on `192.168.3.x`, Windows has two interfaces
claiming the same subnet, and route metrics decide which one is used. If
captures fail while `ping` works, this is the first thing to check:

```powershell
route print -4 | Select-String "192.168.3"
Get-NetIPAddress -AddressFamily IPv4 | Format-Table InterfaceAlias, IPAddress
```

The wired interface must own the `192.168.3.0/24` route for the array. The
cleanest fix is to lower the wired adapter's `InterfaceMetric` so it wins:

```powershell
Set-NetIPInterface -InterfaceAlias "Ethernet" -InterfaceMetric 5
```

If the buoys are reached over Wi-Fi and the soundcards over Ethernet, and both
are `192.168.3.0/24`, **that ambiguity is unavoidable and will bite.** The
robust answer is to put them on genuinely different subnets — see
`docs/CHANGING_IP.md`, which is a ten-minute change now that the subnet is a
single constant on each side.

---

## 5. Verifying it works

```
python python/discover.py
```

Passive — binds the four stream ports, transmits nothing, and reports each
board's **actual** address, **measured** sample rate, and packet loss. It needs
no configuration and makes no assumption about what is out there, which is the
point: a board flashed with the wrong image is working perfectly and is not the
board you think it is.

Expected, all four healthy on the decimating build:

```
  node 1  port 5005   192.168.3.101    24000 Hz     3000 pkt/s  loss 0.000%
  node 2  port 5006   192.168.3.102    24000 Hz     3000 pkt/s  loss 0.000%
  node 3  port 5007   192.168.3.103    24000 Hz     3000 pkt/s  loss 0.000%
  node 4  port 5008   192.168.3.104    24000 Hz     3000 pkt/s  loss 0.000%

  4 board(s) answering.
  subnet   192.168.3.x
  rate     24000 Hz  (decimating 24K_* image)
  offered  45.7 Mbit/s aggregate to this host
```

### How the rate is detected, and the trap it avoids

`fs = packets/second × 8`, because every packet carries exactly 8 audio frames
at both rates. No configuration, no help from the bitstream.

⚠ **Loss only ever lowers the measured rate, and the two rates are exactly 4×
apart.** A 96 kHz board losing 75% of its packets measures 24,000 — and would
be reported as a perfectly healthy 24 kHz board.

`detect_rate()` closes this by using the **sequence numbers** when they are
available: the FPGA increments them per packet *sent*, so the span between the
first and last received tells you how many it sent regardless of how many
arrived. Both `udp_monitor.py` and `discover.py` pass them.

```
96 kHz board, 75% loss:
   without sequence numbers  ->  24000 Hz, "confident"   (wrong)
   with sequence numbers     ->  96000 Hz, "confident"   (right)
```

Below ~15% loss the raw packet rate is enough on its own; the sequence-number
path is what makes the pathological case safe.

`discover.py` calls out three failure modes by name:

| it says | meaning |
|---|---|
| **MIXED SUBNETS** | a board is on the old `192.168.1.x` — wrong image flashed, or migration incomplete |
| **MIXED SAMPLE RATES** | 24K and 96K images are mixed. Each board is individually fine but they are not sample-aligned |
| **MORE THAN ONE SENDER ON THIS PORT** | two boards share an address or port. Every capture on that port is meaningless |

Then capture all four at once — one process per board, each on its own port:

```
python python/udp_monitor.py -p 5005 -s 10
python python/udp_monitor.py -p 5006 -s 10
python python/udp_monitor.py -p 5007 -s 10
python python/udp_monitor.py -p 5008 -s 10
```

`udp_monitor` now **detects the rate from the packet rate** and follows the
board, so no flag is needed whichever image is loaded. `--rate` overrides.

⚠ With `--wav`, give each one its own prefix (`--wav node1`, `--wav node2`, …).
The filenames are `"%s_ch%02d.wav" % (prefix, channel)` and carry no port or
address, so four monitors sharing a prefix silently overwrite each other.

---

## 6. Cross-board timing — unchanged by any of this

**Each board free-runs off its own 50 MHz crystal.** The four sample clocks are
independent time bases. At ±50 ppm the relative drift reaches 100 ppm — at
24 kHz that is **2.4 samples per second**, and one sample is 6.25 cm of acoustic
path at 1500 m/s.

| processing | OK free-running? |
|---|---|
| 16-channel standalone | yes — one PLL per board |
| four bearings → cross-fix | **yes** — each bearing is computed inside one board |
| TDOA / multilateration between boards | **no** |
| one coherent 64-element aperture | **no** |

Nothing in this document changes that. Networking makes the four streams arrive
at one host; it does not make them share a clock. See `docs/MULTI_BOARD.md` for
the 1 Hz SYNC-pulse proposal that would.

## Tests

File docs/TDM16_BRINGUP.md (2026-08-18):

# TDM16 bring-up — what to do with the board

> **STATUS 2026-08-18: NOT THE ACTIVE CONFIGURATION. The tree is back on TDM8.**
>
> TDM16 was built and the image `output_files/96K_TDM16.jic` is kept, but the
> timing analysis that followed showed the capture path was never the fault —
> `sdata_in` setup slack is **+10.651 ns** and hold **+8.494 ns** worst corner
> against a 40.695 ns period, with the full 18 ns `tABDD` and the cable round
> trip already budgeted in the SDC. Merging all four parts onto one net would
> therefore have added drivers and stub length to a net whose signal integrity is
> the actual open question, in exchange for dropping 24-bit samples to 16-bit.
>
> This document stays valid as the procedure **if** TDM16 is revisited. The
> switch is four register values in `adau_sequencer.vhd` and one instantiation in
> `top_system.vhd`; both files carry a comment block naming exactly what changes.

Image: `output_files/96K_TDM16.jic`
Fallback: `output_files/96K_LRCLK_FIX.jic` (TDM8, keep this — see "If it goes wrong")

---

## 1. What changed and why it fits

All four ADAU1978s move onto **one** SDATA net and take four slots each out of
sixteen, instead of two nets carrying eight slots each.

| | TDM8 (before) | TDM16 (now) |
|---|---|---|
| slots per frame | 8 | 16 |
| BCLKs per slot | 32 | 16 |
| **BCLKs per frame** | **256** | **256** |
| BCLK | 24.576 MHz | 24.576 MHz |
| data width | 24-bit | **16-bit** |
| SDATA nets used | 2 | 1 |

The frame is the same 256 BCLKs either way, so **BCLK, LRCLK, the PLL and
`tdm8_master` are all unchanged**. That is the whole reason this configuration was
chosen: it is the only TDM16 option that does not raise the clock. Per ADAU1978
Table 10, TDM16 runs at 256/384/512 × fS for 16/24/32-bit slots — 24-bit would
need 384 × fS = 36.864 MHz, which the audio clock domain has no margin for.

**The cost is real: samples are 16-bit, not 24-bit.** That is 8 bits of dynamic
range given up, roughly 48 dB of noise floor. The packet format still carries
24-bit words — each sample is left-justified with a zero low byte — so full scale,
every dBFS reading and every host script stay exactly as they were. The low byte
just always reads zero.

---

## 2. The board change

**Fit one jumper: `R21` pin 1 ↔ `R122` pin 1.**

That joins net `/TDM1` to net `/TDM2`. From the netlist those two nets are:

- `/TDM1` — `R21.1, U19.13, U20.13, U43.10` (FPGA `sdata_in_A`, PIN_32)
- `/TDM2` — `J19.4, J21.4, R122.1, U37.13, U38.13, U43.67` (FPGA `sdata_in_B`, PIN_119)

Pin 1 of each resistor is the signal end, so the two pads are the tidiest place to
bridge. Both FPGA pins then see the same wire; the design reads `sdata_in_A` and
leaves `sdata_in_B` connected but unread, so no QSF or pin change is needed and
removing the jumper later restores the second line immediately.

### The pulldowns: leave both fitted

You asked whether to remove one. **No — leave `R21` and `R122` both in place.**

They are 10 kΩ each. Jumpered together they sit in parallel and become 5 kΩ, which
is still a trivial load for a CMOS output (the ADAU1978 sources milliamps; 3.3 V
across 5 kΩ is 0.66 mA). Their job is to hold the net at a defined level when no
part is driving it, and with four parts sharing one net that job matters *more*
than it did before, not less. Removing one only weakens it.

---

## 3. Why sharing one net is safe — and the one way it isn't

Only one part may drive the net at a time. Two things enforce that:

1. **`DRV_HIZ = 1`** (register 0x09 = 0xF8). The datasheet is explicit: *"1: Unused
   outputs High-Z."* Each part tri-states outside the four slots it owns.
2. **`SAI_CMAP12`/`SAI_CMAP34`** (0x07/0x08) give every part a different four slots:

   | part | addr | slots | 0x07 | 0x08 |
   |---|---|---|---|---|
   | U19 | 0x11 | 1–4 | `0x10` | `0x32` |
   | U20 | 0x31 | 5–8 | `0x54` | `0x76` |
   | U37 | 0x51 | 9–12 | `0x98` | `0xBA` |
   | U38 | 0x71 | 13–16 | `0xDC` | `0xFE` |

**The failure mode to watch for:** both of those depend on the part being
*configured*. This matters here specifically because `/TDM2` has been showing
**zero transitions**, so U37/U38's state is exactly what is not yet established.

Note that `DRV_HIZ`'s **reset default is 0**, not 1 — the datasheet reads *"0:
Unused outputs driven low."* (`i2c_scan.py`'s VERIFY table lists 0x09 reset as
`0xF0`, bit 3 clear.) So a part that powers up but never completes configuration
does **not** sit High-Z; it drives low continuously. Under the jumper that pulls
**all 16 channels to exact zero**, which is a different signature from contention
and easy to misread. This is not new risk: U19 and U20 have shared `/TDM1` through
the same boot window for weeks without damage — it is four parties now instead of
two.

Check the `REGISTER VERIFY` block from `i2c_scan.py` before fitting the jumper. If
U37/U38 verify clean there, they are configured and High-Z, and the jumper is safe.

### What TDM16 can and cannot fix

This is the expectation that matters, and it follows straight from the netlist:

```
/TDM2:  U43.67 -> R122 -> J19.4 ->[cable]-> J21.4 -> U37.13, U38.13
```

The jumper joins `/TDM1` and `/TDM2` **at the FPGA end**. U37/U38's data still has
to cross J19 → cable → J21 to reach the shared net. Therefore:

- **Fault on the FPGA-side `/TDM2` path** (PIN_119, U43.67, that trace) → TDM16
  **recovers** channels 9–16, because their data now arrives via the `/TDM1` trace
  and PIN_32 instead.
- **Fault in the cable, J19/J21, or U37/U38 themselves** → TDM16 changes nothing
  for channels 9–16.

After two cable rebuilds and 0.2 Ω contact measurements, the second is the likelier
of the two. So be clear about what a partial result means: **channels 9–16 still
dead, with byte 9 ≈ byte 8, is a result, not a failure.** It rules out the entire
FPGA-side path and localizes the fault to cable-or-daughterboard — which is more
than three weeks of swapping has produced.

---

## 4. Order of operations

1. Flash `96K_TDM16.jic`.
2. **Before fitting the jumper**, run `python i2c_scan.py`. All four parts should
   verify 0x05 = `0x63` and 0x06 = `0x58`. This confirms the new mode took, and
   confirms U37/U38 are configured (hence High-Z) before you bridge the nets.
3. Fit the jumper `R21.1 ↔ R122.1`.
4. Run `python udp_monitor.py` and read the **SDATA LINE LIVENESS** section first
   (see below), then `python timeline.py` for the per-channel picture.

### Read byte 9 first — it is a direct continuity test on the jumper

Header bytes 8 and 9 carry the raw SDATA edge counters for line A and line B
(`sdata_in_A` on PIN_32, `sdata_in_B` on PIN_119). They count pin transitions
*before* any decoding, so they are independent of alignment, CMAP and slot width.

Line B currently reads **0 across an entire capture**. Once the jumper is fitted,
both FPGA pins are on the same wire, so **byte 9 must jump to roughly byte 8
(~255)**. That single number separates failures that would otherwise look alike:

| byte 9 | ch 1–8 | ch 9–16 | meaning |
|---|---|---|---|
| still 0 | alive | dead | **the jumper is not conducting.** Resolder it. Nothing else is diagnostic yet. |
| ≈ byte 8 | alive | alive | **success.** |
| ≈ byte 8 | alive | dead | jumper good; fault is *not* on the FPGA-side net — see section 3. |
| ≈ byte 8 | **dead** | dead | contention on the shared net. **Jumper off.** |
| ≈ byte 8 | all 16 exact zero | | an unconfigured part is driving low (`DRV_HIZ` = 0 at reset). Check `i2c_scan.py` REGISTER VERIFY. |

Do not skip to the channel table — a dead jumper and a dead daughterboard look
identical there, and byte 9 is the only thing that tells them apart.

---

## 5. If it goes wrong

This image carries three changes at once, so if it misbehaves, separate them in
this order:

1. **Channels 1–8 died when the jumper went on** → contention. Jumper off. This is
   a board/configuration question, not a firmware one.
2. **All channels read as noise, or "misaligned?"** → bit alignment. `C_BIT_ADJ`
   in `tdm16_rx.vhd` is currently `-1`, which is a *prediction* following the LRCLK
   launch-edge fix, not a measured value. Set it back to `0`, rebuild. This is the
   single most likely thing to need adjusting.
3. **Channels appear rotated** (ch 5 carries ch 1's signal, etc.) → `C_CAP_EXTRA`
   off by a whole slot, or a CMAP value wrong. Check the table in section 3.
4. **Channels 9–16 still dead, byte 9 healthy** → not a failure of this build; see
   section 3. Keep the jumper on, keep the image, and move the investigation to the
   cable and daughterboard. The FPGA-side path is now excluded.
5. **Nothing works at all** → flash `96K_LRCLK_FIX.jic` and remove the jumper. That
   is the last image known to give eight good channels.

Also note this is the **first image ever run** with the LRCLK falling-edge launch
fix (see `LRCLK_HOLD_VIOLATION.md`). Hold slack against the ADAU1978's 5 ns tALH
went from −3.853 ns to **+17.077 ns** worst corner. It is the right fix on paper
and has never been on hardware.

---

## 6. Going back to TDM8

No files need reverting — both receivers stay in the project and both are still
compiled in. The switch is:

- `top_system.vhd` — swap the `u_rx : tdm16_rx` instance for the two commented
  `tdm8_rx` instances directly beneath it.
- `adau_sequencer.vhd` — four values, listed in the `REVERTING THIS FILE TO TDM8`
  comment block next to `CMAP12_BY_IDX`.
- Remove the jumper.
- Run `python check_sync.py`. It reads the TDM mode out of the boot ROM and out of
  whichever receiver `top_system` instantiates, so it re-checks itself against the
  new mode automatically and will name anything left inconsistent.

The host scripts (`udp_monitor.py`, `timeline.py`, `i2c_scan.py`) need no changes
in either direction — the wire format is 16 channels × 24-bit big-endian either
way. The only mode-dependent value in them is `i2c_scan.py`'s `VERIFY` table for
0x05/0x06, and `check_sync.py` cross-checks that against the boot ROM, so it cannot
drift silently.

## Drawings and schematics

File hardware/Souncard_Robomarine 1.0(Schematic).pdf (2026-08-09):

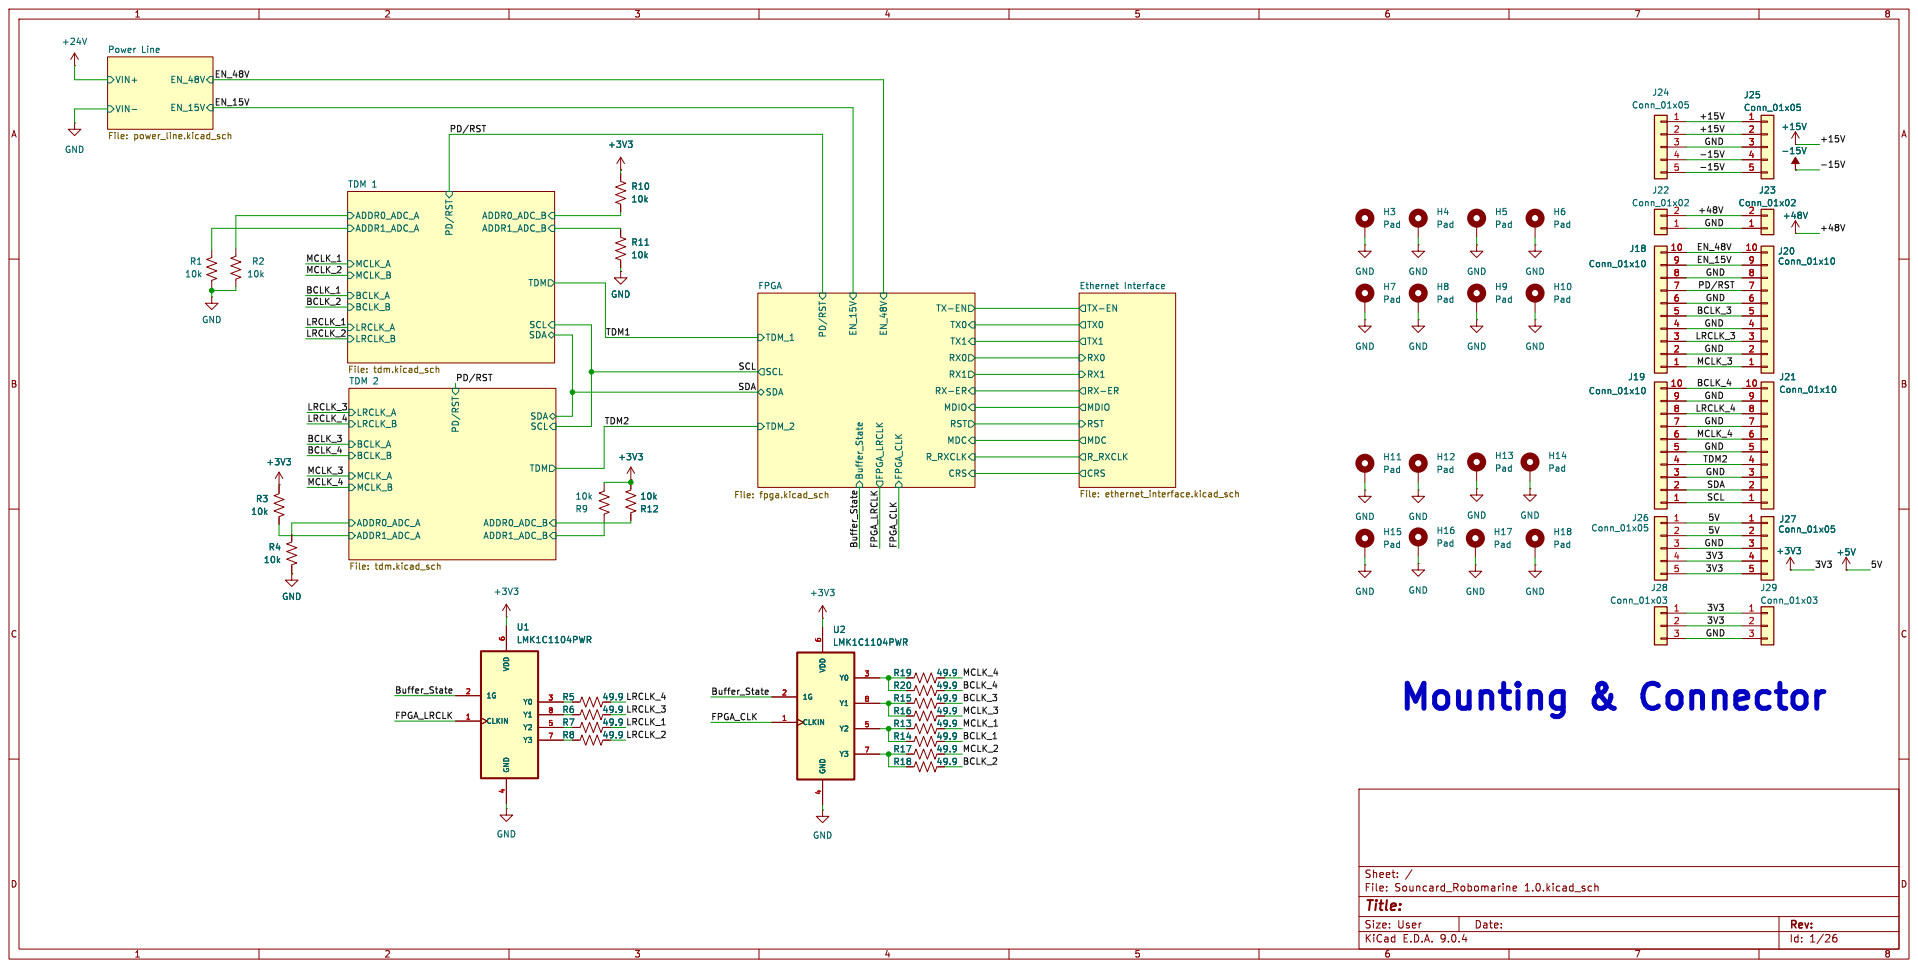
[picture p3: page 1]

TX0 TX1 Ethernet Interface File: ethernet_interface.kicad_sch SCL SDA

File: fpga.kicad_sch SCL SDA

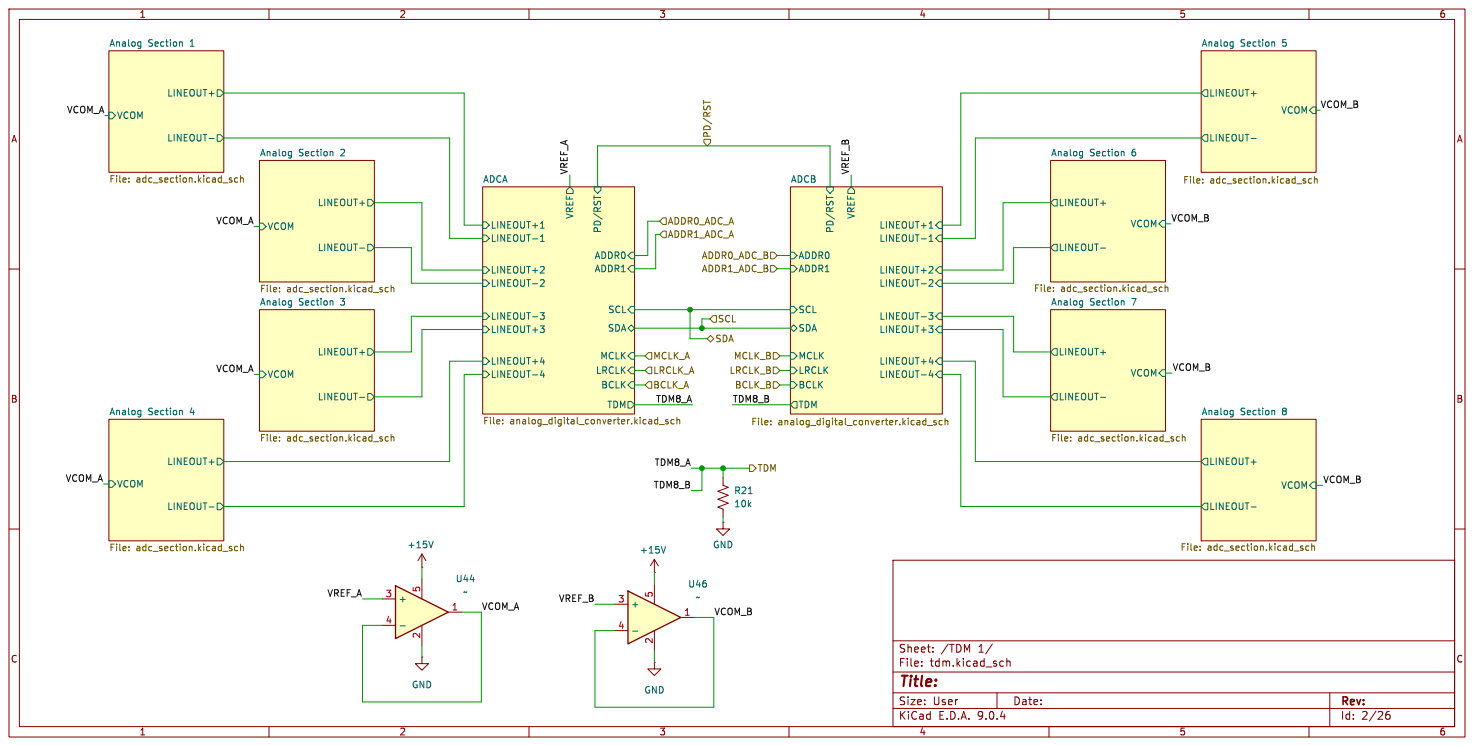
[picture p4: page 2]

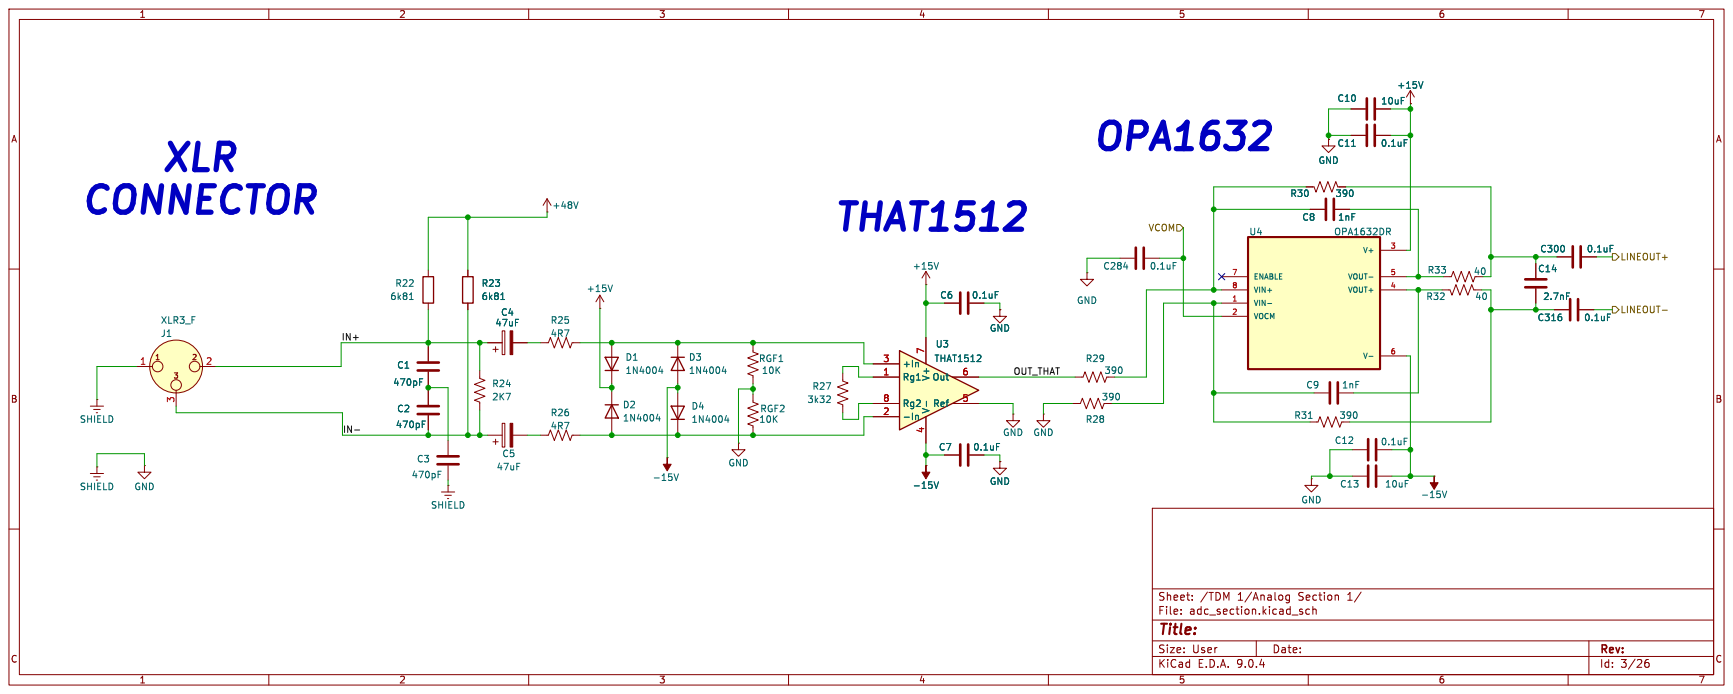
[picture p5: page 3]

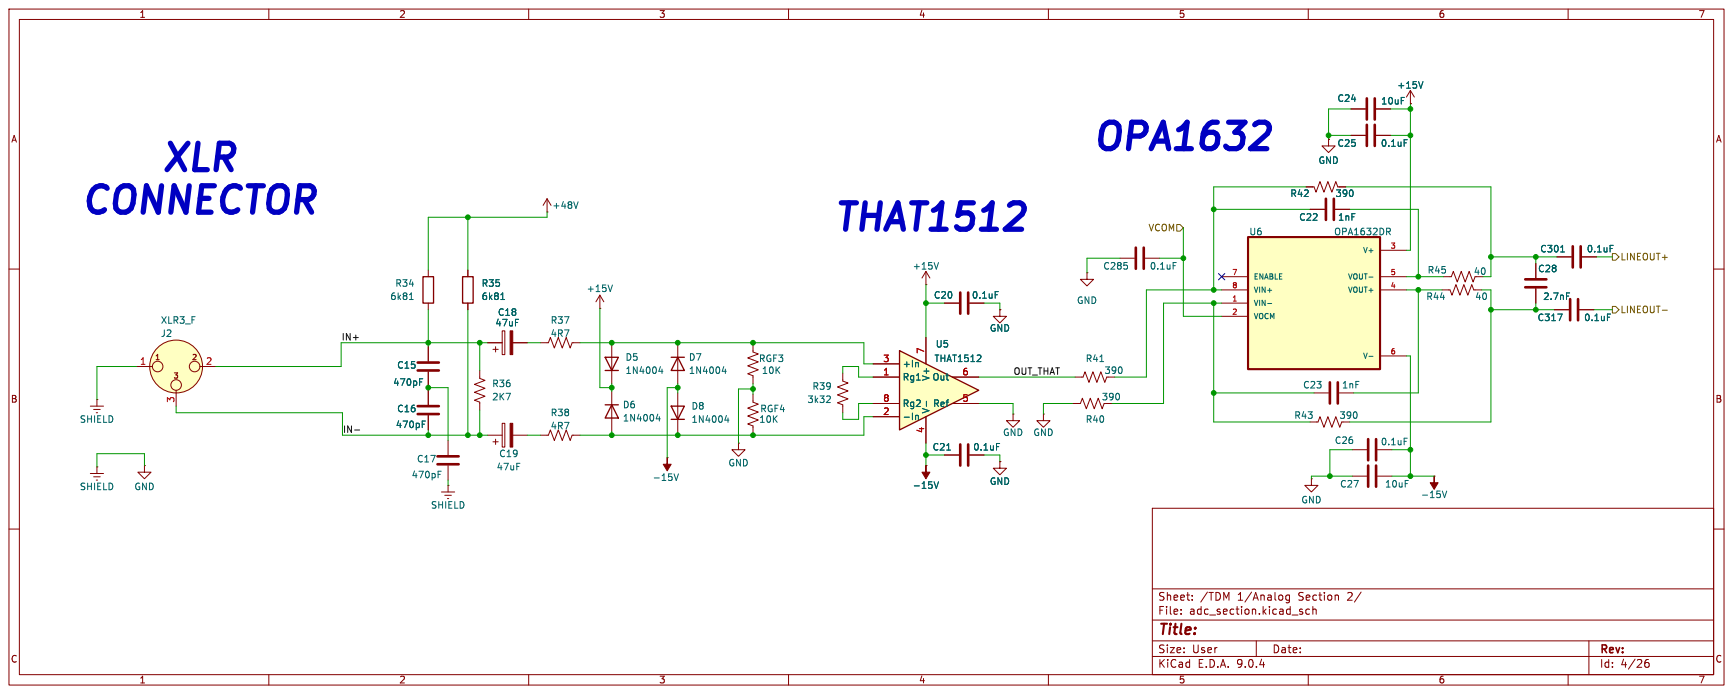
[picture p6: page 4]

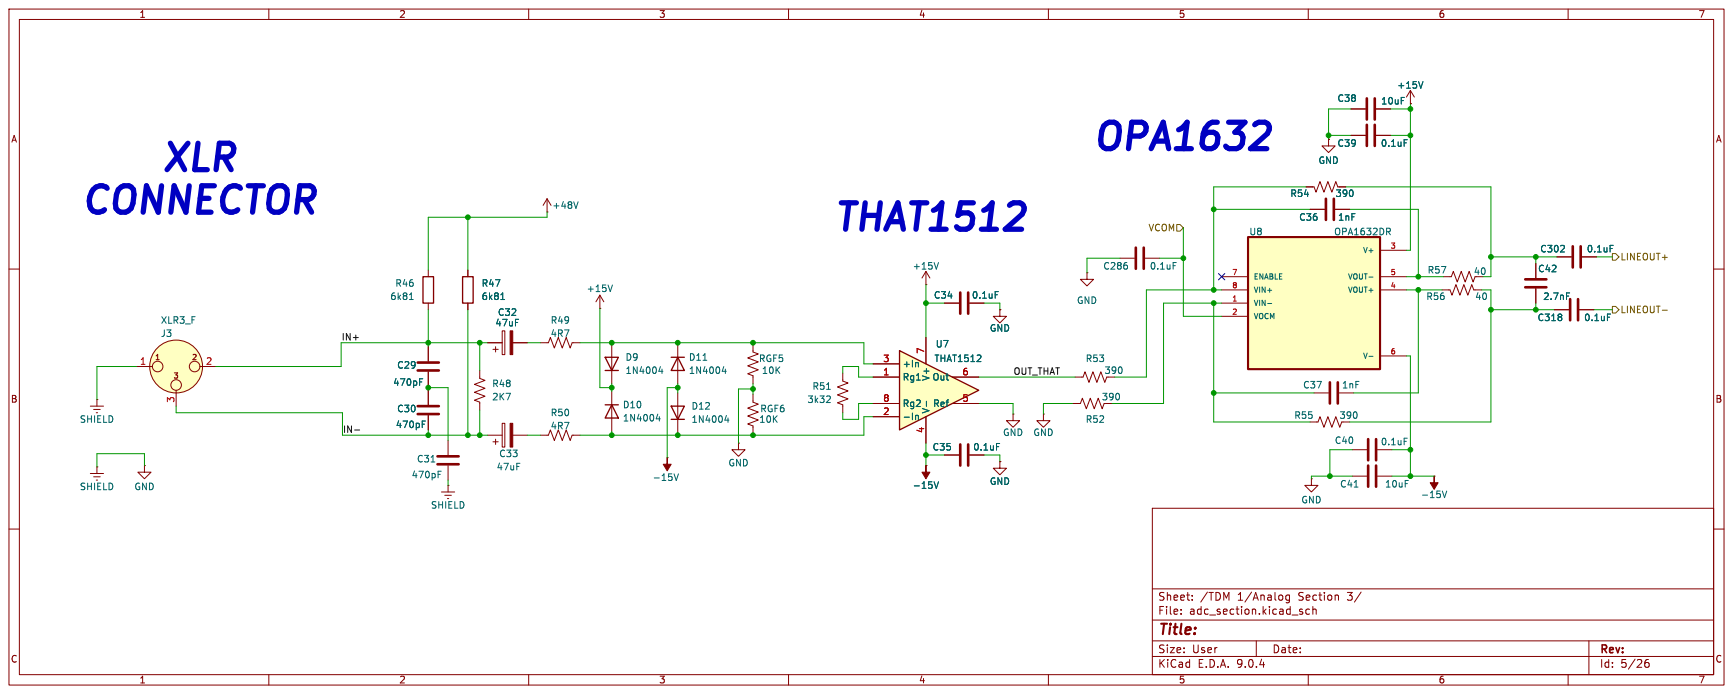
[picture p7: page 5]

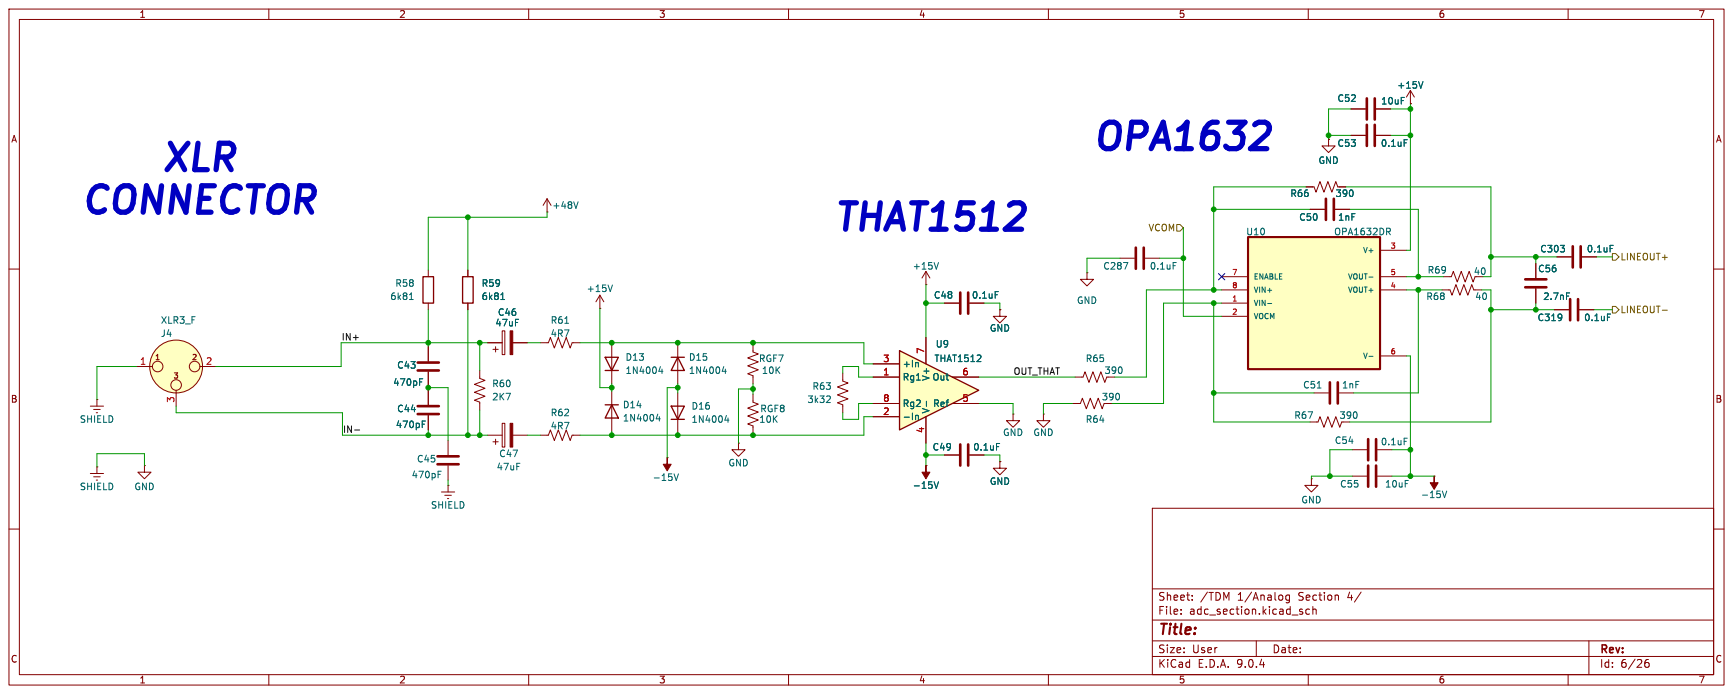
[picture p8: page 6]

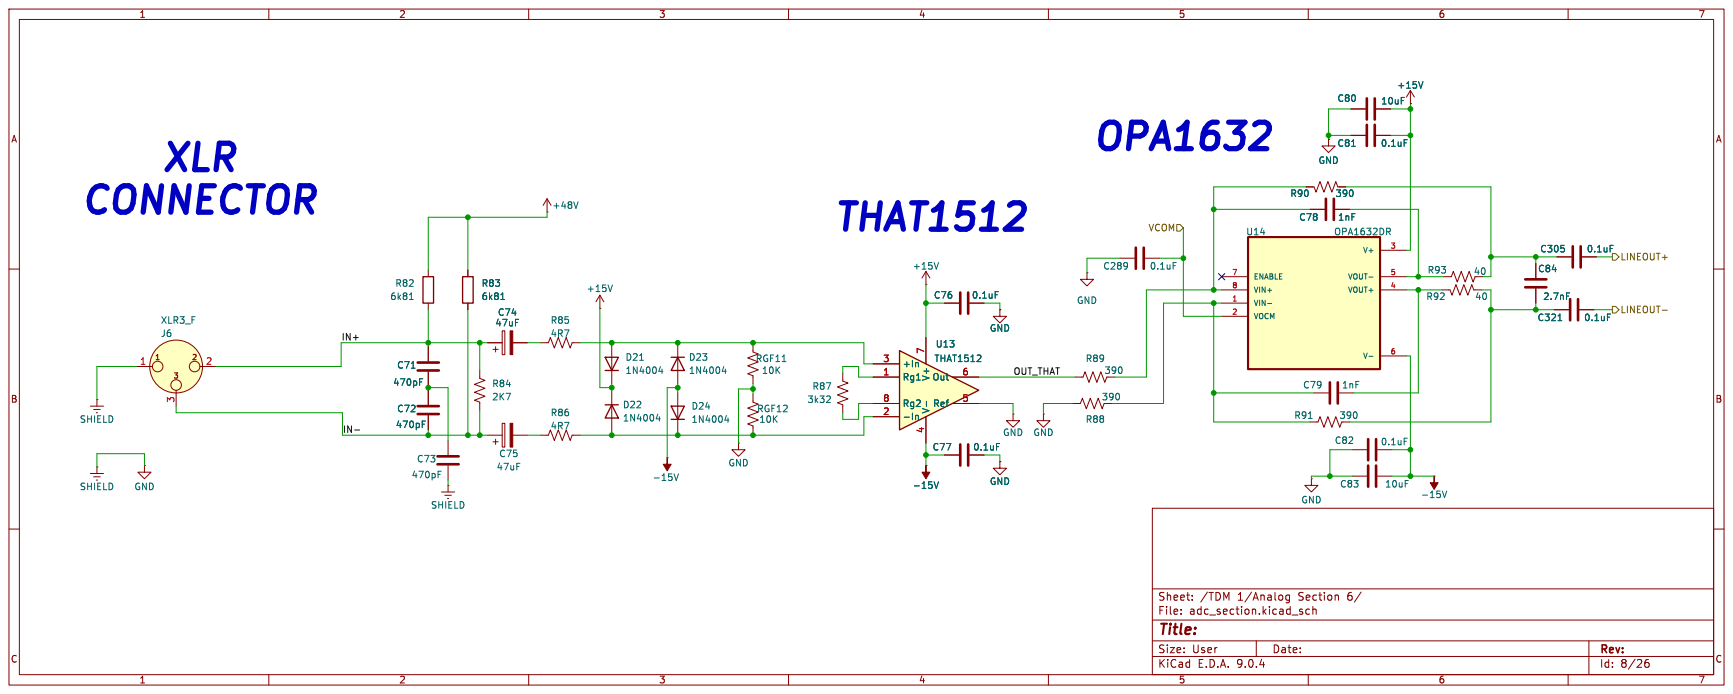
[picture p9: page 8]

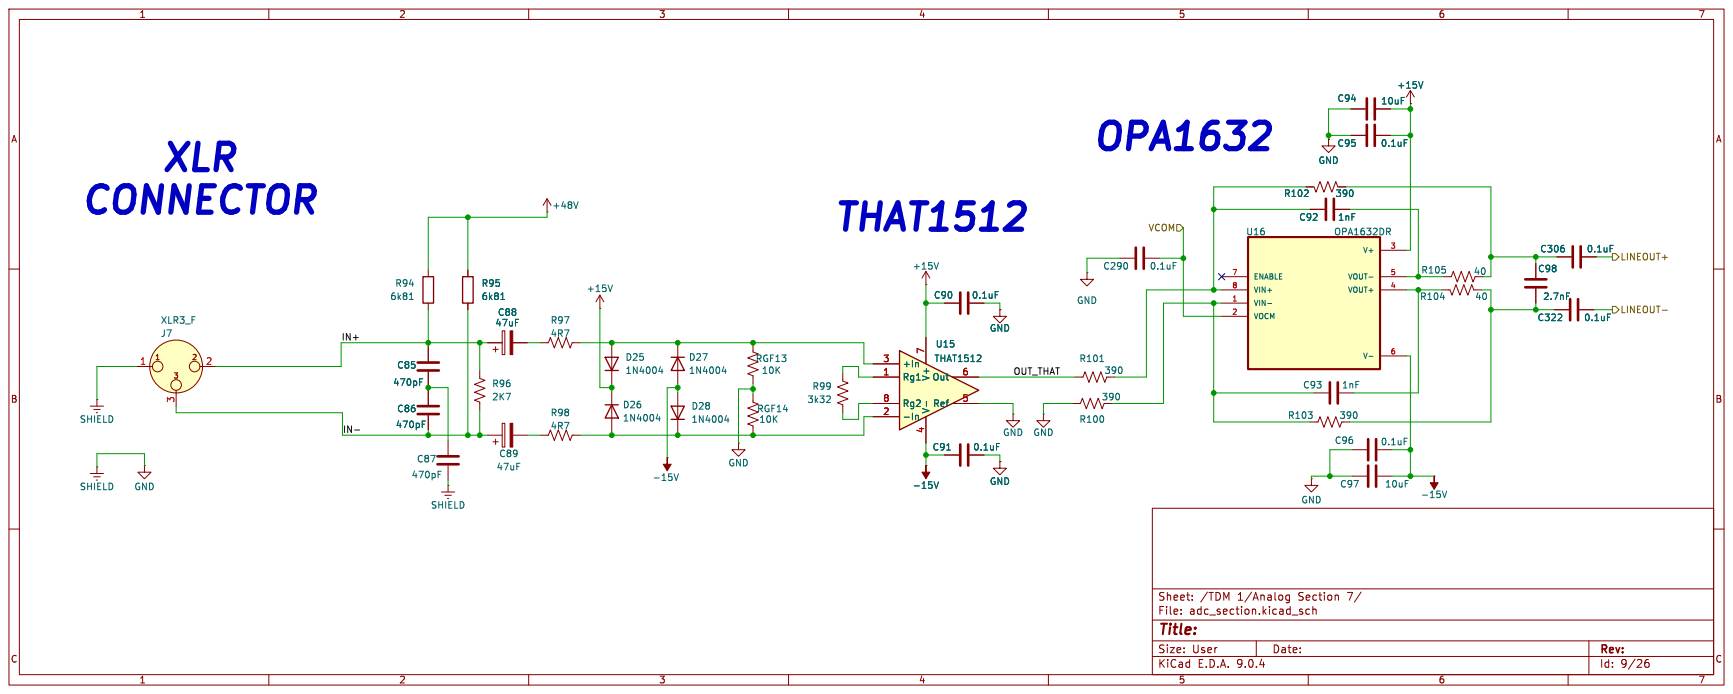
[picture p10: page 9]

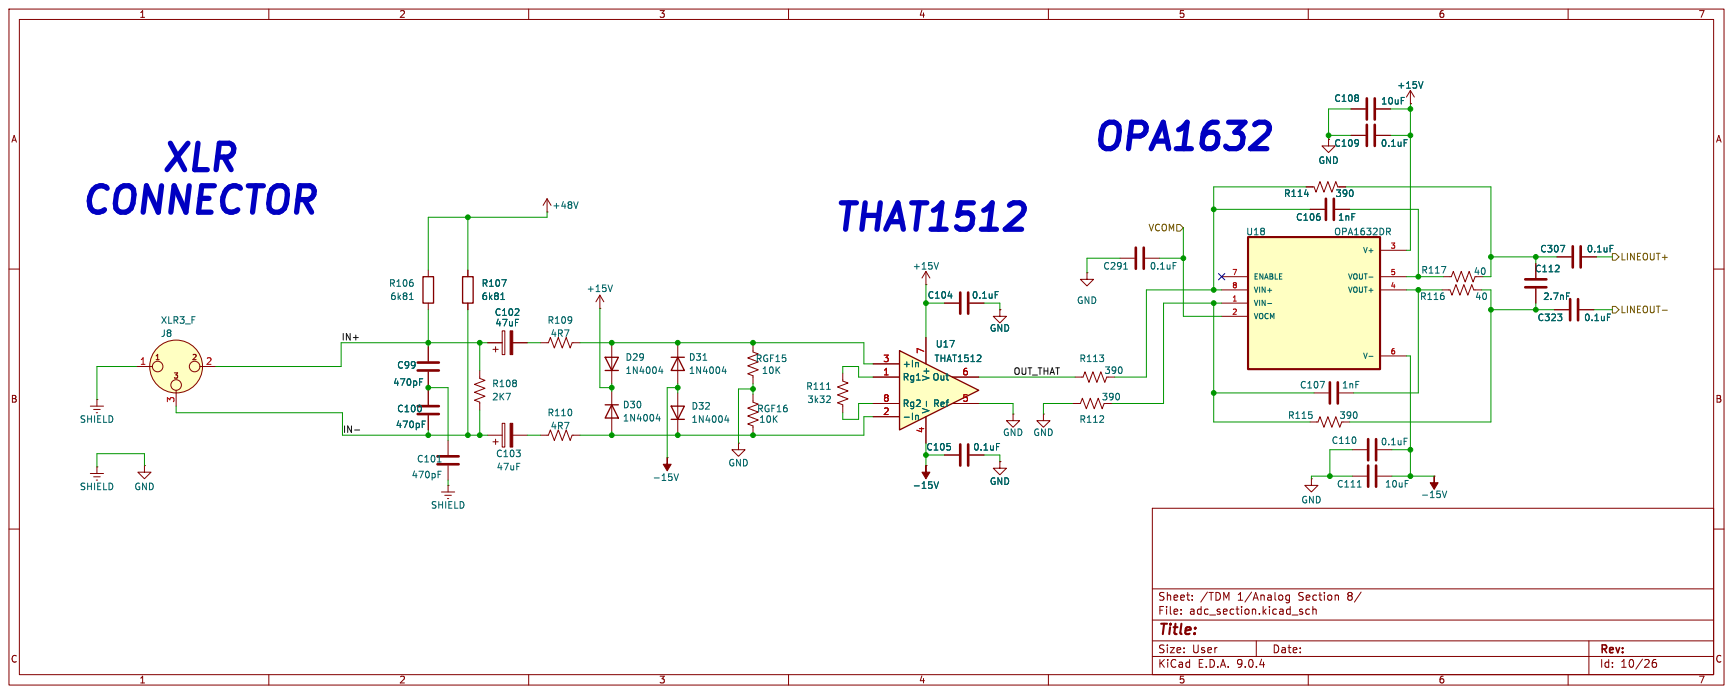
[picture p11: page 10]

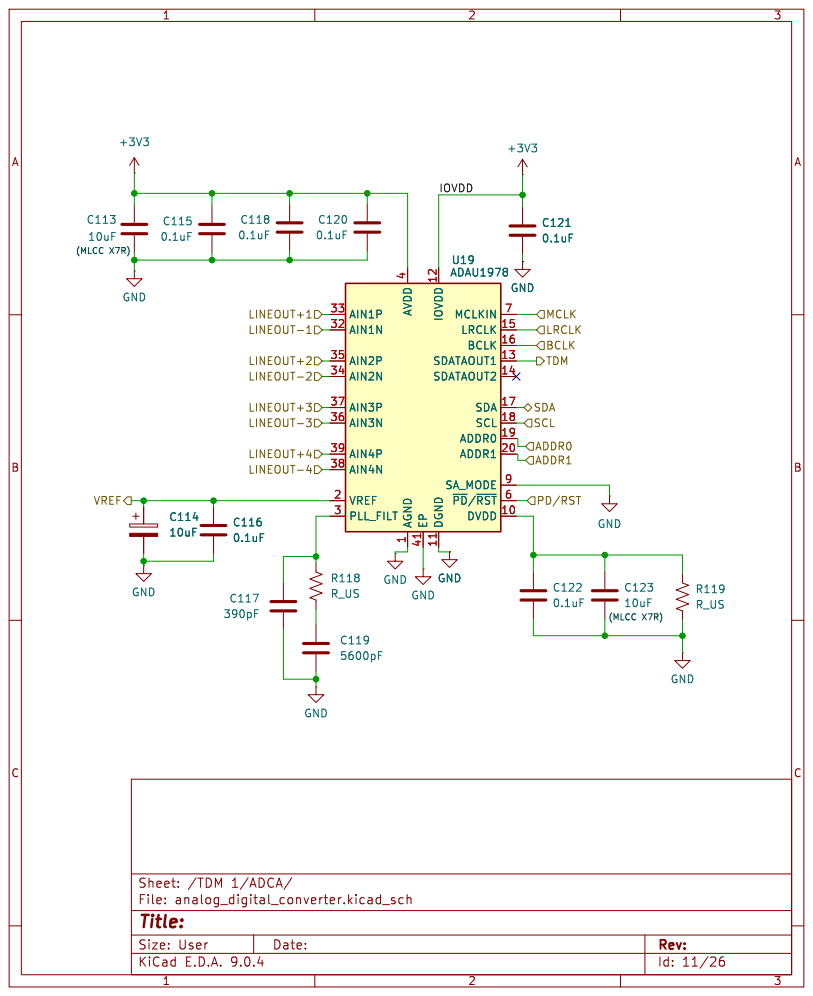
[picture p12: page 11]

1 EP 41 IOVDD 12 DGND 11 MCLKIN 7

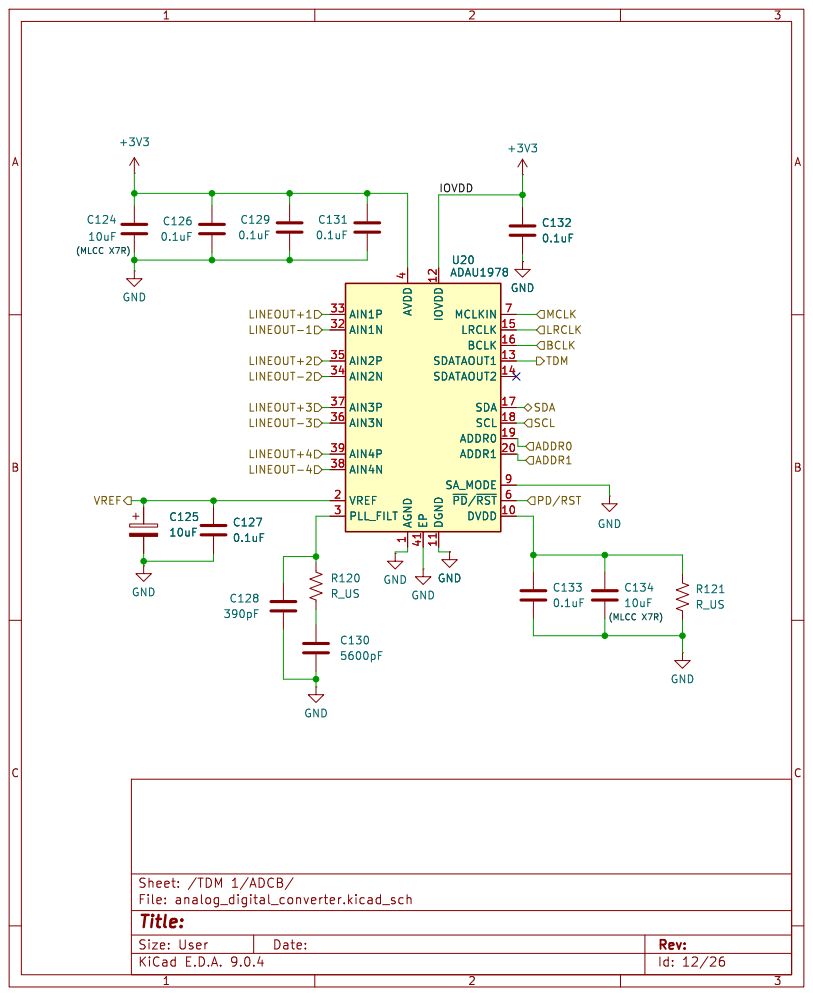
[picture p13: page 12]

1 EP 41 IOVDD 12 DGND 11 MCLKIN 7

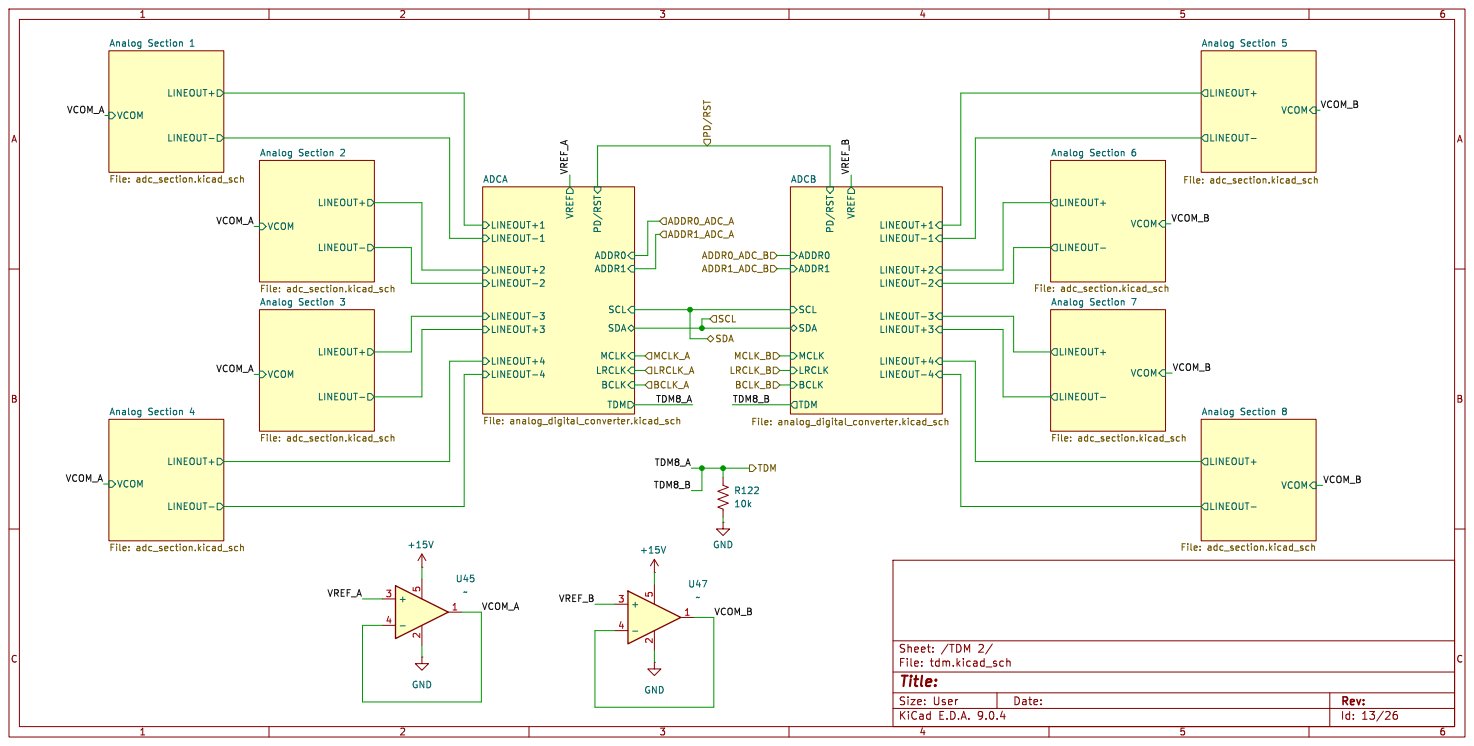
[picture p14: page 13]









1 EP 41 IOVDD 12 DGND 11 MCLKIN 7


1 EP 41 IOVDD 12 DGND 11 MCLKIN 7


3 SS 11 GND 17 SW 16 VC


1 TXP 21 TXN 20 RXP 23 RXN 22 RBIAS 24


FPGA Development Board Altera Cyclone IV

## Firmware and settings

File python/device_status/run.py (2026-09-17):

#!/usr/bin/env python3
"""Open HACAR_dash's Device Status window, vendored whole into this repo.

    python run.py                      # all three tabs, live services
    python run.py --db my.sqlite       # a settings database of your own
    python run.py --no-services        # the bare window, no sockets opened

WHAT OPENS
==========
The window as the console builds it, with its three tabs:

    Buoys       the AFE pages - one sub-tab per unit, each with sixteen
                channel meters, gain faders, channel enable/polarity, and
                the 48 V phantom control
    Telemetry   decoded $GDAT2 fields per unit, link statistics, compass
                and horizon
    Pipeline    built only when a target provider is supplied, which is the
                console's direction-finding stack and is not vendored here

This is a REPLICA, not a reimplementation: every widget, signal and slot is
HACAR_dash's own source, copied by vendor.py with its package paths intact. The
composition below mirrors supersilence/app/main.py - same factories, same
configuration loaders, same argument order.

WHICH TABS APPEAR
=================
The window builds a tab only when the service behind it exists. That is its own
design and it is deliberate; its comment reads "a tab of ten dashes says a field
map is broken when the truth is that telemetry is switched off". So:

    Buoys       whenever either service reports unit_identifiers
    Telemetry   whenever a telemetry service is passed
    Pipeline    only with a target_provider - always absent here

TELEMETRY IS OFF UNTIL YOU ENABLE IT. default_telemetry_configuration() ships
with enabled=False, so a first run opens sockets to nothing. Addresses and the
enable flag live in the settings database; --db keeps them per-file so a
bench setup does not overwrite a deployment one.

WHERE THESE POINT
=================
HACAR_dash's defaults, not this repo's. Its acquisition sources and this array's
192.168.3.101-104 boards are configured independently, and nothing here rewrites
one to match the other - a window that silently retargeted the addresses stored
in its own database would be the least debuggable thing in either repo. Set them
in the database, or point --db at one already holding them.

UPDATING THE COPY
=================
supersilence/ is VENDORED - do not edit it here. Edit HACAR_dash and re-run:

    python vendor.py            # refresh
    python vendor.py --check    # fail if stale
"""

import argparse
import logging
import os
import sys
from dataclasses import replace

HERE = os.path.dirname(os.path.abspath(__file__))
# The vendored tree keeps HACAR_dash's package paths, so every
# `from supersilence.… import …` inside it is left exactly as written. This is
# the one line that makes that true.
sys.path.insert(0, HERE)

from PySide6.QtWidgets import QApplication                       # noqa: E402

from supersilence.features.device_status.ui.window import (      # noqa: E402
    DeviceStatusWindow,
)
from supersilence.infrastructure.acquisition.configuration import (  # noqa: E402
    load_acquisition_configuration,
)
from supersilence.infrastructure.acquisition.factory import (    # noqa: E402
    create_acquisition_service,
)
from supersilence.infrastructure.acquisition.gain_configuration import (  # noqa: E402
    load_channel_gains_db,
)
from supersilence.infrastructure.control.phantom_power import (  # noqa: E402
    PhantomPowerKeepalive,
)
from supersilence.infrastructure.database import migrations       # noqa: E402
from supersilence.infrastructure.database.connection import open_database  # noqa: E402
from supersilence.infrastructure.settings.repository import (    # noqa: E402
    SettingsRepository,
)
from supersilence.infrastructure.telemetry.configuration import (  # noqa: E402
    default_telemetry_configuration,
    load_telemetry_configuration,
)
from supersilence.infrastructure.telemetry.service import TelemetryService  # noqa: E402
from supersilence.shared.ui.theme import apply_base_font         # noqa: E402

logger = logging.getLogger("device_status")


class TelemetryConnection:
    """Owns starting and stopping telemetry, so the window does not have to.

    The window is handed this and calls it; it never touches the service
    itself. That keeps the invariant in the window's own docstring true - it
    owns no services and cannot, by being closed, stop the console receiving.

    Reconfiguring in place rather than building a second service is what makes
    a reconnect visible to everything already holding the first one. See
    TelemetryService.reconfigure.
    """

    def __init__(self, service, configuration):
        self._service = service
        self._configuration = configuration
        self._connected = False

    def start_if_enabled(self):
        """Bring the links up only if the stored configuration says to.

        A bench run that has never been configured opens with the links down
        and the addresses on screen waiting to be tried, rather than dialling
        four loopback addresses nobody asked for.
        """
        if not self._configuration.enabled:
            return False
        self._service.start()
        self._connected = True
        return True

    # -- what the bar shows on construction -------------------------------
    def addresses(self):
        return dict(self._configuration.sensor_addresses)

    def port(self):
        return self._configuration.port

    def connected(self):
        return self._connected

    # -- what the buttons do ----------------------------------------------
    def connect(self, addresses, port):
        """-> "" once the links are starting, else why they are not.

        A started link is not a connected one - the clients dial in their own
        threads and may be reconnecting for a while - so this reports that the
        attempt is under way. Whether a buoy actually answered shows up in the
        per-unit state on the page below, which is the honest place for it.
        """
        try:
            configuration = replace(
                self._configuration,
                enabled=True,
                sensor_addresses=dict(addresses),
                port=int(port),
            )
        except ValueError as error:
            # TelemetryConfiguration validates in __post_init__ - unroutable
            # address, port out of range, or an address colliding with one of
            # the IMU/altimeter roles. Its message already names which.
            return str(error)
        self._service.reconfigure(configuration)
        self._configuration = configuration
        self._service.start()
        self._connected = True
        logger.info("telemetry connecting to %s:%d",
                    ", ".join(sorted(configuration.sensor_addresses.values())),
                    configuration.port)
        return ""

    def disconnect(self):
        self._service.stop()
        self._connected = False
        return ""


def build_services(settings):
    """-> (acquisition_service, telemetry_service, set_phantom_power).

    Mirrors the composition in supersilence/app/main.py. Kept in one function
    so the window is constructed the same way whether it is run from here or
    lifted into something larger later.
    """
    acquisition_configuration = load_acquisition_configuration(settings)
    initial_gains_db = {
        unit: load_channel_gains_db(settings, unit)
        for unit in acquisition_configuration.source_addresses
    }
    acquisition_service = create_acquisition_service(
        acquisition_configuration, initial_gains_db=initial_gains_db)

    try:
        telemetry_configuration = load_telemetry_configuration(settings)
    except ValueError as error:
        # Same handling as the console: a stored configuration that no longer
        # validates must not stop the window opening, because the window is
        # where you would go to look at why.
        logger.error("stored telemetry configuration is invalid; telemetry "
                     "remains disabled: %s", error)
        telemetry_configuration = default_telemetry_configuration()
    telemetry_service = TelemetryService(telemetry_configuration)

    # The 48 V path. A keepalive rather than a single datagram because the
    # firmware drops phantom power on its own if it stops hearing a
    # flags-carrying packet - see the module's docstring, and ctrl.phantom_reason
    # in this repo, which names that watchdog as a distinct cause.
    keepalive = PhantomPowerKeepalive(acquisition_configuration.source_addresses)

    def set_phantom_power(unit_identifier, enabled):
        if unit_identifier not in acquisition_configuration.source_addresses:
            logger.warning("no configured address for unit %s; phantom power "
                           "command dropped", unit_identifier)
            return
        keepalive.request(unit_identifier, enabled)

    connection = TelemetryConnection(telemetry_service, telemetry_configuration)
    connection.start_if_enabled()

    return acquisition_service, telemetry_service, set_phantom_power, connection


def main():
    ap = argparse.ArgumentParser(description=__doc__.splitlines()[0])
    ap.add_argument("--db", metavar="PATH", default=None,
                    help="settings database (default: HACAR_dash's own)")
    ap.add_argument("--no-services", action="store_true",
                    help="open the bare window without starting acquisition "
                         "or telemetry - opens no sockets")
    ap.add_argument("--refresh-ms", type=int, default=200,
                    help="how often the window re-reads its services")
    a = ap.parse_args()

    logging.basicConfig(level=logging.INFO,
                        format="%(levelname)s %(name)s: %(message)s")

    app = QApplication(sys.argv)
    apply_base_font(app)

    settings = acquisition = telemetry = phantom = link = None
    if not a.no_services:
        database = open_database(a.db)
        # open_database only opens; the schema is a separate step, exactly as
        # in main.py. A fresh --db file has no settings table at all until
        # this runs.
        version = migrations.apply_migrations(database)
        logger.info("settings database at schema version %d", version)
        settings = SettingsRepository(database)
        acquisition, telemetry, phantom, link = build_services(settings)

    window = DeviceStatusWindow(
        acquisition,
        telemetry,
        settings=settings,
        phantom_power_control=phantom,
        telemetry_connection=link,
        refresh_interval_ms=a.refresh_ms,
    )
    window.show()
    try:
        return app.exec()
    finally:
        # Both services own threads and sockets. Leaving them running past the
        # window turns a closed GUI into a process that is still receiving.
        for service in (acquisition, telemetry):
            stop = getattr(service, "stop", None) or getattr(service, "close", None)
            if stop is not None:
                try:
                    stop()
                except Exception:               # noqa: BLE001 - shutdown path
                    logger.exception("failed to stop %r", service)


if __name__ == "__main__":
    sys.exit(main())

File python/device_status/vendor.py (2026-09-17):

#!/usr/bin/env python3
"""Vendor HACAR_dash's Device Status window into this repo, imports unchanged.

    python vendor.py                 # copy / refresh supersilence/
    python vendor.py --check         # fail if the copy is out of date
    python vendor.py --list          # what would be copied, and how big

WHY A SCRIPT AND NOT A HAND COPY
================================
The same argument make_gui_standalone.py makes about the telemetry field map.
A hand-maintained copy of another project's source drifts the moment that
project changes, and it drifts SILENTLY: the window still opens, still paints,
and still shows numbers - just not the ones the other repo is now producing.
A copy that is REGENERATED cannot drift, and `--check` says so out loud.

WHAT IS COPIED
==============
The transitive import closure of supersilence.features.device_status, and
nothing else. That is a real boundary rather than a guess: this window was
written to be HANDED its acquisition and telemetry services rather than to
import them, so the closure stops at the service interfaces instead of
dragging in the whole console. 46 files at the time of writing, against a
source tree many times that.

Package paths are preserved, so every `from supersilence.… import …` inside the
copied files is left exactly as written - which is the point of vendoring the
tree rather than flattening it the way the mixer GUI is flattened.

WHERE THE SOURCE COMES FROM
===========================
$SUPERSILENCE_SRC if set, else ../../../HACAR_dash/src, i.e. a sibling checkout
of this repo. Pass --src to override. A missing source is not an error for
--check when the copy already exists: this repo has to stay buildable on a
machine that does not have HACAR_dash checked out at all.
"""

import argparse
import ast
import collections
import os
import shutil
import sys

HERE = os.path.dirname(os.path.abspath(__file__))
DEST = os.path.join(HERE, "supersilence")
PKG = "supersilence"

# WHAT THE COPY IS SEEDED FROM. The window alone is only the view - it is handed
# its services and builds a tab only when the service behind it exists, so
# seeding on the feature package alone produces a window that opens and says
# "No acquisition or telemetry service is running." The services are named here
# as well, so what lands in this repo is the working thing rather than its
# shell.
#
# A directory is walked whole; a dotted module is taken with its closure.
SEEDS = (
    "supersilence.features.device_status",            # the window and its tabs
    "supersilence.infrastructure.acquisition.factory",   # create_acquisition_service
    "supersilence.infrastructure.telemetry.service",     # TelemetryService
    "supersilence.infrastructure.settings.repository",   # persisted gains, offsets
    "supersilence.infrastructure.database",              # the SQLite schema behind it
    "supersilence.infrastructure.control.phantom_power",  # the 48 V command path
)

# ------------------------------------------------------ local work, pending --
# THE VALVE DOES NOT EXIST UPSTREAM. `grep -rn RMCMD` over HACAR_dash returns
# nothing: that project has never had an actuator. The files below are ours,
# written in its architecture so they can be merged back, and until they are
# this script must not treat them as drift.
#
# Without this, the two halves of the tool both do the wrong thing: `--check`
# calls our new modules ORPHANs and our edits STALE, and a plain `vendor.py`
# DELETES the new files and overwrites the edited ones with the upstream
# version. That second one is the reason this list is not merely cosmetic.

#: Ours entirely. Copied from nowhere, so never stale and never orphaned.
LOCAL_ONLY = frozenset({
    os.path.join(PKG, "infrastructure", "telemetry", "valve.py"),
    os.path.join(PKG, "features", "device_status", "domain", "valve.py"),
    os.path.join(PKG, "features", "device_status", "ui", "valve_control.py"),
    os.path.join(PKG, "features", "device_status", "ui", "claw.py"),
    os.path.join(PKG, "features", "device_status", "ui", "telemetry_connection.py"),
})

#: Upstream files carrying local edits. A refresh would throw those edits away,
#: so refreshing one is refused unless --force says to, and then it is on the
#: operator to re-apply them.
LOCALLY_MODIFIED = frozenset({
    # send(), the only write path on a client that otherwise only reads.
    os.path.join(PKG, "infrastructure", "telemetry", "tcp_client.py"),
    # send_valve_command(), and reconfigure() for the connect button.
    os.path.join(PKG, "infrastructure", "telemetry", "service.py"),
    # The connect bar on the telemetry tab, and the handlers behind it and the
    # valve.
    os.path.join(PKG, "features", "device_status", "ui", "window.py"),
    # The Valve box beside Compass / Artificial horizon / Altimeter, and the
    # IMU row dropped from the role status bar.
    os.path.join(PKG, "features", "device_status", "ui", "attitude_instruments.py"),
    # The two altimeter rows, fed from the Ping1D link instead of reading zero.
    os.path.join(PKG, "features", "device_status", "ui", "telemetry_fields.py"),
})

DEFAULT_SRC = os.path.normpath(
    os.path.join(HERE, "..", "..", "..", "HACAR_dash", "src"))


def module_path(src, mod):
    """Dotted module name -> its file, or None if it is not a module here."""
    base = os.path.join(src, *mod.split("."))
    for cand in (base + ".py", os.path.join(base, "__init__.py")):
        if os.path.isfile(cand):
            return cand
    return None
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

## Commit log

2026-05-09 added 7 segment display to check. Step 2 donefirst
    [stp1.stp, stp1_auto_stripped.stp, stp2.stp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]
2026-08-08 Bring up 16-channel ADAU1978 capture: 96 kHz, 24-bit, 12 of 16 channels live
    Ethernet, I2C, ADC configuration and TDM capture all working end to end.
    Audio data reaches the PC over UDP at 96 kHz / 24-bit.
    Ethernet (was completely dead)
    - crc32.vhd: 7 of 32 XOR equations carried spurious terms (bits 10,11,12,16,
    17,22,23), so every frame left with a garbage FCS and the NIC discarded all
    of it silently. Verified "123456789" -> 0x649C2FD3, RX residue 0xC704DD7B.
    - udp_tx_core: tx_start was a pulse where the FSM needed a level; deadlocked.
    - arp_responder: byte 0 off-by-one. IP checksum corrected.
    - Result: ~12,000 packets/s, zero FPGA-side sequence gaps.
    I2C (had never once run)
    - i2c_mas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
    [stp1.stp, stp1_auto_stripped.stp, stp2.stp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]
2026-08-09 Fix TDM framing: merge fired 128x/frame, LRCLK launched on the ADC's own edge
    Four independent defects on the audio capture path, found while chasing 16
    channels that read exact zeros.
    tdm16_merge tested the LEVEL of the frame sync, not its edge. It was written
    when LRCLK was a single-BCLK pulse, where the two are the same thing. After
    LRCLK became 50% duty the level was true for 128 consecutive clocks, so
    tdm16_valid asserted 128 times per frame and flooded the FIFO. Measured
    packet rate was 18000/s against the 6000/s that fS/8 predicts. This is what
    made every channel table before it unreadable: samples were latched at
    arbitrary points in the frame, so channels appeared and vanished betwe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
2026-08-09 Add raw-TDM and chain-model tools, and guards for the mismatches that caused this
    check_sync grows from 31 to 42 checks. Every guard here exists because the
    corresponding mismatch actually shipped and cost hours:
    - LRCLK shape vs 0x06 bit 3 LR_MODE. tdm8_master sent 50% duty while
    tdm16_merge still level-tested a signal it expected to be one clock wide.
    - LRCLK launch edge vs 0x04 bit 6 BCLKEDGE. They must oppose, or LRCLK
    changes on the ADC's own sampling edge and setup time is zero.
    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
2026-08-09 Publish audio PLL lock loss, synchronise two stray debug bytes, split clock groups
    Clock-domain pass over the whole design with the vhdl-language checklist. 25
    processes scanned: no missing sensitivity entries, no clk'event, no process
    driven from two clock edges, no std_logic_arith anywhere, numeric_std only.
    Three real clock issues, all fixed here.
    pll_drop counted every time the audio PLL lost lock and was read by nothing.
    Quartus did not flag it because the counter feeds its own comparison. So the
    design had no visibility into the stability of the one clock MCLK, BCLK, LRCLK
    and the entire TDM frame derive from - and a full day of framing debug rested
    on "the PLL is stable", inferred fr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
2026-08-09 Fix udp_monitor mislabelling live channels as STUCK, and measure held samples
    classify() called "STUCK at <value>" whenever distinct == 1, but distinct was
    len(set(x[:4000])) - the first 4000 samples only, 83 ms of a 5 s capture. A
    channel held for the first 83 ms and live thereafter was reported STUCK while
    its own min/max/RMS showed it varying, and healthy channels flipped between
    "active" and "STUCK" between runs depending only on where the capture started.
    That is what made ch1-4 look like they were flickering. distinct now covers the
    whole capture.
    Added a real measurement in its place: the longest run of identical consecutive
    samples and the value held. This separates two faults that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
2026-08-09 Report where channel dropouts occur, not just how long the longest one is
    classify() reported only the longest run of identical samples, which cannot tell
    a single gap at capture start - an artefact of the socket buffer or the board's
    boot - from repeated dropouts through the run. It now reports the gap's position,
    how many gaps there are and what fraction of the capture is zero.
    That immediately separated the two TDM1 parts, which the previous output had
    lumped together as "held 167 ms" and "held 589 ms":
    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
2026-08-10 Report sub-window dropouts: timeline called a punctured channel "steady"
    rms_db tested np.all(x == 0) per window, so a channel only counted as absent if
    it was silent for the ENTIRE window. At 96 kHz a 0.25 s window is 24000 samples,
    so a part dropping out for 50 ms left 200 ms of audio, the test came back False,
    the window counted as fully live, and the channel was reported "steady".
    The user was watching mixer_gui, which decodes ~960 frames per update and so
    resolves about 10 ms, and could plainly see ch1-4 cutting in and out while
    timeline insisted they were steady. The GUI was right; timeline was 25x too
    coarse to see it, and I had used its "steady" verdict to claim U19 was fixed.
    Now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
2026-08-11 Correct the 192 x fS explanation: PWUP=0 powers the PLL down, so MCS is safe to write
    A bring-up note prompted re-checking this against the datasheet, and my earlier
    reasoning was wrong.
    I had claimed 192 x fS cannot work because changing MCS needs a PLL re-acquire
    that the ADAU1978 cannot perform - no PLL-enable bit exists and every reset also
    wipes MCS. Table 17 contradicts that: M_POWER enables "the boost regulator,
    microphone bias, PLL, band gap reference, ADC, and LDO regulator", and PWUP=0 is
    a Full Power-Down. The PLL is therefore OFF while PWUP=0, so writing MCS first
    and PWUP last - which BOOT_ROM already does - gives a clean acquire at whatever
    ratio is programmed. Reset defaults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
2026-08-11 192 x fS rejected on hardware; keep 256 x fS, and correct C_BIT_ADJ to 0
    192 x fS was retried properly after the datasheet showed my reason for rejecting
    it was wrong (PWUP=0 powers the PLL down, so writing MCS before PWUP is safe).
    The retry also had cfg_ok_i fixed, C_BIT_ADJ at its only legal value for 24-BCLK
    slots, and the falling-edge SDATA capture giving 33.6 ns of slack - the most this
    design has ever had.
    It still fails. Three consecutive runs at 18.4332 MHz with MCS=010: U19 locks,
    U20/U37/U38 read PLL_LOCK=0. All four lock every time at 24.576 MHz with
    MCS=011. Every candidate of mine is eliminated by measurement - cfg_ok_i fixed,
    adc_rst_n never re-asserted, FPGA PLL never lost l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
2026-08-18 newest, tested new ip for server mounting. tested in thinkpad now test in server
2026-08-19 Add imu_test.py: prove the AHRS is live, not just present
    The only IMU in this system is the aux_vcu's AHRS, arriving already fused
    as ulRaw[4..6] of the $GDAT2 sentence. gdat2.py already prints those three
    fields, which proves the link but not the sensor: all three ways an
    attitude source fails produce sentences that frame, checksum and format
    perfectly.
    frozen - identical raw u32 frame after frame. Compared on the bits, not
    the printed float; two decimal places hide exactly the dither
    that separates a live AHRS from a dead one.
    zero - decodes fine, reads 0.0 forever. One frame of that is
    indistinguishable from level and pointing north.
    shifted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
2026-08-19 Bind PLAUSIBLE to FIELDS, widen the frame buffer, exercise --listen
    PLAUSIBLE went in as an unguarded parallel array indexed in step with
    FIELDS - the exact divergence the surrounding code argues against, and
    the one the previous commit's message spends a paragraph on. It cannot
    fold into FIELDS without touching every unpack of it, so it is asserted
    against FIELDS at import instead: add a field and forget the bound and
    the module refuses to load, rather than silently reading the neighbouring
    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
2026-08-19 Point the default at buoy 3, the unit in service, and name the .131 decoy
    Operator confirms the sensor in use is 192.168.3.130 - buoy 3, already in
    the table. DEFAULT_HOST pointed at buoy 1 because it was first in the
    table, not because anything was there, so mixer_gui's default and a bare
    imu_test run both dialled a unit that is not in service. ACTIVE_BUOY now
    names the live one and DEFAULT_HOST follows it; a bare `python imu_test.py`
    dials it instead of printing help, which keeps the active address in one
    place rather than in everyone's shell history.
    Probing for it turned up something worth writing down. Nothing answers on
    .110/.120/.130/.140 from this bench - .130 fails at the ARP level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
2026-08-19 Say the waiting message once, not once a second
    A real run against the absent unit printed the same four-line hint six
    times in six seconds, with three "0 samples, need 10" rows between each -
    so the one line that actually changes, the link state, was buried in a
    screen of identical text. A tool that is waiting should be quiet enough
    that movement is visible.
    The repeat had a specific cause worth keeping out of the next version of
    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
2026-08-19 First real capture: link verified on hardware, AHRS is not live
    Reached buoy 3 at 192.168.3.130 and captured 399 sentences in 8 s with 0
    checksum errors, 0 parse errors and 0 counter gaps. Framing, checksum and
    field layout are now confirmed against the device instead of against the
    makers' example.
    The IMU check fired on the first window, and the field-by-field breakdown
    says why it is trustworthy: over 399 frames the three attitude fields held
    ONE bit pattern each, while ulRaw[0] took 172 distinct values dithering
    around 1.50 V and cnt incremented through all 256. The firmware is running
    and at least one ADC channel is genuinely sampling - the IMU is not.
    0x3F8CCCCD / 0x40466666 / 0x4331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
2026-08-19 Add the liveness column to the GUI, and a standalone single-file version
    Two things, both answering "is this in mixer_gui yet".
    The address change already reached the GUI on its own: --gdat-host defaults
    to gdat2.DEFAULT_HOST, so repointing that at buoy 3 repointed the tab too,
    and the buoy dropdown reads BUOYS. The CHECKS had not. The Telemetry tab
    showed roll/pitch/yaw as numbers with staleness, checksum and bad-hex
    handling but nothing about whether a value is being updated - the exact
    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
2026-08-19 Add mixer_gui_standalone.py, generated rather than hand-copied
    Asked for a standalone mixer_gui: no imports from other files in the
    directory. Installed libraries are fine, so numpy stays exactly as the real
    GUI uses it and only gdat2/ctrl/udp_monitor/imu_test are inlined.
    Generated, not written by hand. The file has to carry its own copy of the
    telemetry field map, the packet geometry and the gain law, and a
    hand-maintained copy of those is the precise defect this toolchain exists
    to catch: when the firmware adds a field, everything after it slides one
    place and the copy keeps printing believable numbers under the wrong
    headings. A regenerated copy cannot drift, and --check turns drift int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
2026-08-29 Adds an optional watchdog (C_PHANTOM_WATCHDOG, default false, 120 s) that drops 48 V if no flags-carrying packet arrives, for the crash and pulled-cable cases the host convention cannot cover.
2026-08-30 applied RMI's changes of IP and altimeter works perfectly, applied simple correction to Yaw pitch and roll values
2026-09-08 Fix the decimator's pipeline and schedule, and move the array to 192.168.3.x
    The decimator landed in 3fe34e7 with two bugs that neither synthesis nor
    timing analysis can see, and both would have produced a board that looks
    healthy and streams wrong data.
    **Pipeline misalignment.** Stage A registered the RAM data and the coefficient
    together, but stage B read the coefficient through a second register while
    reading the data through one, so every coefficient multiplied the wrong
    sample. Verified against a direct convolution: maxdiff 1,243,545,140 before,
    0 after. It would have appeared as noise on all 16 channels.
    **Schedule overrun.** The cycle budget assumed one cycle per tap; the ADDR/MAC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
2026-09-08 Make the mixer GUI follow each board's real address, and document host setup
    The GUI took ctrl.node_ip(n), so on a mixed array control went to the
    configured subnet while audio arrived from wherever the board actually was -
    faders silently doing nothing. The Receiver now learns the address via
    recvfrom (no extra socket, no port contention), Mixer.ip is a property over
    it, and the header shows it live instead of the value baked in at
    construction. GUI rate detection now uses npk + lost so heavy loss cannot make
    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
2026-09-14 Rewrite the README for the final, frozen firmware
    The README had drifted from the source. Corrected against the RTL and the
    build output rather than edited in place:
    - C_ENABLE_48V is true, not false. The table said phantom power was held
    off, which is the opposite of what ships.
    - The packet map was wrong in two places. Header bytes 8-9 are the SDATA
    edge counters, not a frame count; each frame's byte 0 is a diagnostic
    status byte, not the frame-index MSB. Byte 60 is the phantom readback
    and is now documented with its bit decode.
    - The wire frame is 456 bytes transmitted, not 454.
    - The power-up sequence called for an 18.432 MHz MCLK. It is 24.576 MHz.
    - check_sync.py runs 58 asser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
2026-09-14 Add the MIT license
    Copyright Faiz Akbar Parinduri, S.T. Covers rtl/, python/, sim/ and the
    documentation.
    The README's license section scopes it explicitly, because three things in
    the tree are not ours to relicense: the two Altera megafunctions under ip/,
    the Analog Devices datasheet in docs/, and the board schematic and netlist
    in hardware/.
2026-09-17 Add claw actuator control, and vendor HACAR_dash's Device Status window
